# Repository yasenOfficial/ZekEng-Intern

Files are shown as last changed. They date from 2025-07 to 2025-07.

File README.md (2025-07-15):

# Цел на стажа:

Да се направи симулация на вече направена платка за контролиране на вентилатор. Платката гори често и има нужда от оптимизация. Дадени са файлове за Reverse-engineering в `/Files for Reverse Engenieering`

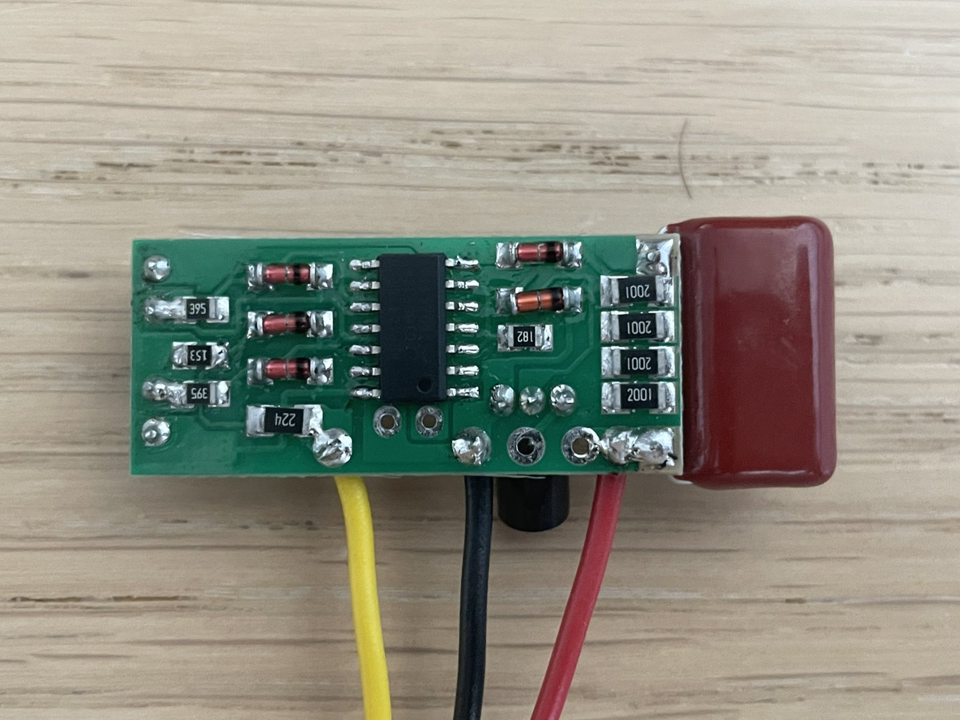
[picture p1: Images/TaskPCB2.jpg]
TaskPCB2

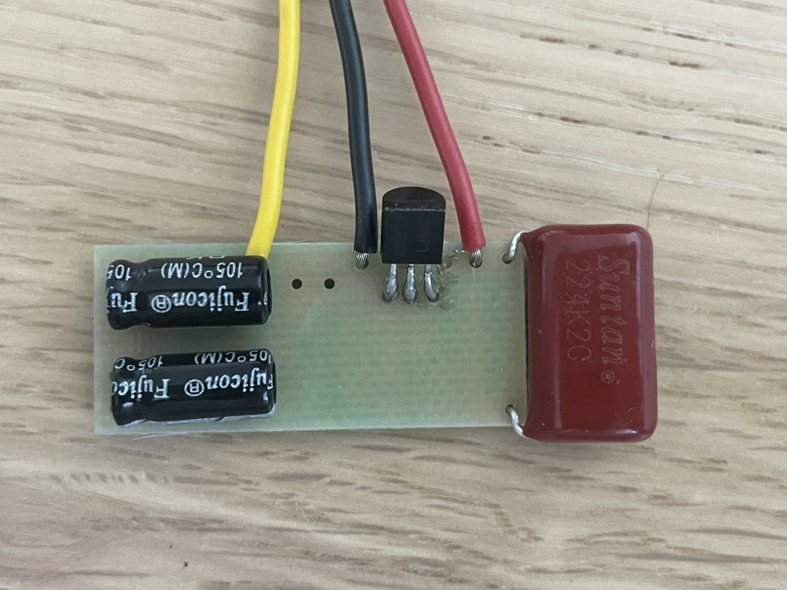
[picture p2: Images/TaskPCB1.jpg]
TaskPCB1


# Ден 1 - 01.07.2025

Запознанство с екипа

Разучаване LTSpice от огромния Роман (Следване на Tutorial-a)

Тutorial-a.......
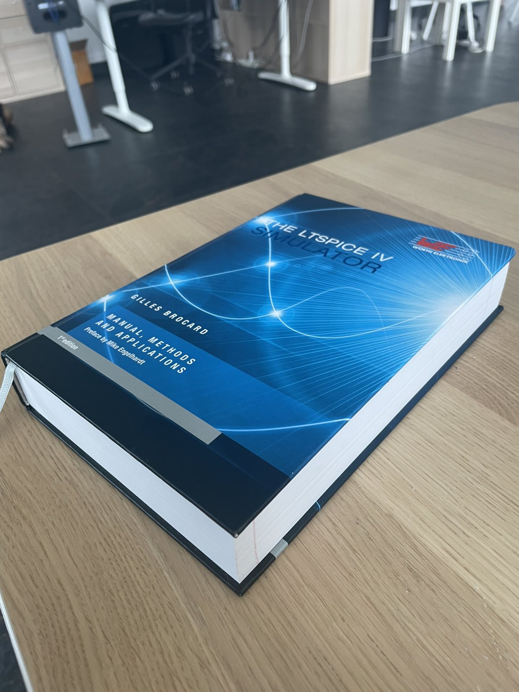
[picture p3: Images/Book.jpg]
Tutorial Book


Работна директория: `LTSpice Files/TutorialRoman.asc`

Покрито в Tutorial-a:
- Поставяне на компоненти
- Свързване
- Поставяне на стойности на компонентите
- Директиви
- Анализ на сигнали

Описание на директивите

## Честотен анализ (.ac)

Изпраща много бавен и много бърз синус (от 1 kHz до 10 MHz) през схемата и измерва колко усилва тя и с колко закъснява сигналът.

`.ac dec 50 1k 10Meg`

dec 50 – логаритмична скала с 50 точки за всяка декада. Т.е. първо разглеждаме честоти от 1 kHz до 10 kHz (1–10 kHz), после от 10 kHz до 100 kHz, после от 100 kHz до 1 MHz и т.н.

1k – начална честота 1 kHz

10Meg – крайна честота 10 MHz

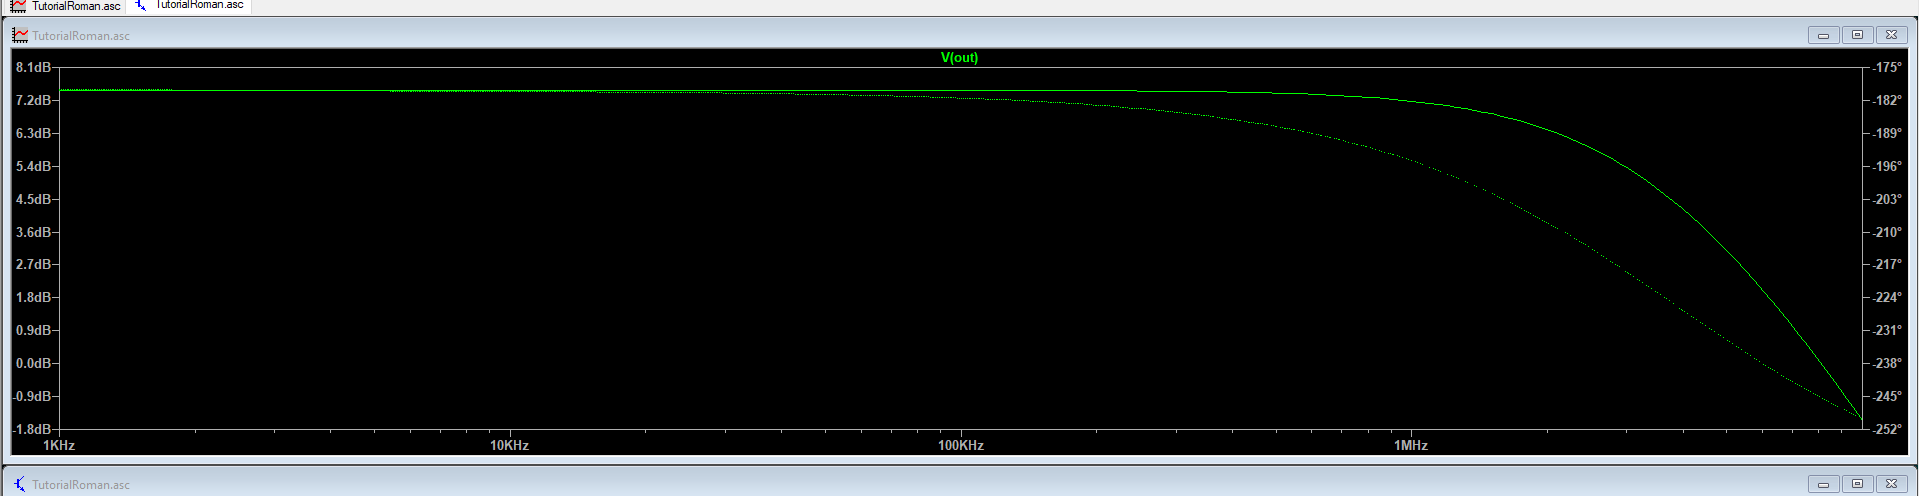
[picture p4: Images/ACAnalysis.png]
ACanalysis


## Транзиентен анализ (.tran)

Проследява как се променят напреженията и токовете във времето (от 0 до 300 µs), записвайки данни след първите 100 µs.

`.tran 0 300u 100u 0.01u`

0 – автоматичен интервал за записване на резултатите

300u – крайно време на симулация 300 µs

100u – начало на записването от 100 µs

0.01u – максимална стъпка 0.01 µs

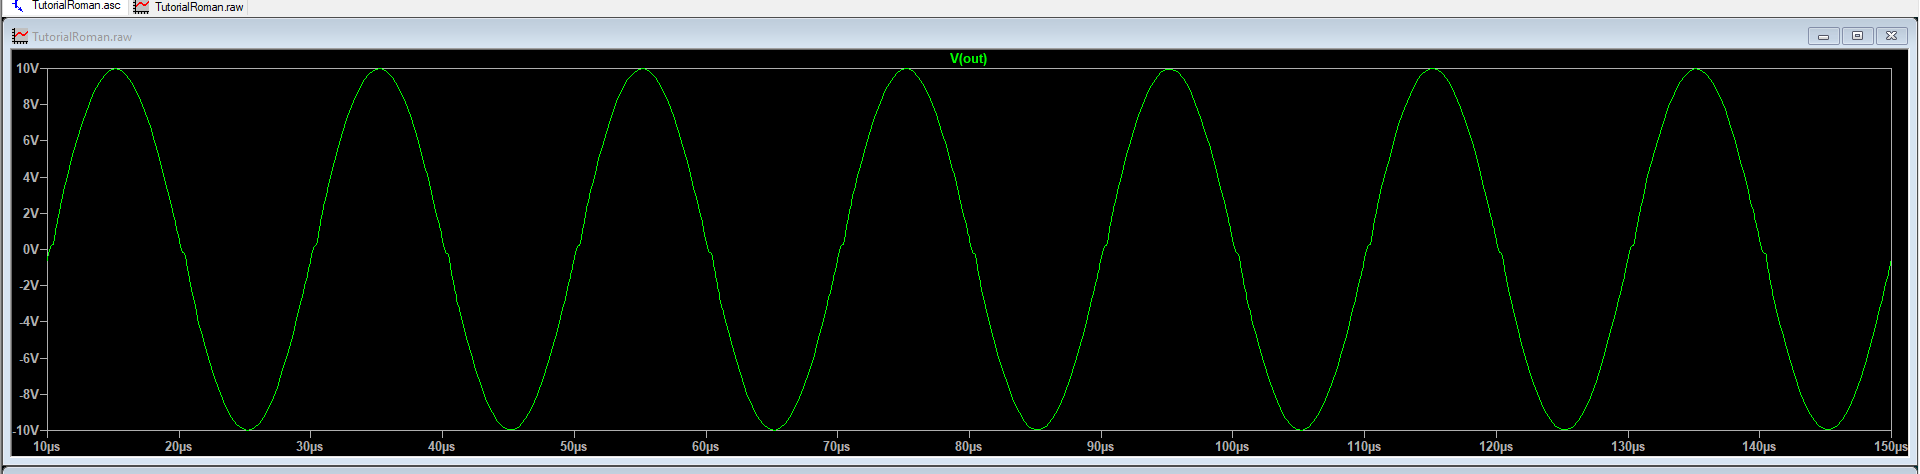
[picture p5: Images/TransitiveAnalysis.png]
TransitiveAnalysis


## Фурие-анализ (.four)

- Взима резултата от временния анализ и го разгражда на отделни синусови вълни (хармоници), за да видим колко „чист“ е сигналът на 500 kHz.

`.four 500k 10V(out)`

500k – основна честота 500 kHz за хармоничен анализ

10V(out) – (10 V при основния хармоник на изхода)

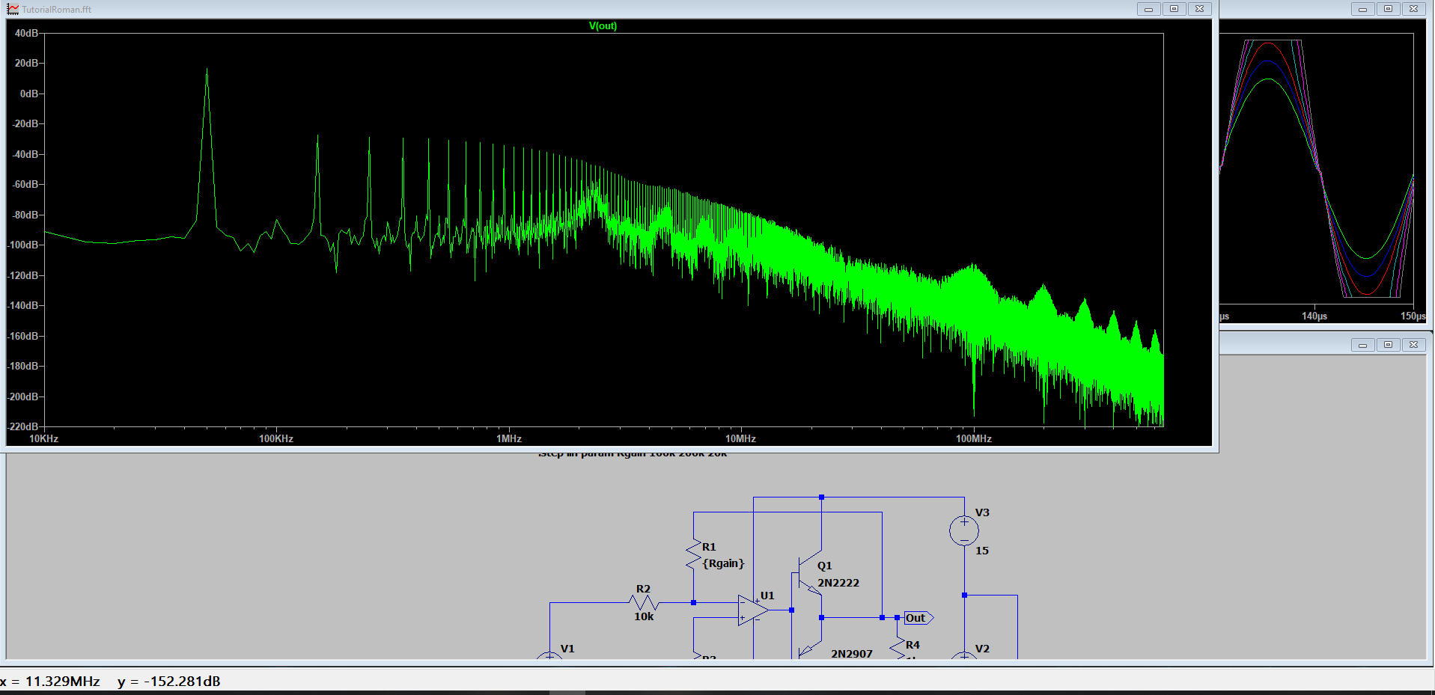
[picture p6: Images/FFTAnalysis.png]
FFTAnalysis


## Параметрично стъпково преминаване (.step)

-  Променя автоматично стойността на резистор Rgain (100 kΩ, 120 kΩ, 140 kΩ… до 200 kΩ) и за всяка стойност пуска пак AC, транзиентен и Фурие-анализите.

`.step lin param Rgain 100k 200k 20k`

Променя стойността на параметъра Rgain от 100 kΩ до 200 kΩ на стъпки по 20 kΩ

За всяка стойност се повтарят горните анализи

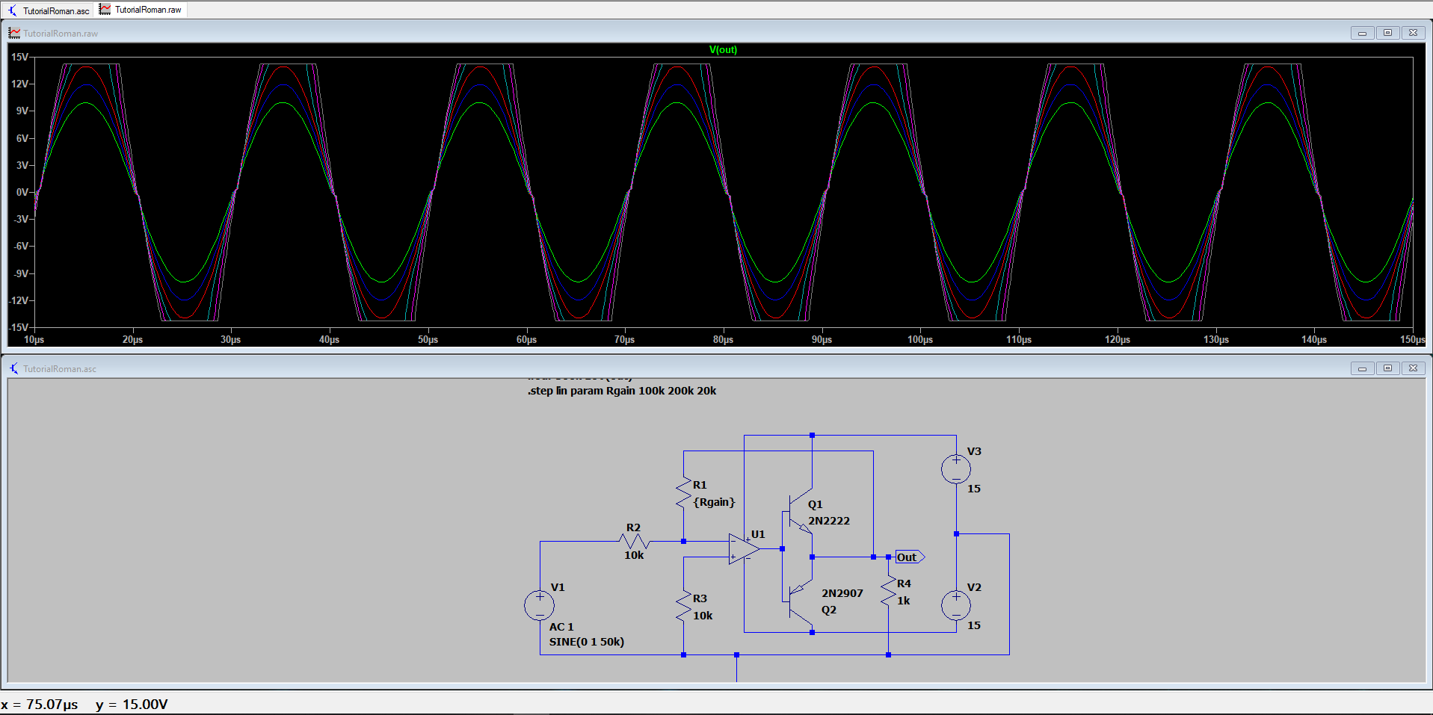
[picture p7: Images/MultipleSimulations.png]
Multiple Simulations


## Идентифициране на дефект

След стартиране на транзиентен анализ в определен момент изходният сигнал се отклонява от очакваната синусоида:

Наблюдение на графиката: Обръща се внимание къде сигналът изкривява или има рязка промяна на наклона.

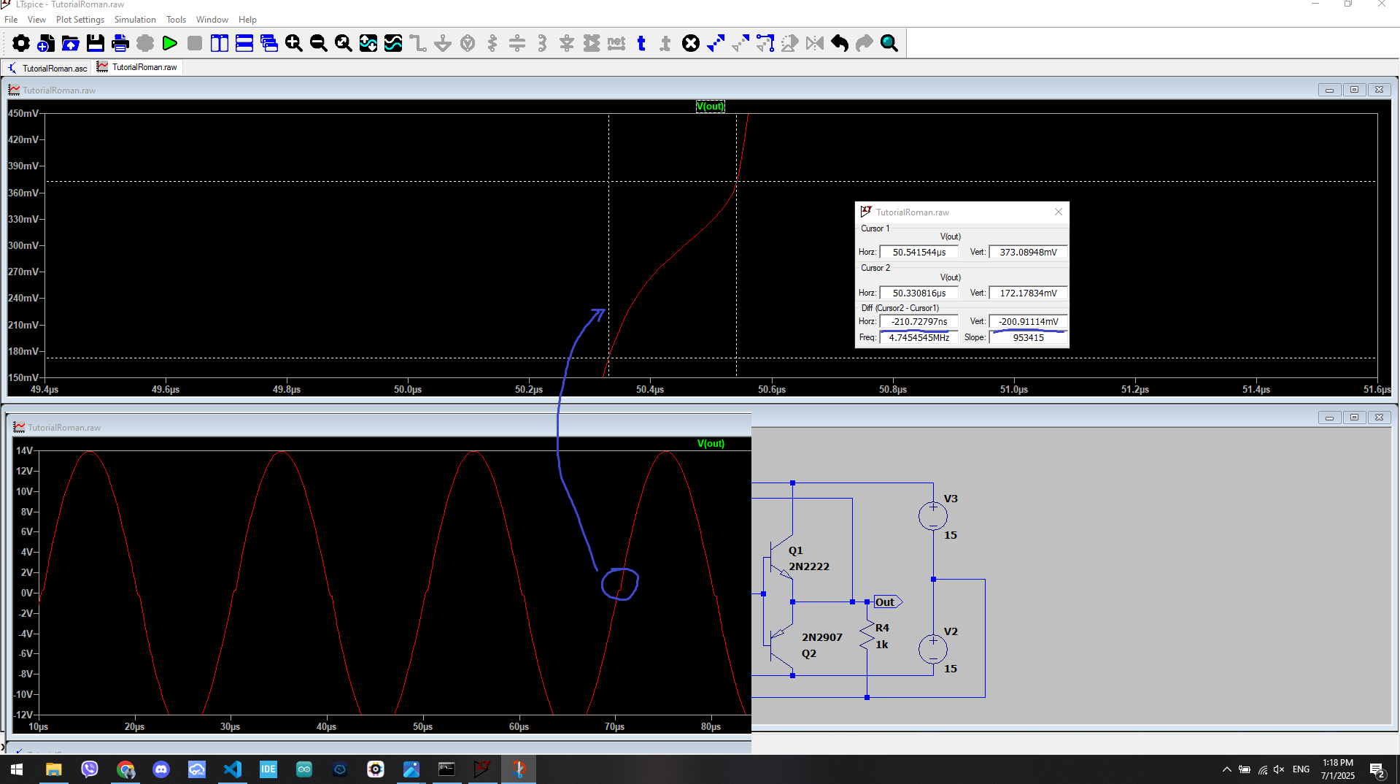
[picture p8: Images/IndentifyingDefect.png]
IndentifyingDefect


Измерване с курсори: Поставят се два курсора преди и в началото на аномалията, за да се изчисли промяната във времето и напрежението.

На операционния усилвател му отнема измеримо време за да покрие съществуващия пад на напреженеие между сумирания VBE на 2та транзистора Q1, Q2

Извод: 3тия сигнал (от 6-те) е минималния приемлив (R1 = 140k) с амплитуда 14V

# Ден 2 - 02.07.2025

## Импортиране на CD4000 серията в LTSpice

`Ventilator\lib\sym\*` `Ventilator\lib\sub\CD4000.lib` 

https://www.amarketplaceofideas.com/adding-series-4000-cmos-library-to-ltspice.htm

## Тестове на NAND 4093B gate

`Ventilator\NAND Tests.asc`

Проведох прост дали NAND gate-a от библиотеката работи със синусоида с амплитуда 12 V

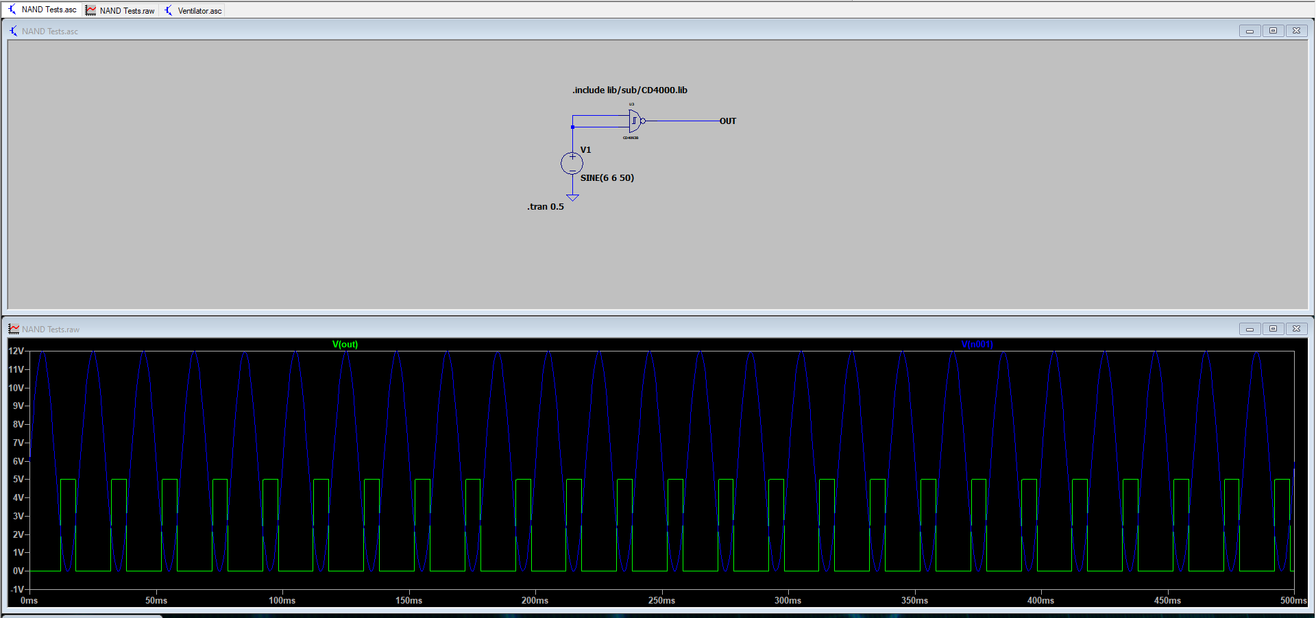
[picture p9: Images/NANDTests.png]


## Тестове и разбиране как работи SW gate-a в LTSpice

Следвах Tutorial-a на Analog Devices:

`Ventilator\SW.asc`

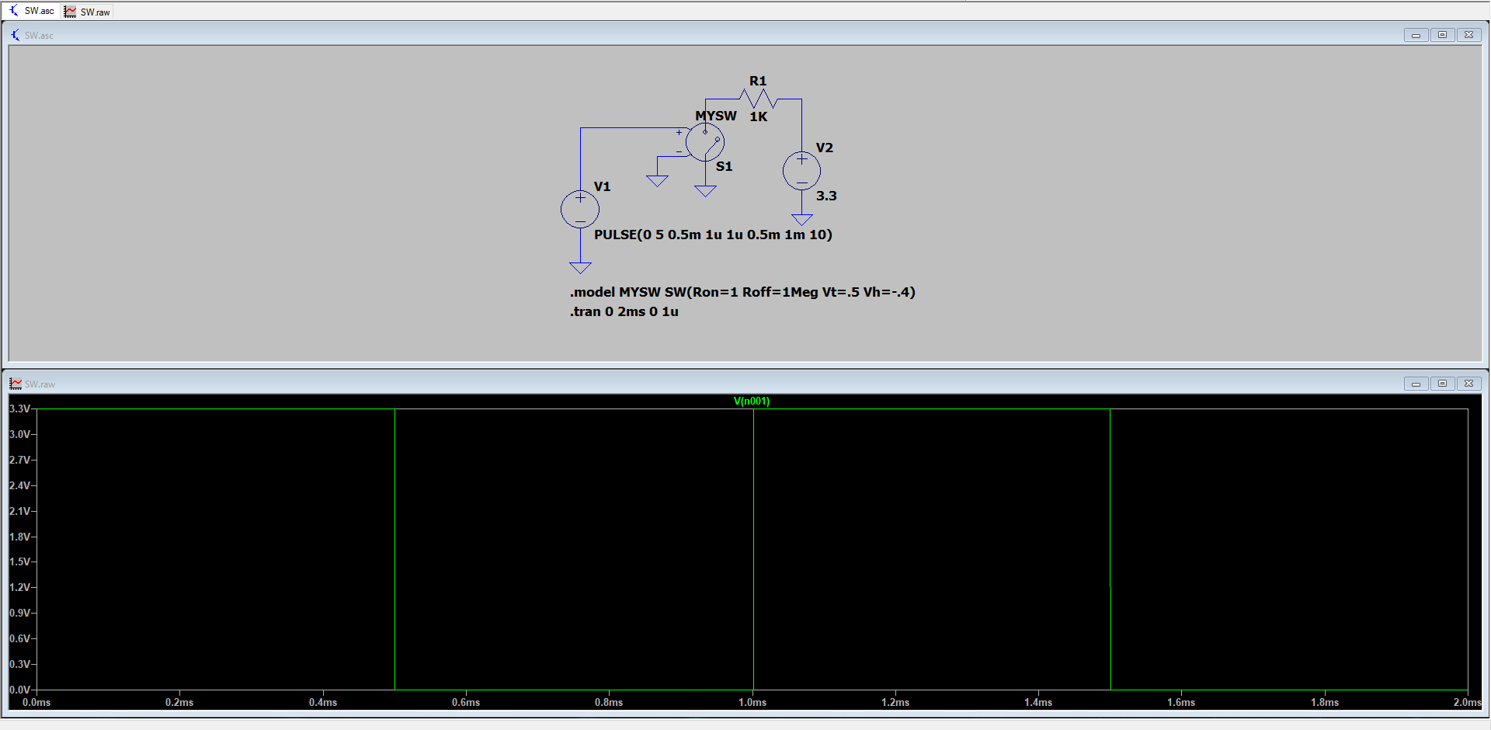
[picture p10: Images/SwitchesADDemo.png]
Switches Demo Implementation


И после направих подобна моя имплементация с резисотри вместо импулсен генератор:

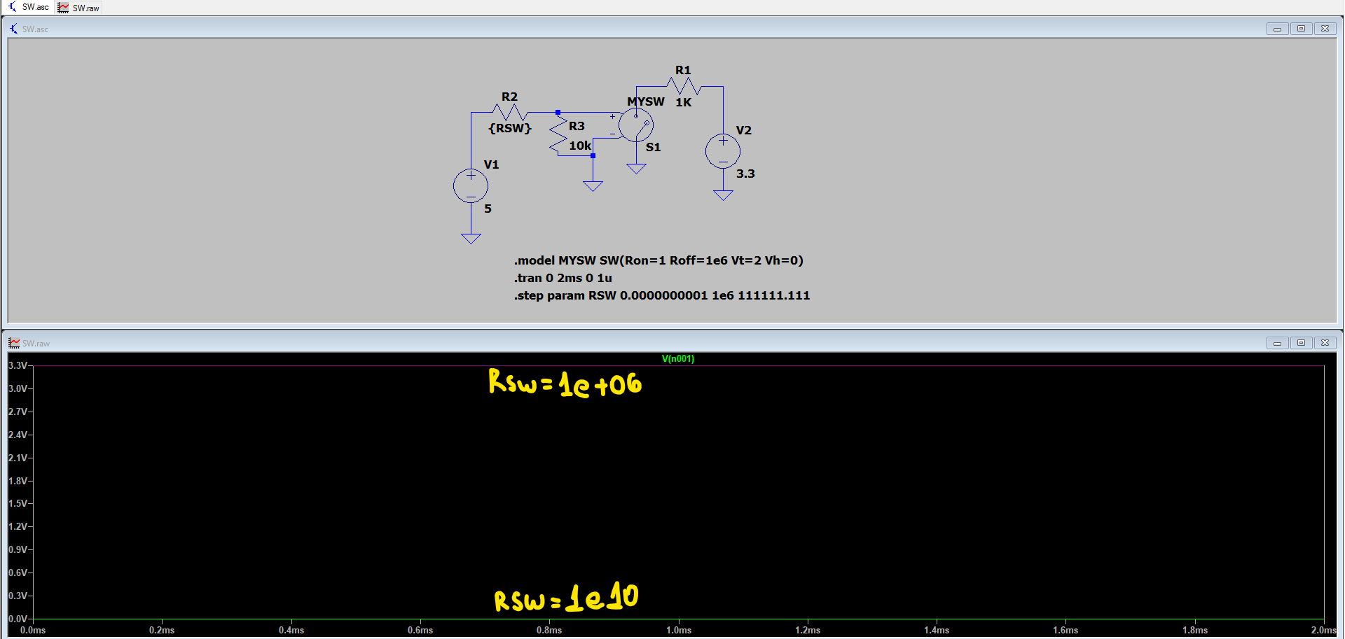
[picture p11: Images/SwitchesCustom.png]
Switches Custom Implementation


## Импортирах и библиотектата с симистора (MAC97A8), който е сложен на платката

`Ventilator\lib\sub\thyristr.lib` 

https://github.com/HMGrunthos/InrushTimer/blob/master/thyristr.lib

## Teстване на захранването на схемата:

`Ventilator\PMU.asc`

Захранвaнето се стабилизира за около 160ms докато стигне 11.3V. После лека полека се покачва до 11.6 в рамките на до 2 секунди

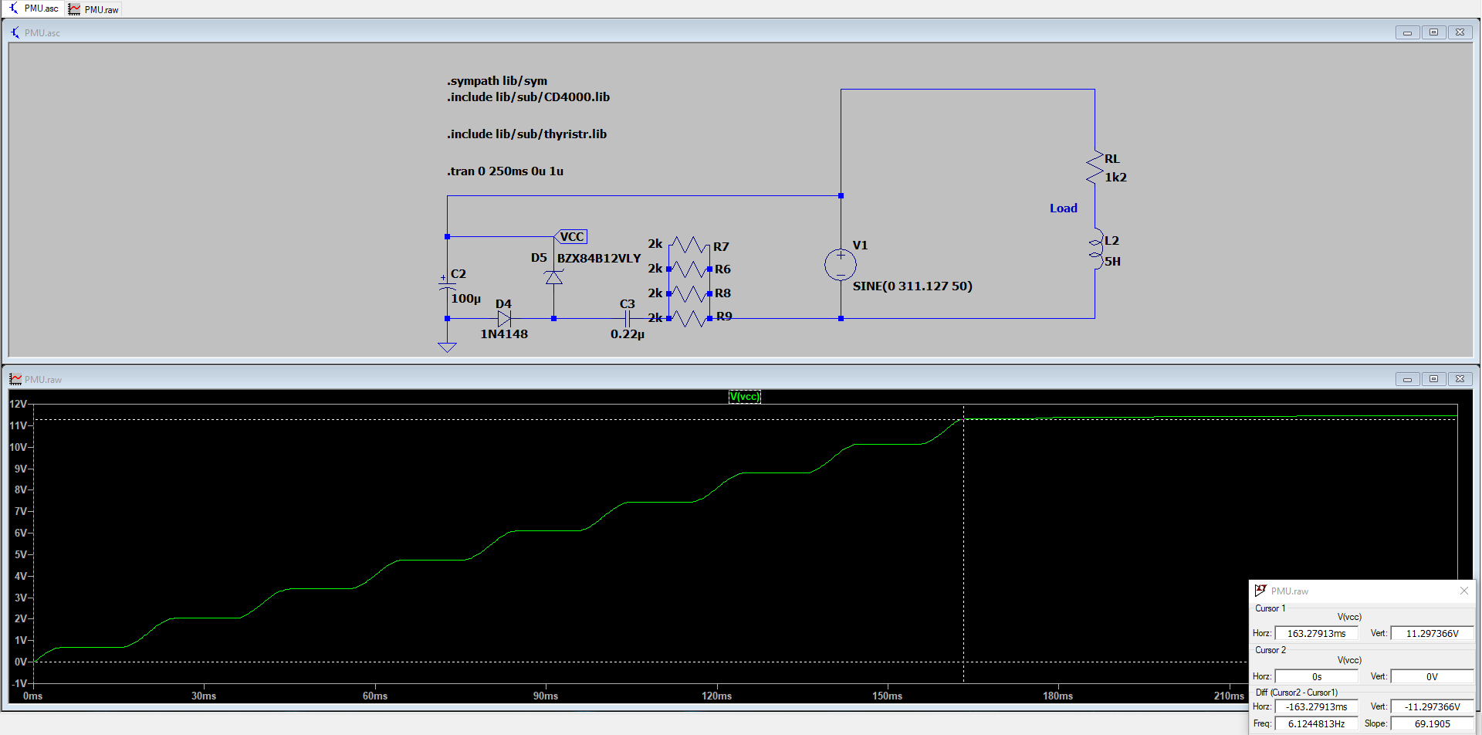
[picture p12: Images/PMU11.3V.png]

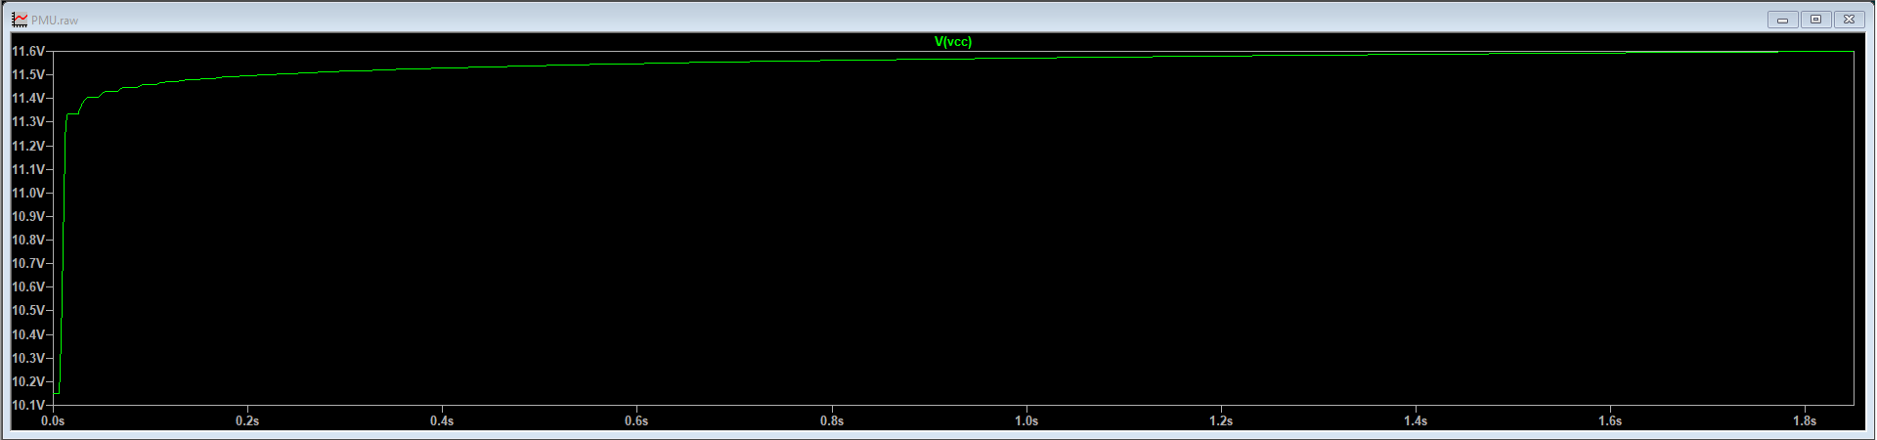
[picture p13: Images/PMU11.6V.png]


Параметри на проблемния кондензатор:

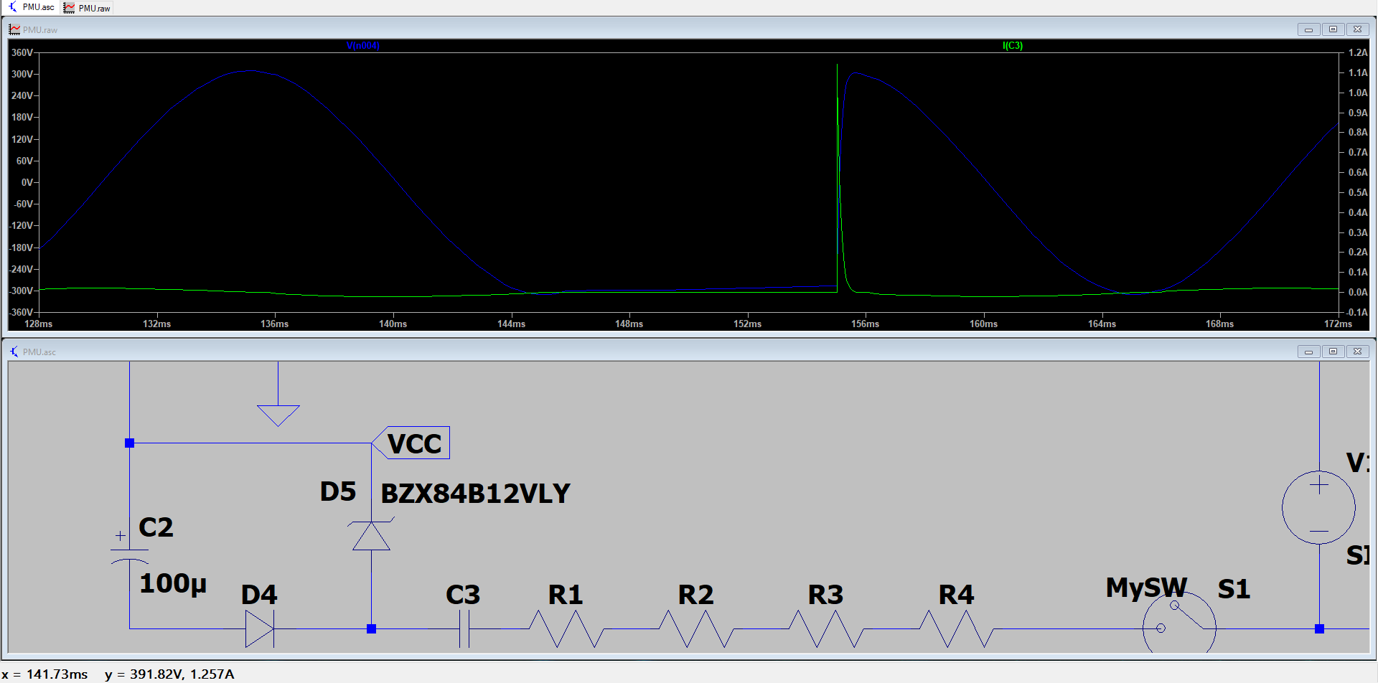
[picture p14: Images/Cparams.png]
C params


Pulse current: Rated for 2 A rms at 1 kHz → Доста повече от 1.2 A
https://www.mouser.bg/ProductDetail/WIMA/FKP1R022205H00KYSD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

Параметри на проблемните резистори:

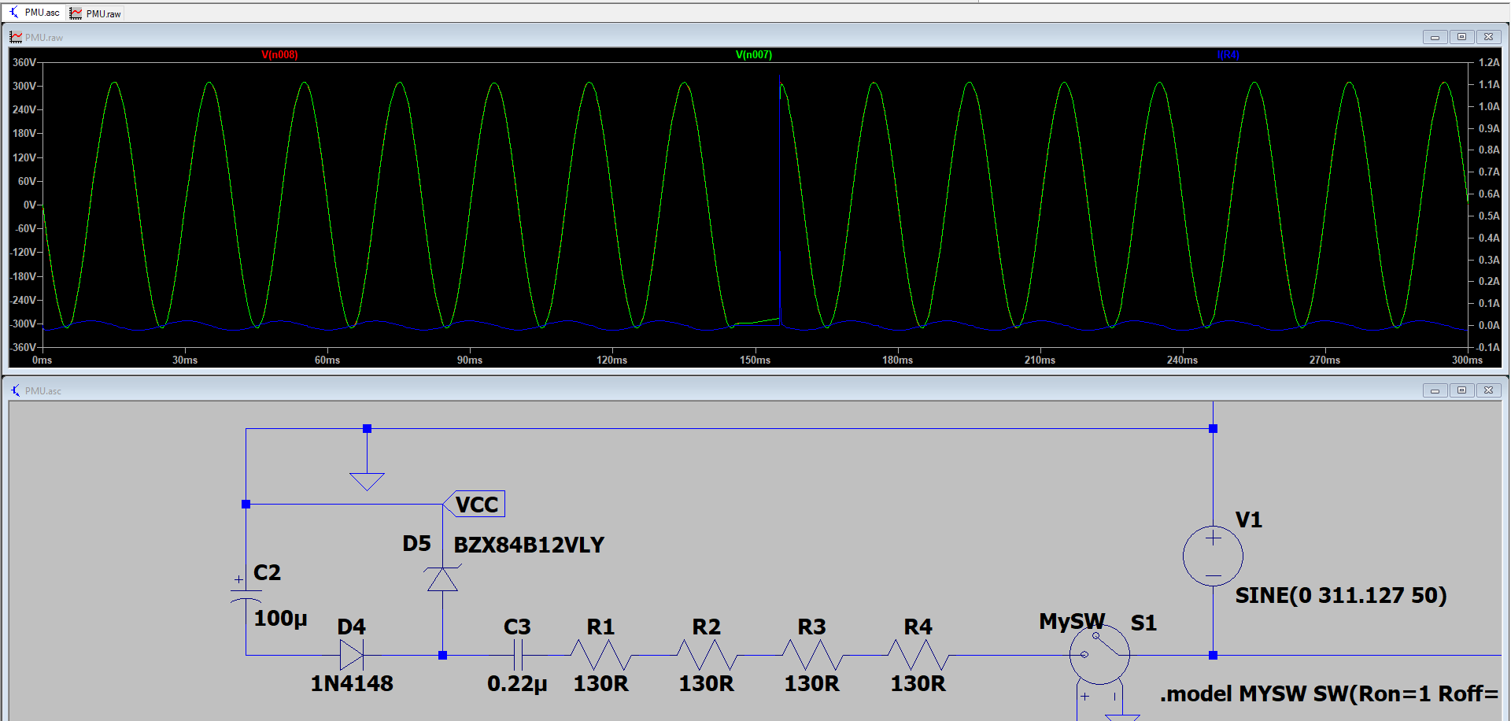
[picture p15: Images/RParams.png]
R params


https://www.mouser.bg/ProductDetail/ROHM-Semiconductor/ESR18EZPJ131?qs=493kPxzlxfJ2i%2Fymb6BOsw%3D%3D

# Ден 3 - 03.07.2025

Започната е работа по схемата:

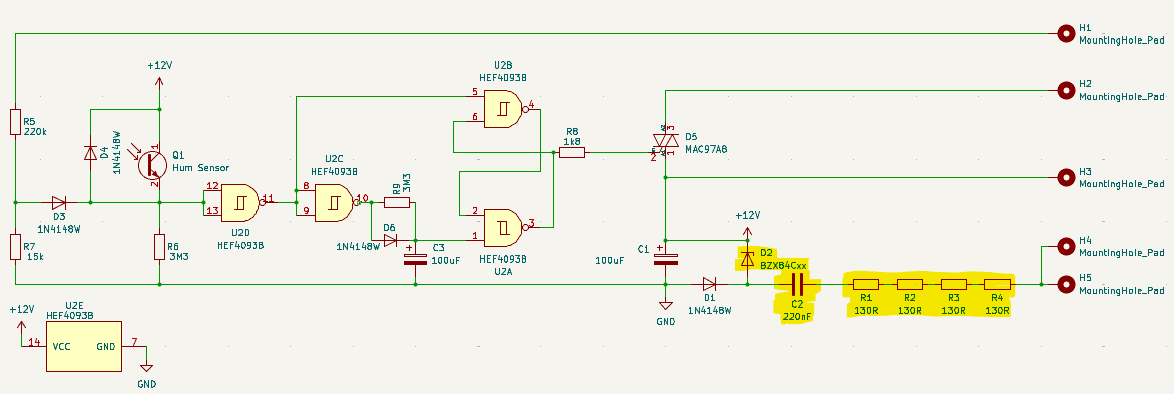
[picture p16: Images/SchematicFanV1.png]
SchematicFanV1


- сменен е 220nF-овия кондензатор, избрания от вчера (02.07.2025 се оказва голям за платка (трябва да се събера в 14.5mm x 32.5mm))

https://www.mouser.bg/ProductDetail/WIMA/MKP4J022203C00KI00?qs=sJjjjplDs9tWJMp1Tfr4Pw%3D%3D

- сменена е топологията на резисторите (вече са последователни, а не паралелни)
- избран е нов ценеров диод, тъй като стария е неизвестен

Започната е работа по платката:

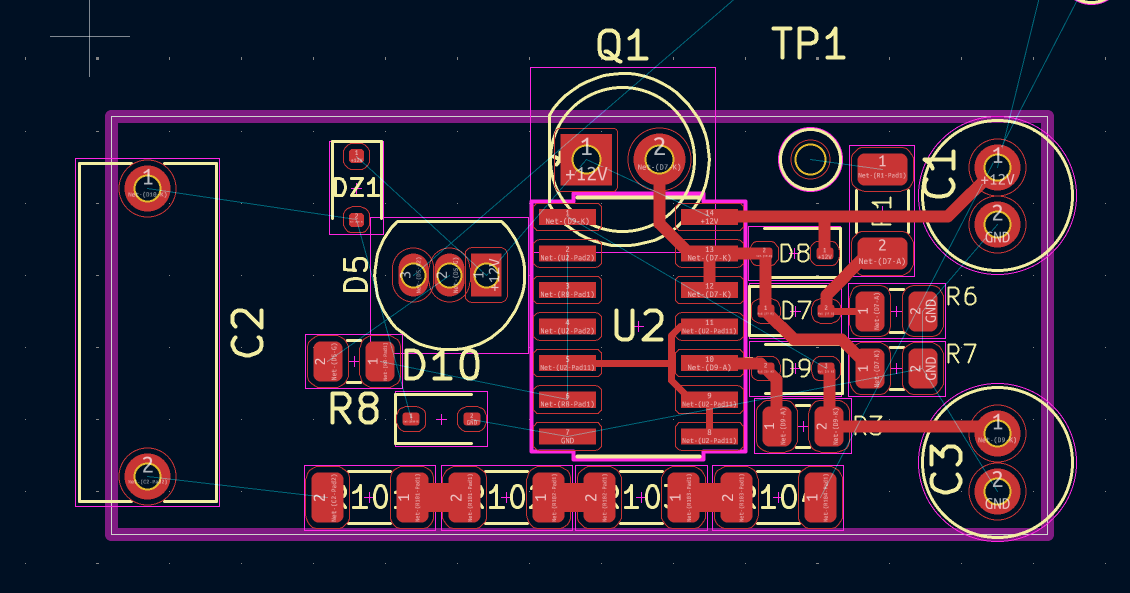
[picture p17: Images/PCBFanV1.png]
PCBFanV1


Начерах Custom TP, Diameter 2.0mm, drill 1.0mm, Pad само на свързана страна
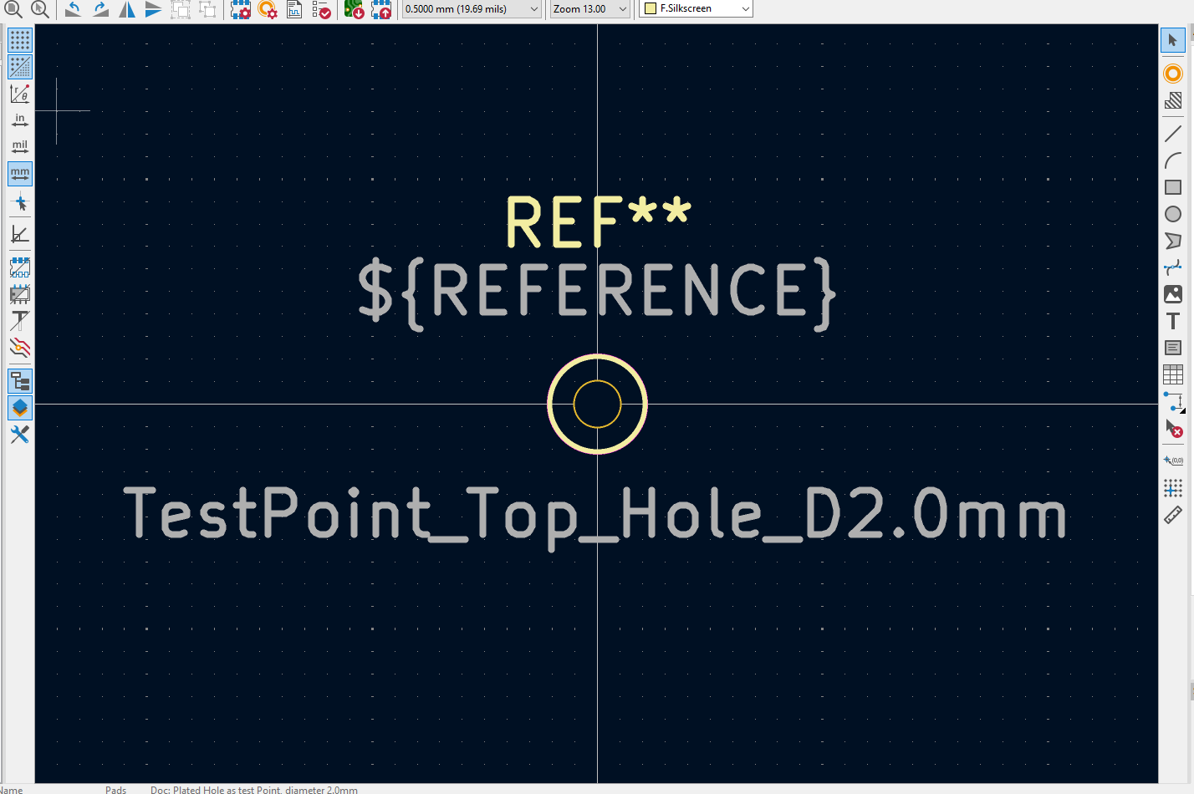
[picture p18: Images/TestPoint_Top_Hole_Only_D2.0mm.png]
TestPoint_Top_Hole_Only_D2.0mm


Платката и схемата за предадени за обратна връзка на екипа от ЗекЕнг, със сигурност трябва да се добави медна зона за земя (GND) и да се оправи place-ment-a на резисторите R21, R22, R23, R24
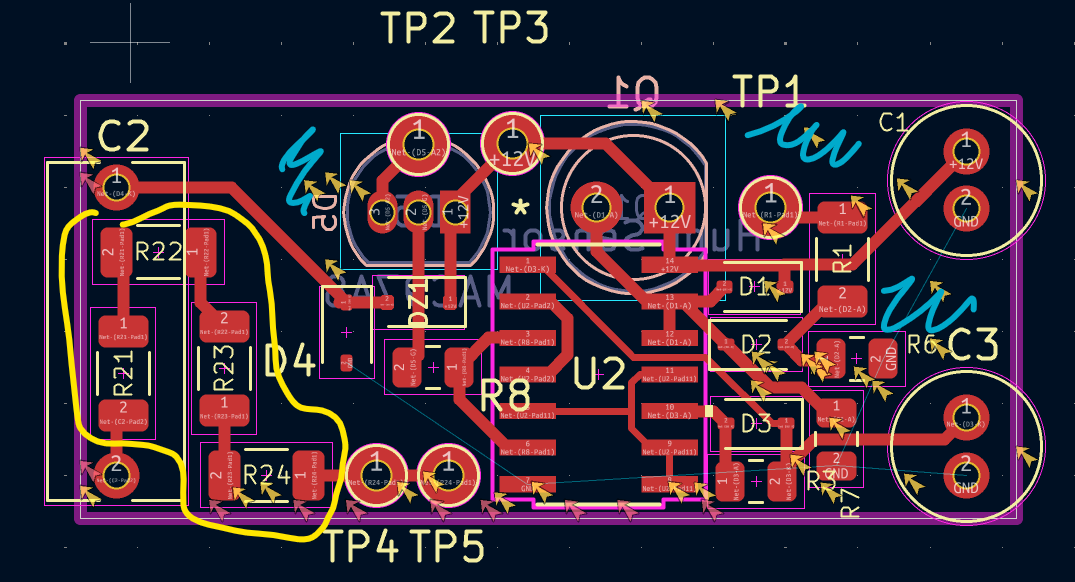
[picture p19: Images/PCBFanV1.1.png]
PCBFanV1.1


(Това е много бърза версия на платката)

Oбратна връзка:

- Да се начертае как ще легнат кондензаторите 2x (100uF)
- Да се сложат кондензаторите от другата страна 2x (100uF)
- Да се оправи символа и footprint-a на Hum Sensor-a, за да изглежда по-добре
- Да се оправят R21, R22, R23, R24 (Да се внимава с напрежението там)
- Да се направи TP с 1.8mm Diam. x 1.1 Drill
- Да проверя pinout-a на симистора
- Засега да изчакам с медните зони (може и просто да свържа земята на ръка)
- Очаквам Feedback за избрания кондензатор и ценер

# Ден 4 - 04.07.2025

~~ - Да се начертае как ще легнат кондензаторите 2x (100uF) ~~
~~ - Да се сложат кондензаторите от другата страна 2x (100uF) ~~
~~ - Да се оправи символа и footprint-a на Hum Sensor-a, за да изглежда по-добре ~~
~~ - Да се оправят R21, R22, R23, R24 (Да се внимава с напрежението там) ~~
~~ - Да се направи TP с 1.8mm Diam. x 1.1 Drill ~~
- Да проверя pinout-a на симистора 

- Кондензатора имаше грешка бях избрал 0.022uf (22nf) вместо 0.22uf (220nf)
- Ценера е добре

Платката е приключена, предавам за проверка и обратна връзка:

- начертан е нов footprint за 220nf-вия кондензатор, за да може да support-ва няколко различни корпуса. (3D модела е също съответно променен)
- начертан е нов footprint за 100uf-вите кондензатори, за да се види как ще изглеждат реално като са легнали. (3D модела е също съответно променен)

- компонентите са пренаредени, за да може падовете за връзка с вентилатора да не са под 100uf-вите кондензатори
- сменен е модела на 220nf-вия кондензатор (да не е 22nf) - https://www.mouser.bg/ProductDetail/WIMA/MKP4J032204J00KSSD?qs=sJjjjplDs9tNFMTkeYgn1g%3D%3D

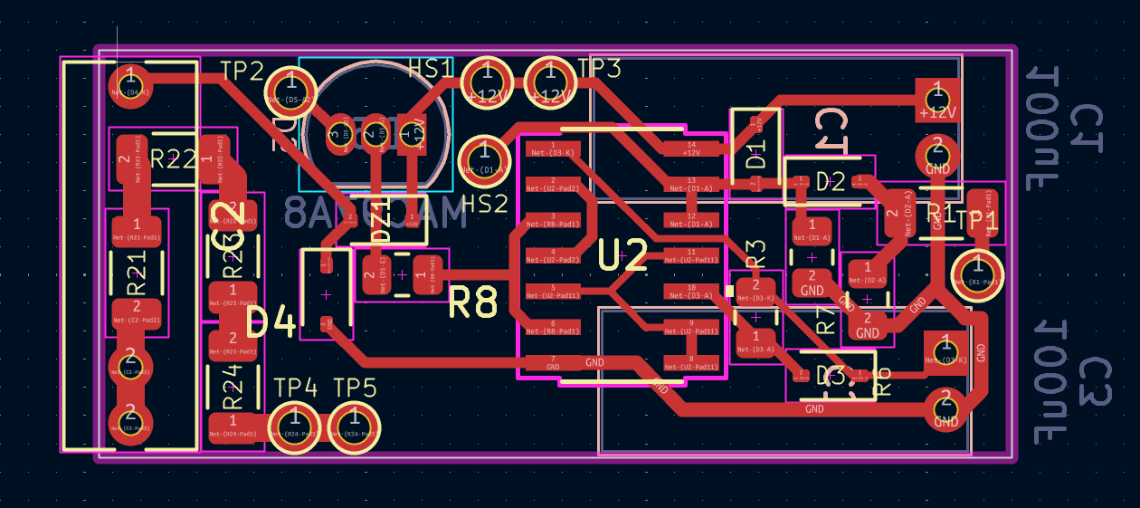
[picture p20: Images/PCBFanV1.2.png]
PCBFanV1.2

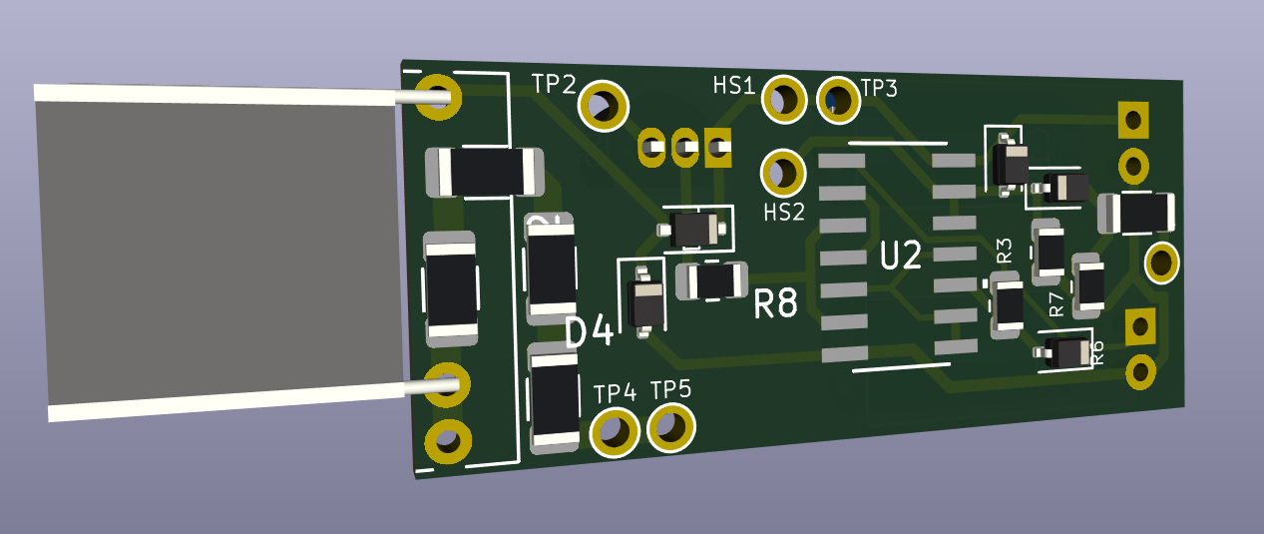
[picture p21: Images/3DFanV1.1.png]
3DFanV1.1

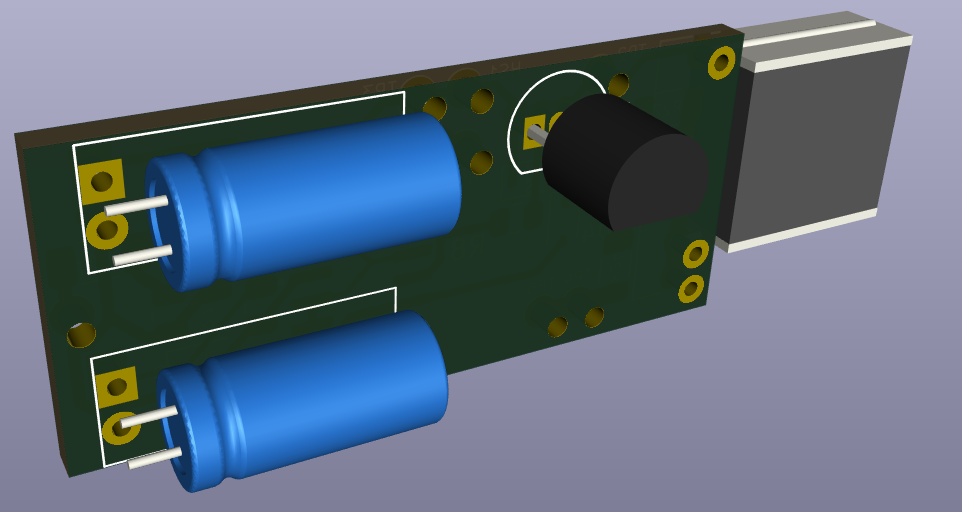
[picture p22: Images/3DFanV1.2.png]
3DFanV1.2


# Ден 5 - 07.07.2025

Проверих pinout-а на симистора. Оказа се грешен. поправих го.
Експортирах файлове за fabrication - `Gerbers.zip`
Платката беше пусната за производство в hardtech.

Също така оформих Bill of Materials, за да се поръчат компоненти. Пуснат е на екипа от ЗекЕнг.

Изчислих цената на платка при прозизводство на 25 платки (сегашния прототип) и при 1000 платки (масово производство).

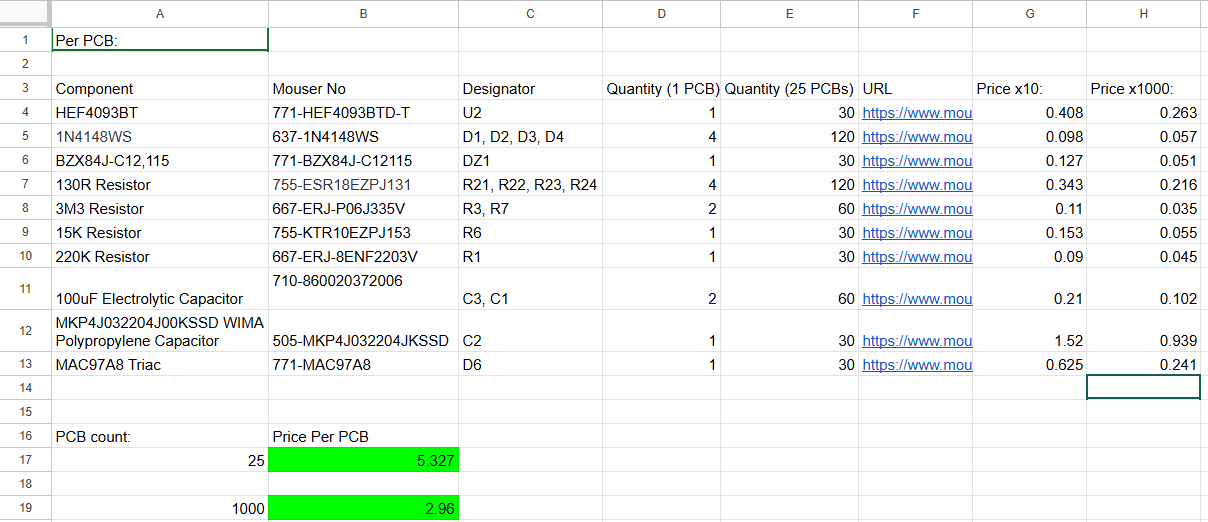
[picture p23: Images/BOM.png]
BOM


Нужно е подобрение на сегашния сензор за влага. Той работи на принципна на мерене са съпротивление.
В момента е покрит с латекс. Латекса се мие и не издържа на влага. Наложи се да направя research и според мен материала, с който трябва да се покрие сензора е полимид, защото е хидрофилен материал.
Интересното е че flex-PCBs се правят от полимид, но тогава сензора би станал много скъп.

# Ден 6 - 08.07.2025

Още research за материала за сензора:

`HumSensorResearch/Polyaniline_based_impedance_humidity_sen.pdf`

PANI ^, материала е скъп и прави твърде голямо съпротивление, но иначе изглежда като нелошо решение.

https://www.conservationlabinternational.com/product-page/polyvinylalcohol-pva

Другия вариант е този тип алкохол.

Оказва се, че платката би била най-издръжлива ако е направена от карбон

Сензора трябва да е от е със номинално съпротивление 1.8Mohm и при 100% влажност трябва да падне на 1Mohm (Измервания от сегашния сензор)

Докато чакаме платките да се произведат имам задачата да подкарам този dev board и да направя audio reverb effect.

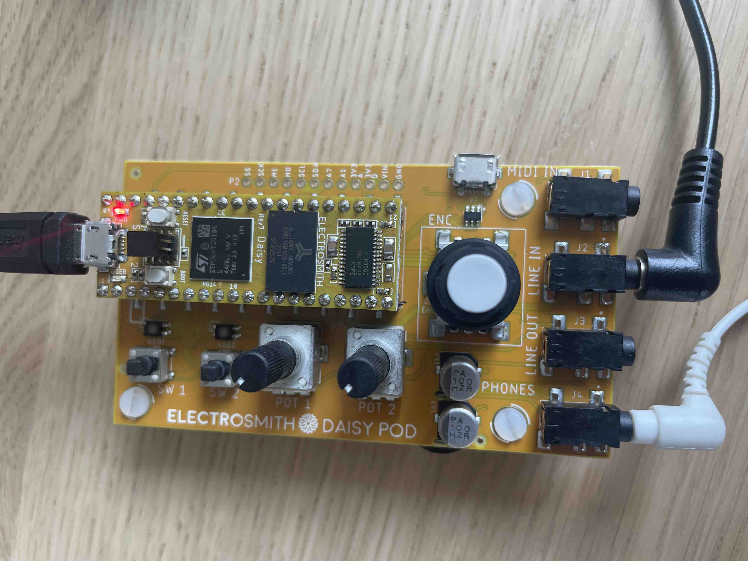
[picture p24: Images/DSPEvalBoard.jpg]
DSPEvalBoard


Следвам setup guide-a:

https://daisy.audio/tutorials/cpp-dev-env/#4a-flashing-daisy-via-usb

Blink:

https://github.com/user-attachments/assets/fd17b43d-5868-410e-99cb-3dca0cbfa887

# Ден 7 - 09.07.2025

Продължение с DSP-то:

Написах output на прост сигнал с Reverb - `DaisyExamples/pod/Reverb`

https://github.com/user-attachments/assets/809b711f-6c32-4bfa-b9f2-1e61ffa9d363

Написах Passthrough (Минава сигнал от компютъра без processing през платката и го изкарва на слушалките) - `DaisyExamples/pod/Passthrough`

https://github.com/user-attachments/assets/3d5a9c95-f11f-47a7-a7cd-25c1624e9f36

Написах Passthrough Reverb (Минава сигнал от компютъра с reverb през платката и го изкарва на слушалките) - `DaisyExamples/pod/PassthroughReverb`

https://github.com/user-attachments/assets/ea0f91bf-7a43-4274-871f-e3ecebe81c51

Започвам research-a по конволуции. Това видео доста помогна: https://www.youtube.com/watch?v=KuXjwB4LzSA

Каква е целта?

Трябва да се вземе .wav от интеренет на Impulse Response и да се симулира чрез DSP-то същата конфигурация на входния сигнал.

В `DaisyExamples\pod\Convolution\mono files` има качен `tunnel_entrance_f_1way_mono.wav` - това е Impulse Response-a

Run-ваме тази команда:

```sox tunnel_entrance_f_1way_mono.wav -r 48000 -b 24 -c 1  tunnel_entrance_48k.wav  gain -n -3  rate -v```

- Прави output sample-rate-а на 48 000 Hz - (native rate-a на Daisy платката).
- Пикова амплитуда –3 dBFS
- Resample-ва с най-high-quality filter-a на SOX

и получавам `out48.wav`

Ще използвам този файл за конволуция на входа.

----------------

Странен проблем. При няколко serial print-a замръзва и принтира само първия. Сигурно трябва да се изчака или да се flush-не buffer-a.
```
hw.PrintLine("A");
hw.PrintLine("B");
hw.PrintLine("C");
hw.PrintLine("D");
hw.PrintLine("E");
```

fix:
```hw.DelayMs(1);```

Не мога да mount-на SD картата като хората - не мога да достъпя IR/out48.wav да го прочета

```
DIR     dir;
        FILINFO fno;
        if(f_opendir(&dir, "/IR") == FR_OK)
        {
            while(f_readdir(&dir, &fno) == FR_OK && fno.fname[0])
            {
                hw.PrintLine("File: %s", fno.fname);
            }
            f_closedir(&dir);
        }
        else
        {
            hw.PrintLine("Failed to open /IR");
        }
```

Намирам `File: out48.wav` като list-на Dirs, но не мога да го прочета като хората.

----------------

Изникна по-спешна задача - наложи се да се разглобя друг вентилатор и да видя какъв е сензора вътре, за да се използва същия в моята платка, вместо да търсим адекватен хидрофилен материал за покритие.

![HR202](https://github.com/yasenOfficial/ZekEng-Intern/blob/main/Images/HR202.jpg)

Това е сваления сензор ^

Проблема с хидрофилния материал е, че никъде не е записано съпротивлението спрямо площта на покритие при дадена дебелина на нанасяне.

Затова сменихме концепцията и поръчахме този сензор.

https://lcsc.com/search?q=HR202&s_z=n_HR202

# Ден 8 - 10.07.2025

Наложи се да имплементирам собствена flush функция за буфера за принтиране и да прекомпилирам libDaisy съответно.

```logger.h

    static void Flush();
```

```logger.cpp

template <LoggerDestination dest>
void Logger<dest>::Flush()
{
    if(tx_ptr_ > 0)
    {
        TransmitBuf(); // will send and clear the buffer
    }
    // Ensure buffer is cleared, even if transmission failed.
    tx_ptr_ = 0;
}
```

Вече имам нормални принтове:

```
f_open succeeded!
First 16 bytes, read 0 bytes:
```

Но не чете байтове от файла ми. Тествах `pod\WavPlayer\WavPlayer.cpp` и работеше. Ще се опитам да репликирам подобно в моя код.

Написах `TestWav.cpp`, там работи не мога да разбера защо нe работи в `Covnolution.cpp`

# Ден 8 - 11.07.2025

ПРОЧЕТОХ .wav файл-а `f_read == FR_OK`!

```
---- Reopened serial port COM4 ----
Found: 'System Volume Information'
---
Found: 'KriskoTest.wav'
---
Found: 'out48.wav'
---
Found: 'test.txt'
---
Impulse Response file size: 480080
WOHOOO!
```

Стойностите от Hex Viewer-a съответстват на изпринтените:

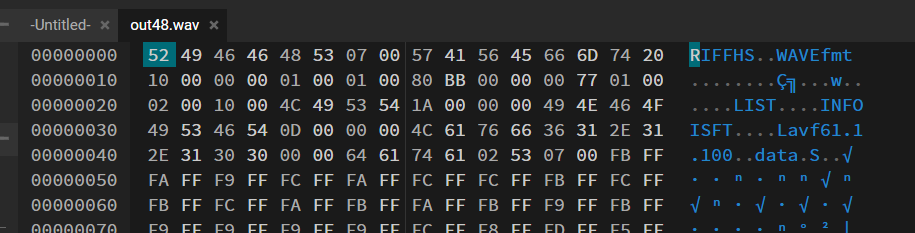
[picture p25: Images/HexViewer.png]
HEXViewer


```
Impulse Response file size: 480080
f_read == FR_OK
Byte[00]: 0x52 (82)
Byte[01]: 0x49 (73)
Byte[02]: 0x46 (70)
Byte[03]: 0x46 (70)
Byte[04]: 0x48 (72)
Byte[05]: 0x53 (83)
Byte[06]: 0x07 (7)
Byte[07]: 0x00 (0)
Byte[08]: 0x57 (87)
Byte[09]: 0x41 (65)
Byte[10]: 0x56 (86)
Byte[11]: 0x45 (69)
Byte[12]: 0x66 (102)
Byte[13]: 0x6D (109)
Byte[14]: 0x74 (116)
Byte[15]: 0x20 (32)
Byte[16]: 0x10 (16)
Byte[17]: 0x00 (0)
Byte[18]: 0x00 (0)
Byte[19]: 0x00 (0)
Byte[20]: 0x01 (1)
Byte[21]: 0x00 (0)
Byte[22]: 0x01 (1)
Byte[23]: 0x00 (0)
Byte[24]: 0x80 (-128)
Byte[25]: 0xBB (-69)
Byte[26]: 0x00 (0)
Byte[27]: 0x00 (0)
Byte[28]: 0x00 (0)
Byte[29]: 0x77 (119)
Byte[30]: 0x01 (1)
Byte[31]: 0x00 (0)

```

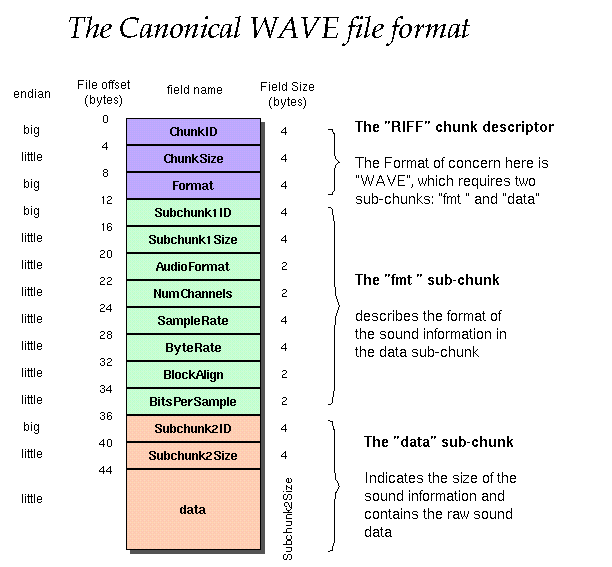
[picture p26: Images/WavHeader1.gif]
WavHeader

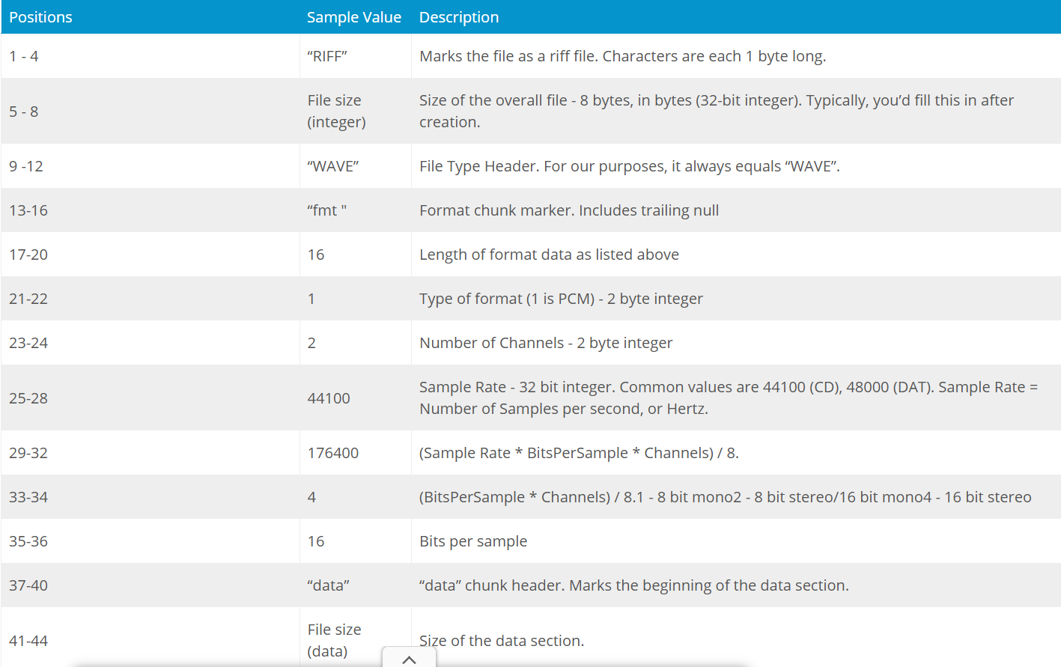
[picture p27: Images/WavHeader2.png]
WavHeader


Интересното е че `data` не винаги седи на 37-40 byte. 
Output: `data_id: 'LIST' (expected: 'data')`

WAV файловете са базирани на RIFF формат, който може да съдържа множество фрагменти.

Минимумът е:

Header `RIFF`

chunk `fmt` (информация за формата)

chunk `data` (аудио данни)

Но: Много инструменти добавят допълнителни фрагменти като `LIST` (метаданни), `bext` (разширение за излъчване) и др.

Трябва да се добави функция за динамично намиране на data-та

`Parse_Header`
Разглежда header-a, търсейки chunks `fmt` и `data` навсякъде в първите N байта.
Връща true при валиден WAV header (RIFF/WAVE, и двата chunka са намерени).

Вече получаваме адекватна информация от header-a:
```
Impulse Response file size: 480080
RIFF: RIFF
File size: 480072
WAVE: WAVE
fmt : fmt 
Audio Format: 1
Channels: 1
Sample Rate: 48000
Byte Rate: 96000
Block Align: 2
Bits Per Sample: 16
data: data
Data Size: 480002
Data Offset: 78
``` 

Следващата стъпка е да се пренашише същия файл и да се сравни с Audacity с оригиналния - `bool WavFile::WriteAsNewFile(const char* filename, const uint8_t* originalFileBuffer) const`

За момента записвам header-a като хората, но не мога да копирам data-та.

# Ден 9 - 13.07.2025 (Помолих да взема DSP-то за вкъщи, за да работя Неделя, зашото понеделник имам ангажимент с родителите ми)

Реших да изчистя main функцията, като направя друга, която отваря файла и го чете.
Интересното е, че функция освен main не може да инициализира локална променлива от тип FIL. 
След много дебъг се оказа, че FIL променливите трябва да са глобални.

Вече имам фунцкия, която копира от един файл в друг, като ръчно чета header-a и самите данни и ги пиша на ръка, за да верифицирам, че данните, които чета са легитимни.

Опит да направя да конволюция.

# Ден 10 - 15.07.2025

Платките и компонентите пристигнаха днес.

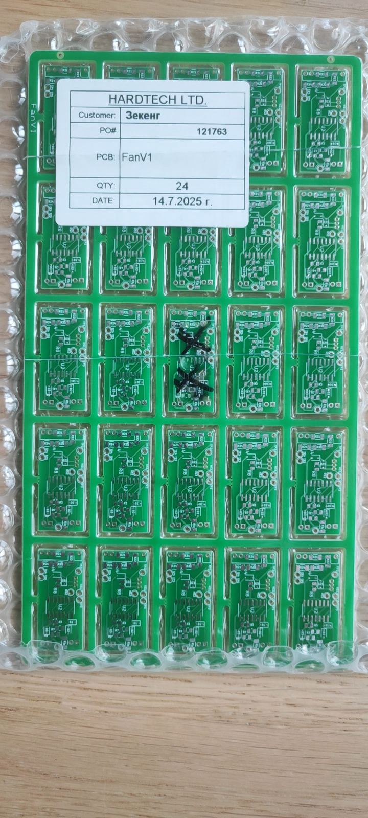
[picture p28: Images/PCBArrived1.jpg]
PCBArrived1

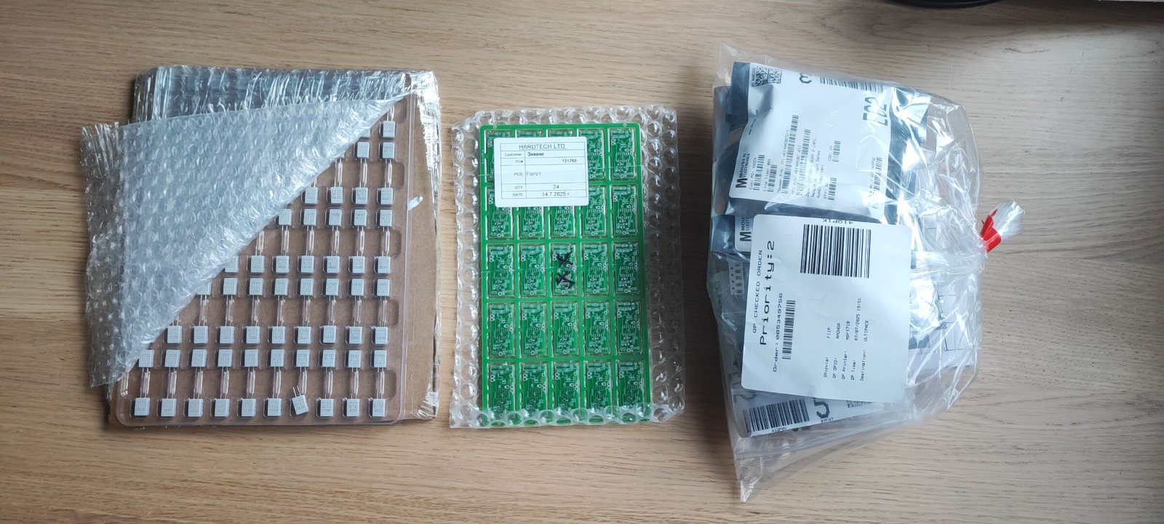
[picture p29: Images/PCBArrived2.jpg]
PCBArrived2


Съответно успях да запоя 3 бройки точно преди оценяването днес.

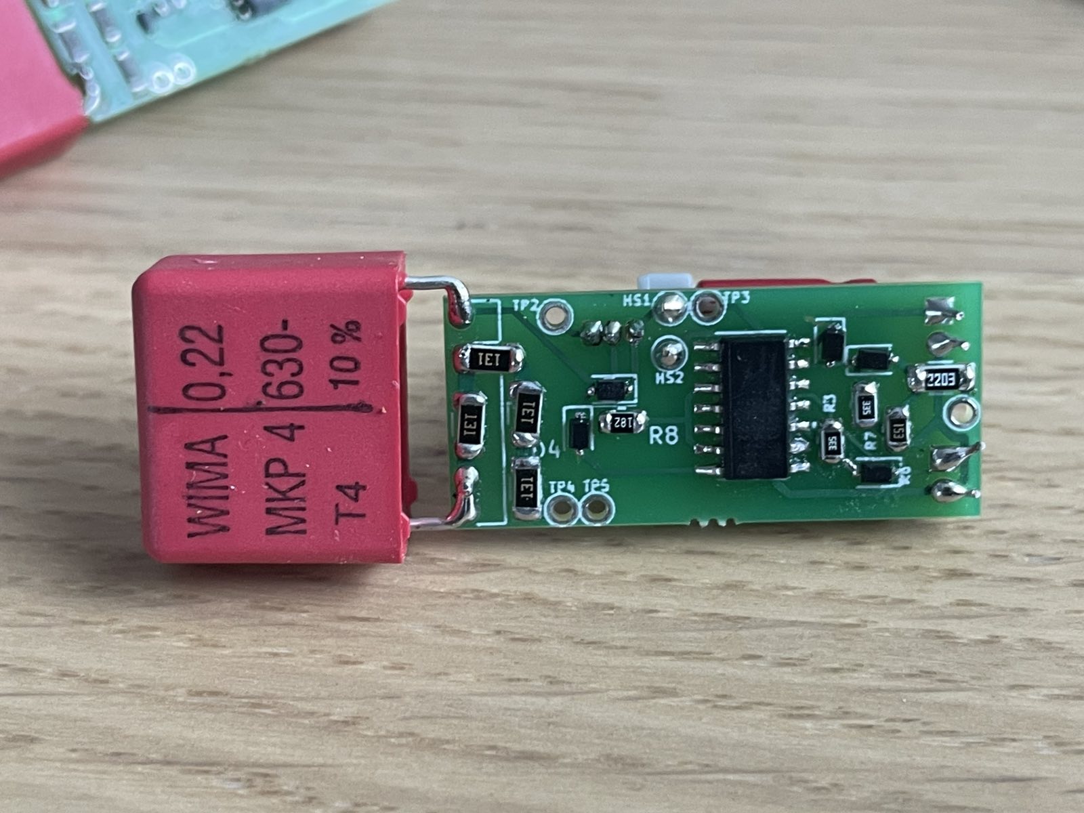
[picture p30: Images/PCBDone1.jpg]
PCBDone1

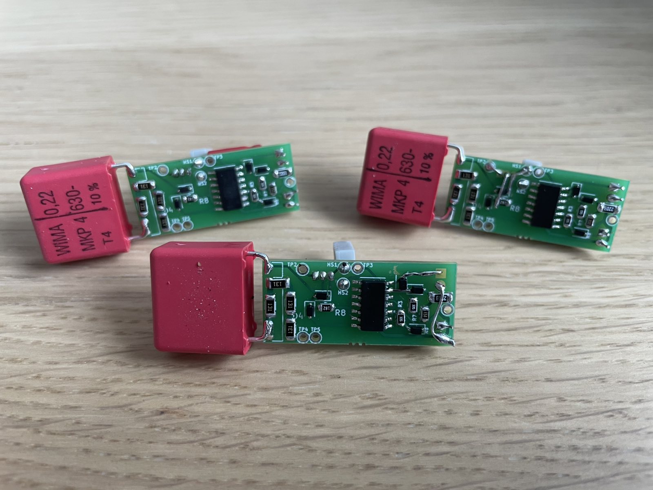
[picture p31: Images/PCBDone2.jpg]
PCBDone2


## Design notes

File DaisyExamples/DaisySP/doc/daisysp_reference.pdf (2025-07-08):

## DaisySP

Generated by Doxygen 1.9.1

i

1 Main Page | 1
2 Todo List | 3
3 Class Index | 5
4 File Index | 9
5 Class Documentation | 11

Generated by Doxygen

ii

iii

iv

v

vi

vii

viii

ix

x

xi

xii

xiii

xiv

xv

xvi

5.72.2.2 Process() | 158
5.72.2.3 SetAmp() | 158
5.73 daisysp::ZOscillator Class Reference | 159
5.73.1 Detailed Description | 159
5.73.2 Member Function Documentation | 159
5.73.2.1 Init() | 159
5.73.2.2 Process() | 160
5.73.2.3 SetFormantFreq() | 160
5.73.2.4 SetFreq() | 160
5.73.2.5 SetMode() | 160
5.73.2.6 SetShape() | 161
6 File Documentation | 163
6.1 Source/Drums/analogbassdrum.h File Reference | 163
6.2 Source/Drums/analogsnaredrum.h File Reference | 163
6.3 Source/Drums/hihat.h File Reference | 163
6.4 Source/Drums/synthbassdrum.h File Reference | 164
6.5 Source/Drums/synthsnaredrum.h File Reference | 164
6.6 Source/Effects/chorus.h File Reference | 164
6.7 Source/Effects/flanger.h File Reference | 165
6.8 Source/Effects/overdrive.h File Reference | 165
6.9 Source/Effects/sampleratereducer.h File Reference | 165
6.10 Source/Effects/tremolo.h File Reference | 165
6.11 Source/Filters/allpass.h File Reference | 166
6.12 Source/Noise/clockednoise.h File Reference | 166
6.13 Source/Noise/dust.h File Reference | 166
6.14 Source/Noise/fractal_noise.h File Reference | 166
6.15 Source/Noise/grainlet.h File Reference | 167
6.16 Source/Noise/particle.h File Reference | 167
6.17 Source/PhysicalModeling/drip.h File Reference | 167
6.18 Source/PhysicalModeling/KarplusString.h File Reference | 167
6.19 Source/PhysicalModeling/modalvoice.h File Reference | 168
6.20 Source/PhysicalModeling/resonator.h File Reference | 168
6.21 Source/PhysicalModeling/stringvoice.h File Reference | 168
6.22 Source/Synthesis/formantosc.h File Reference | 169
6.23 Source/Synthesis/harmonic_osc.h File Reference | 169
6.24 Source/Synthesis/oscillatorbank.h File Reference | 169
6.25 Source/Synthesis/variablesawosc.h File Reference | 169
6.26 Source/Synthesis/variableshapeosc.h File Reference | 170
6.27 Source/Synthesis/vosim.h File Reference | 170
6.28 Source/Synthesis/zoscillator.h File Reference | 170
6.29 Source/Utility/smooth_random.h File Reference | 170

xvii

Index | 171

# Chapter 1

# Main Page

## DaisySP A Powerful, Open Source DSP Library in C++

Applications • Features • Examples (https://github.com/electro-smith/DaisyExamples) • Getting Started • Community • Contributing
- License

### 1.0.1 Applications

- Embedded hardware using the Daisy Audio Platform (https://www.electro-smith.com/daisy)
- Audio plug-ins (VST, AU, JUCE) (https://github.com/electro-smith/Daisy-Juce-Example)
- Mobile apps (iOS, Android)
- VCV Rack (https://vcvrack.com/) modules

### 1.0.2 Features

- Synthesis Methods: (https://github.com/electro-smith/DaisySP/tree/master/Source/Synthesis) Subtractive, Physical Modeling, FM
- Filters: (https://github.com/electro-smith/DaisySP/tree/master/Source/Filters) Biquad, State-Variable, Modal, Comb
- Effects Processors: (https://github.com/electro-smith/DaisySP/tree/master/Source/Effects) Reverb, Delay, Decimate, Compressor
- Utilities: (https://github.com/electro-smith/DaisySP/tree/master/Source/Utility) Math Functions, Signal Conditioning, Aleatoric Generators

### 2 Main Page

### 1.0.3 Code Example

### 1.0.4 Getting Started

- Get the source: git clone https://github.com/electro-smith/DaisySP
- Navigate to the DaisySP repo: cd DaisySP
- Build the library: make
- Make some noise with the example programs! (https://github.com/electro-smith/DaisyExamples)

### 1.0.5 Community

Connect with other users and developers:

- Join the Daisy Forum (https://forum.electro-smith.com/)
- Chat on the Daisy Slack Workspace (https://join.slack.com/t/es-daisy/shared_invite/zt-f9cfm1g4-DgdCok1h1Rj4fpX90~IOww)

### 1.0.6 Contributing

Here are some ways that you can get involved:

- Proof read the documentation (https://electro-smith.github.io/DaisySP/index.html) and suggest improvements
- Test existing functionality and make issues (https://github.com/electro-smith/DaisySP/issues)
- Make new DSP modules. See issues labeled "feature"
- Port existing DSP modules from other open source projects (MIT). See issues labeled "port"
- Fix problems with existing modules. See issues labeled "bug" and/or "polish"

Before working on code, please check out our Contribution Guidelines (https://github.com/electro-smith/DaisyWiki/wiki/6.-Contribution-Guidelines) and Style Guide. (https://github.com/electro-smith/DaisySP/blob/master/doc/style_guide.pdf)

### 1.0.7 License

DaisySP uses the MIT license.

It can be used in both closed source and commercial projects, and does not provide a warranty of any kind.

For the full license, read the LICENSE (https://github.com/electro-smith/DaisySP/blob/master/LICENSE) file in the root directory.

# Chapter 2

# Todo List

Class daisysp::AdEnv
- Add Cycling
- Implement Curve (its only linear for now).
- Maybe make this an ADsr_ that has AD/AR/Asr_ modes.

Class daisysp::Compressor
Add soft/hard knee settings

Class daisysp::NlFilt
make this work on a single sample instead of just on blocks at a time.

Class daisysp::Phasor
Selecting which channels should be initialized/included in the sequence conversion.

Setup a similar start function for an external mux, but that seems outside the scope of this file.

Class daisysp::PitchShifter
- move hash_xs32 and myrand to dsp.h and give appropriate names

### 4 Todo List

# Chapter 3

# Class Index

## 3.1 Class List

Here are the classes, structs, unions and interfaces with brief descriptions:

daisysp::AdEnv | | 11
daisysp::Adsr | | 13
daisysp::Allpass | | 16
daisysp::AnalogBassDrum
808 bass drum model, revisited | | | 17
daisysp::AnalogSnareDrum
808 snare drum model, revisited | | 21
daisysp::ATone | | | 25
daisysp::Autowah | | 27
daisysp::Balance | | 29
daisysp::Biquad | | 30
daisysp::Bitcrush | | 33
daisysp::BlOsc | | | 34
daisysp::Chorus
Chorus Effect | 37
daisysp::ChorusEngine
Single Chorus engine. Used in Chorus | | 42
daisysp::ClockedNoise | | 44
daisysp::Comb | | | 46
daisysp::Compressor | | 47
daisysp::CrossFade | | 53
daisysp::DcBlock | | 55
daisysp::Decimator | | 56
daisysp::DelayLine< T, max_size > | | 58
daisysp::Drip | | | 59
daisysp::Dust
Dust Module | | | 61
daisysp::Flanger
Flanging Audio Effect | | 62
daisysp::Fm2 | | 64
daisysp::Fold | | 66
daisysp::FormantOscillator
Formant Oscillator Module | 67
daisysp::FractalRandomGenerator< T, order >
Fractal Noise, stacks octaves of a noise source | | | 69

### 6 Class Index

daisysp::GrainletOscillator
Granular Oscillator Module | 71
daisysp::HarmonicOscillator< num_harmonics >
Harmonic Oscillator Module based on Chebyshev polynomials | 73
daisysp::HiHat< MetallicNoiseSource, VCA, resonance >
808 HH, with a few extra parameters to push things to the CY territory | | 76
daisysp::Jitter | | 80
daisysp::Limiter | | 81
daisysp::Line | | 82
daisysp::LinearVCA
Linear type VCA | | | 84
daisysp::Maytrig | | 84
daisysp::Metro | | | 86
daisysp::ModalVoice
Simple modal synthesis voice with a mallet exciter: click -> LPF -> resonator | | 87
daisysp::Mode | | | 91
daisysp::MoogLadder | | 92
daisysp::NlFilt | | 94
daisysp::Oscillator | | | 96
daisysp::OscillatorBank
Oscillator Bank module | 99
daisysp::Overdrive
Distortion / Overdrive Module | 101
daisysp::Particle
Random impulse train processed by a resonant filter | 102
daisysp::Phasor | 106
daisysp::PitchShifter | 108
daisysp::Pluck | 109
daisysp::PolyPluck< num_voices > | 112
daisysp::Port | 113
daisysp::Resonator
Resonant Body Simulation | 115
daisysp::ResonatorSvf< batch_size >
SVF for use in the Resonator Class
118
daisysp::ReverbSc | 119
daisysp::ReverbScDl | 121
daisysp::RingModNoise
Ring mod style metallic noise generator | 123
daisysp::SampleHold | 123
daisysp::SampleRateReducer
Sample rate reducer | 124
daisysp::SmoothRandomGenerator
Smooth random generator for internal modulation.
126
daisysp::SquareNoise
808 style "metallic noise" with 6 square oscillators | 127
daisysp::String
Comb filter / KS string | 128
daisysp::StringVoice
Extended Karplus-Strong, with all the niceties from Rings | 130
daisysp::Svf | 134
daisysp::SwingVCA
Swing type VCA | 137
daisysp::SyntheticBassDrum
Naive bass drum model (modulated oscillator with FM + envelope) | 137
daisysp::SyntheticBassDrumAttackNoise
Attack Noise generator for SyntheticBassDrum | 142

3.1 Class List | 7

daisysp::SyntheticBassDrumClick
Click noise for SyntheticBassDrum | 143
daisysp::SyntheticSnareDrum
Naive snare drum model (two modulated oscillators + filtered noise) | 144
daisysp::Tone | 148
daisysp::Tremolo
Tremolo effect | 149
daisysp::VariableSawOscillator
Variable Saw Oscillator | 151
daisysp::VariableShapeOscillator
Variable Waveshape Oscillator | 153
daisysp::VosimOscillator
Vosim Oscillator Module
155
daisysp::WhiteNoise | 158
daisysp::ZOscillator
ZOscillator Module
159

### 8 Class Index

# Chapter 4

# File Index

## 4.1 File List

Here is a list of all documented files with brief descriptions:

Source/daisysp.h | | | ??
Source/Control/adenv.h | | | ??
Source/Control/adsr.h | | | ??
Source/Control/line.h | | ??
Source/Control/phasor.h | | ??
Source/Drums/analogbassdrum.h | | 163
Source/Drums/analogsnaredrum.h | 163
Source/Drums/hihat.h | 163
Source/Drums/synthbassdrum.h | 164
Source/Drums/synthsnaredrum.h | 164
Source/Dynamics/balance.h | | ??
Source/Dynamics/compressor.h | | ??
Source/Dynamics/crossfade.h | | ??
Source/Dynamics/limiter.h | | ??
Source/Effects/autowah.h | | ??
Source/Effects/bitcrush.h | | | ??
Source/Effects/chorus.h | | 164
Source/Effects/decimator.h | | | ??
Source/Effects/flanger.h | | 165
Source/Effects/fold.h | | ??
Source/Effects/overdrive.h | | 165
Source/Effects/pitchshifter.h | | ??
Source/Effects/reverbsc.h | | ??
Source/Effects/sampleratereducer.h | 165
Source/Effects/tremolo.h | 165
Source/Filters/allpass.h | 166
Source/Filters/atone.h | | ??
Source/Filters/biquad.h | | | ??
Source/Filters/comb.h | | ??
Source/Filters/mode.h | | ??
Source/Filters/moogladder.h | | ??
Source/Filters/nlfilt.h | | ??
Source/Filters/svf.h | | ??
Source/Filters/tone.h | | ??
Source/Noise/clockednoise.h | 166

### 10 File Index

Source/Noise/dust.h | 166
Source/Noise/fractal_noise.h | 166
Source/Noise/grainlet.h | 167
Source/Noise/particle.h | 167
Source/Noise/whitenoise.h | | | ??
Source/PhysicalModeling/drip.h | | 167
Source/PhysicalModeling/KarplusString.h | 167
Source/PhysicalModeling/modalvoice.h | | 168
Source/PhysicalModeling/pluck.h | | | ??
Source/PhysicalModeling/PolyPluck.h | | ??
Source/PhysicalModeling/resonator.h | | 168
Source/PhysicalModeling/stringvoice.h | 168
Source/Synthesis/blosc.h | | | ??
Source/Synthesis/fm2.h | | | ??
Source/Synthesis/formantosc.h | 169
Source/Synthesis/harmonic_osc.h | 169
Source/Synthesis/oscillator.h | ??
Source/Synthesis/oscillatorbank.h | 169
Source/Synthesis/variablesawosc.h | | 169
Source/Synthesis/variableshapeosc.h | | 170
Source/Synthesis/vosim.h | | 170
Source/Synthesis/zoscillator.h | | 170
Source/Utility/dcblock.h | | | ??
Source/Utility/delayline.h | | ??
Source/Utility/dsp.h | | ??
Source/Utility/jitter.h | | ??
Source/Utility/maytrig.h | | | ??
Source/Utility/metro.h | | | ??
Source/Utility/port.h | | | ??
Source/Utility/samplehold.h | | ??
Source/Utility/smooth_random.h | 170

# Chapter 5

# Class Documentation

## 5.1 daisysp::AdEnv Class Reference

#include <adenv.h>

Public Member Functions

- void Init (float sample_rate)
- float Process ()
- void Trigger ()
- void SetTime (uint8_t seg, float time)
- void SetCurve (float scalar)
- void SetMin (float min)
- void SetMax (float max)
- float GetValue () const
- uint8_t GetCurrentSegment ()
- bool IsRunning () const

### 5.1.1 Detailed Description

Trigger-able envelope with adjustable min/max, and independent per-segment time control.

Author

shensley

Todo • Add Cycling

- Implement Curve (its only linear for now).
- Maybe make this an ADsr_ that has AD/AR/Asr_ modes.

### 5.1.2 Member Function Documentation

### 12 Class Documentation

### 5.1.2.1 GetCurrentSegment()

uint8_t daisysp::AdEnv::GetCurrentSegment ( ) [inline]

Returns the segment of the envelope that the phase is currently located in.

### 5.1.2.2 GetValue()

float daisysp::AdEnv::GetValue ( ) const [inline]

Returns the current output value without processing the next sample

### 5.1.2.3 Init()

void AdEnv::Init (

float sample_rate )

Initializes the ad envelope.

Defaults:

- current segment = idle
- curve = linear
- phase = 0
- min = 0
- max = 1

Parameters

sample_rate sample rate of the audio engine being run

### 5.1.2.4 IsRunning()

bool daisysp::AdEnv::IsRunning ( ) const [inline]

Returns true if the envelope is currently in any stage apart from idle.

### 5.1.2.5 Process()

float AdEnv::Process ( )

Processes the current sample of the envelope. This should be called once per sample period.

Returns

the current envelope value.

5.2 daisysp::Adsr Class Reference | 13

### 5.1.2.6 SetCurve()

void daisysp::AdEnv::SetCurve (

float scalar ) [inline]

Sets the amount of curve applied. A positve value will create a log curve. Input range: -100 to 100. (or more)

### 5.1.2.7 SetMax()

void daisysp::AdEnv::SetMax (

float max ) [inline]

Sets the maximum value of the envelope output. Input range: -FLTmax_, to FLTmax_

### 5.1.2.8 SetMin()

void daisysp::AdEnv::SetMin (

float min ) [inline]

Sets the minimum value of the envelope output. Input range: -FLTmax_, to FLTmax_

### 5.1.2.9 SetTime()

void daisysp::AdEnv::SetTime (

uint8_t seg,

float time ) [inline]

Sets the length of time (in seconds) for a specific segment.

### 5.1.2.10 Trigger()

void daisysp::AdEnv::Trigger ( ) [inline]

Starts or retriggers the envelope.

The documentation for this class was generated from the following files:

- Source/Control/adenv.h
- Source/Control/adenv.cpp

## 5.2 daisysp::Adsr Class Reference

#include <adsr.h>

### 14 Class Documentation

Public Member Functions

- void Init (float sample_rate)
- float Process (bool gate)
- void SetTime (int seg, float time)
- void SetSustainLevel (float sus_level)
- uint8_t GetCurrentSegment ()
- bool IsRunning () const

### 5.2.1 Detailed Description

adsr envelope module

Original author(s) : Paul Batchelor

Ported from Soundpipe by Ben Sergentanis, May 2020

### 5.2.2 Member Function Documentation

### 5.2.2.1 GetCurrentSegment()

uint8_t daisysp::Adsr::GetCurrentSegment ( ) [inline]

get the current envelope segment

Returns

the segment of the envelope that the phase is currently located in.

### 5.2.2.2 Init()

void Adsr::Init (

float sample_rate )

Initializes the Adsr module.

Parameters

sample_rate - The sample rate of the audio engine being run.

5.2 daisysp::Adsr Class Reference | 15

### 5.2.2.3 IsRunning()

bool daisysp::Adsr::IsRunning ( ) const [inline]

Tells whether envelope is active

Returns

true if the envelope is currently in any stage apart from idle.

### 5.2.2.4 Process()

float Adsr::Process (

bool gate )

Processes one sample through the filter and returns one sample.

Parameters

gate - trigger the envelope, hold it to sustain

### 5.2.2.5 SetSustainLevel()

void daisysp::Adsr::SetSustainLevel (

float sus_level ) [inline]

Sustain level

Parameters

sus_level - sets sustain level

### 5.2.2.6 SetTime()

void daisysp::Adsr::SetTime (

int seg,

float time ) [inline]

Sets time Set time per segment in seconds

The documentation for this class was generated from the following files:

- Source/Control/adsr.h
- Source/Control/adsr.cpp

### 16 Class Documentation

## 5.3 daisysp::Allpass Class Reference

#include <allpass.h>

Public Member Functions

- void Init (float sample_rate, float ∗buff, size_t size)
- float Process (float in)
- void SetFreq (float looptime)
- void SetRevTime (float revtime)

### 5.3.1 Detailed Description

Allpass filter module
Passes all frequencies at their original levels, with a phase shift. Ported from soundpipe by Ben Sergentanis, May 2020

Author

Barry Vercoe, John ffitch

Date

1991

### 5.3.2 Member Function Documentation

### 5.3.2.1 Init()

void Allpass::Init (

float sample_rate,

float ∗ buff,

size_t size )

Initializes the allpass module.
\param sample_rate The sample rate of the audio engine being run.

Parameters

buff | Buffer for allpass to use.
size | Size of buff.

5.4 daisysp::AnalogBassDrum Class Reference | 17

### 5.3.2.2 Process()

float Allpass::Process (

float in )

Parameters

in Input sample.

Returns

Next floating point sample.

### 5.3.2.3 SetFreq()

void Allpass::SetFreq (

float looptime )

Sets the filter frequency (Implemented by delay time).

Parameters

looptime Filter looptime in seconds.

### 5.3.2.4 SetRevTime()

void daisysp::Allpass::SetRevTime (

float revtime ) [inline]

Parameters

revtime Reverb time in seconds.

The documentation for this class was generated from the following files:

- Source/Filters/allpass.h
- Source/Filters/allpass.cpp

## 5.4 daisysp::AnalogBassDrum Class Reference

808 bass drum model, revisited.

#include <analogbassdrum.h>

### 18 Class Documentation

Public Member Functions

- void Init (float sample_rate)
- float Process (bool trigger=false)
- void Trig ()
- void SetSustain (bool sustain)
- void SetAccent (float accent)
- void SetFreq (float f0)
- void SetTone (float tone)
- void SetDecay (float decay)
- void SetAttackFmAmount (float attack_fm_amount)
- void SetSelfFmAmount (float self_fm_amount)

### 5.4.1 Detailed Description

808 bass drum model, revisited.

Author

Ben Sergentanis

Date

Jan 2021 Ported from pichenettes/eurorack/plaits/dsp/drums/analog_bass_drum.h to an independent module.
Original code written by Emilie Gillet in 2016.

### 5.4.2 Member Function Documentation

### 5.4.2.1 Init()

void AnalogBassDrum::Init (

float sample_rate )

Initialize the module

Parameters

sample_rate Audio engine sample rate

### 5.4.2.2 Process()

float AnalogBassDrum::Process (

bool trigger = false )

5.4 daisysp::AnalogBassDrum Class Reference | 19

Get the next sample.

Parameters

trigger True strikes the drum. Defaults to false.

### 5.4.2.3 SetAccent()

void AnalogBassDrum::SetAccent (

float accent )

Set a small accent.

Parameters

accent Works 0-1

### 5.4.2.4 SetAttackFmAmount()

void AnalogBassDrum::SetAttackFmAmount (

float attack_fm_amount )

Set the amount of fm attack. Works together with self fm.

Parameters

attack_fm_amount Works best 0-1.

### 5.4.2.5 SetDecay()

void AnalogBassDrum::SetDecay (

float decay )

Set the decay length of the drum.

Parameters

decay Works best 0-1.

### 20 Class Documentation

### 5.4.2.6 SetFreq()

void AnalogBassDrum::SetFreq (

float f0 )

Set the drum's root frequency

Parameters

f0 Frequency in Hz

### 5.4.2.7 SetSelfFmAmount()

void AnalogBassDrum::SetSelfFmAmount (

float self_fm_amount )

Set the amount of self fm. Also affects fm attack, and volume decay.

Parameters

self_fm_amount Works best 0-1.

### 5.4.2.8 SetSustain()

void AnalogBassDrum::SetSustain (

bool sustain )

Set the bassdrum to play infinitely

Parameters

sustain True = infinite length

### 5.4.2.9 SetTone()

void AnalogBassDrum::SetTone (

float tone )

Set the amount of click.

5.5 daisysp::AnalogSnareDrum Class Reference | 21

Parameters

tone Works 0-1.

### 5.4.2.10 Trig()

void AnalogBassDrum::Trig ( )

Strikes the drum.

The documentation for this class was generated from the following files:

- Source/Drums/analogbassdrum.h
- Source/Drums/analogbassdrum.cpp

## 5.5 daisysp::AnalogSnareDrum Class Reference

808 snare drum model, revisited.

#include <analogsnaredrum.h>

Public Member Functions

- void Init (float sample_rate)
- float Process (bool trigger=false)
- void Trig ()
- void SetSustain (bool sustain)
- void SetAccent (float accent)
- void SetFreq (float f0)
- void SetTone (float tone)
- void SetDecay (float decay)
- void SetSnappy (float snappy)

Static Public Attributes

- static const int kNumModes = 5

### 5.5.1 Detailed Description

808 snare drum model, revisited.

Author

Ben Sergentanis

Date

Jan 2021 Ported from pichenettes/eurorack/plaits/dsp/drums/analog_snare_drum.h to an independent module.
Original code written by Emilie Gillet in 2016.

### 22 Class Documentation

### 5.5.2 Member Function Documentation

### 5.5.2.1 Init()

void AnalogSnareDrum::Init (

float sample_rate )

Init the module

Parameters

sample_rate Audio engine sample rate

### 5.5.2.2 Process()

float AnalogSnareDrum::Process (

bool trigger = false )

Get the next sample

Parameters

trigger Hit the drum with true. Defaults to false.

### 5.5.2.3 SetAccent()

void AnalogSnareDrum::SetAccent (

float accent )

Set how much accent to use

Parameters

accent Works 0-1.

### 5.5.2.4 SetDecay()

void AnalogSnareDrum::SetDecay (

float decay )

5.5 daisysp::AnalogSnareDrum Class Reference | 23

Set the length of the drum decay

### 24 Class Documentation

Parameters

decay Works with positive numbers

### 5.5.2.5 SetFreq()

void AnalogSnareDrum::SetFreq (

float f0 )

Set the drum's root frequency

Parameters

f0 Freq in Hz

### 5.5.2.6 SetSnappy()

void AnalogSnareDrum::SetSnappy (

float snappy )

Sets the mix between snare and drum.

Parameters

snappy 1 = just snare. 0 = just drum.

### 5.5.2.7 SetSustain()

void AnalogSnareDrum::SetSustain (

bool sustain )

Init the module

Parameters

sample_rate Audio engine sample rate

5.6 daisysp::ATone Class Reference | 25

### 5.5.2.8 SetTone()

void AnalogSnareDrum::SetTone (

float tone )

Set the brightness of the drum tone.

Parameters

tone Works 0-1. 1 = bright, 0 = dark.

### 5.5.2.9 Trig()

void AnalogSnareDrum::Trig ( )

Trigger the drum

The documentation for this class was generated from the following files:

- Source/Drums/analogsnaredrum.h
- Source/Drums/analogsnaredrum.cpp

## 5.6 daisysp::ATone Class Reference

#include <atone.h>

Public Member Functions

- void Init (float sample_rate)
- float Process (float &in)
- void SetFreq (float &freq)
- float GetFreq ()

### 5.6.1 Detailed Description

A first-order recursive high-pass filter with variable frequency response. Original Author(s): Barry Vercoe, John FFitch, Gabriel Maldonado

Year: 1991

Original Location: Csound – OOps/ugens5.c

Ported from soundpipe by Ben Sergentanis, May 2020

### 26 Class Documentation

### 5.6.2 Member Function Documentation

### 5.6.2.1 GetFreq()

float daisysp::ATone::GetFreq ( ) [inline]

get current frequency

Returns

the current value for the cutoff frequency or half-way point of the filter.

### 5.6.2.2 Init()

void ATone::Init (

float sample_rate )

Initializes the ATone module.

Parameters

sample_rate - The sample rate of the audio engine being run.

### 5.6.2.3 Process()

float ATone::Process (

float & in )

Processes one sample through the filter and returns one sample.

Parameters

in - input signal

### 5.6.2.4 SetFreq()

void daisysp::ATone::SetFreq (

float & freq ) [inline]

Sets the cutoff frequency or half-way point of the filter.

5.7 daisysp::Autowah Class Reference | 27

Parameters

freq - frequency value in Hz. Range: Any positive value.

The documentation for this class was generated from the following files:

- Source/Filters/atone.h
- Source/Filters/atone.cpp

## 5.7 daisysp::Autowah Class Reference

#include <autowah.h>

Public Member Functions

- void Init (float sample_rate)
- float Process (float in)
- void SetWah (float wah)
- void SetDryWet (float drywet)
- void SetLevel (float level)

### 5.7.1 Detailed Description

Autowah module

Original author(s) :

Ported from soundpipe by Ben Sergentanis, May 2020

### 5.7.2 Member Function Documentation

### 5.7.2.1 Init()

void Autowah::Init (

float sample_rate )

Initializes the Autowah module.

Parameters

sample_rate - The sample rate of the audio engine being run.

### 28 Class Documentation

### 5.7.2.2 Process()

float Autowah::Process (

float in )

Initializes the Autowah module.

Parameters

in - input signal to be wah'd

### 5.7.2.3 SetDryWet()

void daisysp::Autowah::SetDryWet (

float drywet ) [inline]

sets mix amount

Parameters

drywet : set effect dry/wet

### 5.7.2.4 SetLevel()

void daisysp::Autowah::SetLevel (

float level ) [inline]

sets wah level

Parameters

level : set wah level

### 5.7.2.5 SetWah()

void daisysp::Autowah::SetWah (

float wah ) [inline]

sets wah

5.8 daisysp::Balance Class Reference | 29

Parameters

wah : set wah amount

The documentation for this class was generated from the following files:

- Source/Effects/autowah.h
- Source/Effects/autowah.cpp

## 5.8 daisysp::Balance Class Reference

#include <balance.h>

Public Member Functions

- void Init (float sample_rate)
- float Process (float sig, float comp)
- void SetCutoff (float cutoff)

### 5.8.1 Detailed Description

Balances two sound sources. Sig is boosted to the level of comp.

Original author(s) : Barry Vercoe, john ffitch, Gabriel Maldonado

Year: 1991

Ported from soundpipe by Ben Sergentanis, May 2020

### 5.8.2 Member Function Documentation

### 5.8.2.1 Init()

void Balance::Init (

float sample_rate )

Initializes the balance module.

Parameters

sample_rate - The sample rate of the audio engine being run.

### 30 Class Documentation

### 5.8.2.2 Process()

float Balance::Process (

float sig,

float comp )

adjust sig level to level of comp

### 5.8.2.3 SetCutoff()

void daisysp::Balance::SetCutoff (

float cutoff ) [inline]

adjusts the rate at which level compensation happens

Parameters

cutoff : Sets half power point of special internal cutoff filter.

defaults to 10

The documentation for this class was generated from the following files:

- Source/Dynamics/balance.h
- Source/Dynamics/balance.cpp

## 5.9 daisysp::Biquad Class Reference

#include <biquad.h>

Public Member Functions

- void Init (float sample_rate)
- float Process (float in)
- void SetRes (float res)
- void SetCutoff (float cutoff)

### 5.9.1 Detailed Description

Two pole recursive filter

Original author(s) : Hans Mikelson

Year: 1998

Ported from soundpipe by Ben Sergentanis, May 2020

5.9 daisysp::Biquad Class Reference | 31

### 5.9.2 Member Function Documentation

### 5.9.2.1 Init()

void Biquad::Init (

float sample_rate )

Initializes the biquad module.

Parameters

sample_rate - The sample rate of the audio engine being run.

### 5.9.2.2 Process()

float Biquad::Process (

float in )

Filters the input signal

Returns

filtered output

### 5.9.2.3 SetCutoff()

void daisysp::Biquad::SetCutoff (

float cutoff ) [inline]

Sets filter cutoff in Hz

Parameters

cutoff : Set filter cutoff.

### 5.9.2.4 SetRes()

void daisysp::Biquad::SetRes (

float res ) [inline]

### 32 Class Documentation

Sets resonance amount

5.10 daisysp::Bitcrush Class Reference | 33

Parameters

res : Set filter resonance.

The documentation for this class was generated from the following files:

- Source/Filters/biquad.h
- Source/Filters/biquad.cpp

## 5.10 daisysp::Bitcrush Class Reference

#include <bitcrush.h>

Public Member Functions

- void Init (float sample_rate)
- float Process (float in)
- void SetBitDepth (int bitdepth)
- void SetCrushRate (float crushrate)

### 5.10.1 Detailed Description

bitcrush module

Original author(s) : Paul Batchelor,

Ported from soundpipe by Ben Sergentanis, May 2020

### 5.10.2 Member Function Documentation

### 5.10.2.1 Init()

void Bitcrush::Init (

float sample_rate )

Initializes the bitcrush module.

Parameters

sample_rate - The sample rate of the audio engine being run.

### 34 Class Documentation

### 5.10.2.2 Process()

float Bitcrush::Process (

float in )

bit crushes and downsamples the input

### 5.10.2.3 SetBitDepth()

void daisysp::Bitcrush::SetBitDepth (

int bitdepth ) [inline]

adjusts bitdepth

Parameters

bitdepth : Sets bit depth.

### 5.10.2.4 SetCrushRate()

void daisysp::Bitcrush::SetCrushRate (

float crushrate ) [inline]

adjusts the downsampling frequency

Parameters

crushrate : Sets rate to downsample to.

The documentation for this class was generated from the following files:

- Source/Effects/bitcrush.h
- Source/Effects/bitcrush.cpp

## 5.11 daisysp::BlOsc Class Reference

#include <blosc.h>

Public Types

- enum Waveforms { WAVE_TRIANGLE , WAVE_SAW , WAVE_SQUARE , WAVE_OFF }

5.11 daisysp::BlOsc Class Reference | 35

Public Member Functions

- void Init (float sample_rate)
- float Process ()
- void SetFreq (float freq)
- void SetAmp (float amp)
- void SetPw (float pw)
- void SetWaveform (uint8_t waveform)
- void Reset ()

### 5.11.1 Detailed Description

Band Limited Oscillator

Based on bltriangle, blsaw, blsquare from soundpipe

Original Author(s): Paul Batchelor, saw2 Faust by Julius Smith

Ported by Ben Sergentanis, May 2020

### 5.11.2 Member Enumeration Documentation

### 5.11.2.1 Waveforms

enum daisysp::BlOsc::Waveforms

Bl Waveforms

### 5.11.3 Member Function Documentation

### 5.11.3.1 Init()

void BlOsc::Init (

float sample_rate )

-Initialize oscillator. -Defaults to: 440Hz, .5 amplitude, .5 pw, Triangle.

### 5.11.3.2 Process()

float BlOsc::Process ( )

- Get next floating point oscillator sample.

### 36 Class Documentation

### 5.11.3.3 Reset()

void BlOsc::Reset ( )

- reset the phase of the oscillator.

### 5.11.3.4 SetAmp()

void daisysp::BlOsc::SetAmp (

float amp ) [inline]

- Float amp: Set oscillator amplitude, 0 to 1.

### 5.11.3.5 SetFreq()

void daisysp::BlOsc::SetFreq (

float freq ) [inline]

- Float freq: Set oscillator frequency in Hz.

### 5.11.3.6 SetPw()

void daisysp::BlOsc::SetPw (

float pw ) [inline]

- Float pw: Set square osc pulsewidth, 0 to 1. (no thru 0 at the moment)

### 5.11.3.7 SetWaveform()

void daisysp::BlOsc::SetWaveform (

uint8_t waveform ) [inline]

- uint8_t waveform: select between waveforms from enum above.
- i.e. SetWaveform(BL_WAVEFORM_SAW); to set waveform to saw

The documentation for this class was generated from the following files:

- Source/Synthesis/blosc.h
- Source/Synthesis/blosc.cpp

5.12 daisysp::Chorus Class Reference | 37

## 5.12 daisysp::Chorus Class Reference

Chorus Effect.

#include <chorus.h>

Public Member Functions

- void Init (float sample_rate)
- float Process (float in)
- float GetLeft ()
- float GetRight ()
- void SetPan (float panl, float panr)
- void SetPan (float pan)
- void SetLfoDepth (float depthl, float depthr)
- void SetLfoDepth (float depth)
- void SetLfoFreq (float freql, float freqr)
- void SetLfoFreq (float freq)
- void SetDelay (float delayl, float delayr)
- void SetDelay (float delay)
- void SetDelayMs (float msl, float msr)
- void SetDelayMs (float ms)
- void SetFeedback (float feedbackl, float feedbackr)
- void SetFeedback (float feedback)

### 5.12.1 Detailed Description

Chorus Effect.

Author

Ben Sergentanis

Date

Jan 2021 Based on https://www.izotope.com/en/learn/understanding-chorus-flangers-and-phasers-in-audio-production.←-html (https://www.izotope.com/en/learn/understanding-chorus-flangers-and-phasers-in-audio-production.html)
and | https://www.researchgate.net/publication/236629475_Implementing_←-
Professional_Audio_Effects_with_DSPs (https://www.researchgate.net/publication/236629475_Implementing_Professional_Audio_Effects_with_DSPs)

### 5.12.2 Member Function Documentation

### 5.12.2.1 GetLeft()

float Chorus::GetLeft ( )

Get the left channel's last sample

### 38 Class Documentation

### 5.12.2.2 GetRight()

float Chorus::GetRight ( )

Get the right channel's last sample

### 5.12.2.3 Init()

void Chorus::Init (

float sample_rate )

Initialize the module

Parameters

sample_rate Audio engine sample rate

### 5.12.2.4 Process()

float Chorus::Process (

float in )

Get the net floating point sample. Defaults to left channel.

Parameters

in Sample to process

### 5.12.2.5 SetDelay() [1/2]

void Chorus::SetDelay (

float delay )

Set both channel delay amounts.

Parameters

delay Both channel delay amount. Works 0-1.

### 5.12.2.6 SetDelay() [2/2]

void Chorus::SetDelay (

5.12 daisysp::Chorus Class Reference | 39

float delayl,

float delayr )

Set both channel delay amounts individually.

Parameters

delayl | Left channel delay amount. Works 0-1.
delayr | Right channel delay amount.

### 5.12.2.7 SetDelayMs() [1/2]

void Chorus::SetDelayMs (

float ms )

Set both channel delay in ms.

Parameters

ms Both channel delay amounts in ms.

### 5.12.2.8 SetDelayMs() [2/2]

void Chorus::SetDelayMs (

float msl,

float msr )

Set both channel delay individually.

Parameters

msl | Left channel delay in ms.
msr | Right channel delay in ms.

### 5.12.2.9 SetFeedback() [1/2]

void Chorus::SetFeedback (

float feedback )

Set both channels feedback.

### 40 Class Documentation

Parameters

feedback Both channel feedback. Works 0-1.

### 5.12.2.10 SetFeedback() [2/2]

void Chorus::SetFeedback (

float feedbackl,

float feedbackr )

Set both channels feedback individually.

Parameters

feedbackl | Left channel feedback. Works 0-1.
feedbackr | Right channel feedback.

### 5.12.2.11 SetLfoDepth() [1/2]

void Chorus::SetLfoDepth (

float depth )

Set both lfo depths.

Parameters

depth Both channels lfo depth. Works 0-1.

### 5.12.2.12 SetLfoDepth() [2/2]

void Chorus::SetLfoDepth (

float depthl,

float depthr )

Set both lfo depths individually.

Parameters

depthl | Left channel lfo depth. Works 0-1.
depthr | Right channel lfo depth.

5.12 daisysp::Chorus Class Reference | 41

### 5.12.2.13 SetLfoFreq() [1/2]

void Chorus::SetLfoFreq (

float freq )

Set both lfo frequencies.

Parameters

depth Both channel lfo freqs in Hz.

### 5.12.2.14 SetLfoFreq() [2/2]

void Chorus::SetLfoFreq (

float freql,

float freqr )

Set both lfo frequencies individually.

Parameters

depthl | Left channel lfo freq in Hz.
depthr | Right channel lfo freq in Hz.

### 5.12.2.15 SetPan() [1/2]

void Chorus::SetPan (

float pan )

Pan both channels.

Parameters

pan Where to pan both channels to. 0 is left, 1 is right.

### 5.12.2.16 SetPan() [2/2]

void Chorus::SetPan (

float panl,

float panr )

### 42 Class Documentation

Pan both channels individually.

Parameters

panl | Pan the left channel. 0 is left, 1 is right.
panr | Pan the right channel.

The documentation for this class was generated from the following files:

- Source/Effects/chorus.h
- Source/Effects/chorus.cpp

## 5.13 daisysp::ChorusEngine Class Reference

Single Chorus engine. Used in Chorus.

#include <chorus.h>

Public Member Functions

- void Init (float sample_rate)
- float Process (float in)
- void SetLfoDepth (float depth)
- void SetLfoFreq (float freq)
- void SetDelay (float delay)
- void SetDelayMs (float ms)
- void SetFeedback (float feedback)

### 5.13.1 Detailed Description

Single Chorus engine. Used in Chorus.

Author

Ben Sergentanis

### 5.13.2 Member Function Documentation

### 5.13.2.1 Init()

void ChorusEngine::Init (

float sample_rate )

Initialize the module

5.13 daisysp::ChorusEngine Class Reference | 43

Parameters

sample_rate Audio engine sample rate.

### 5.13.2.2 Process()

float ChorusEngine::Process (

float in )

Get the next sample

Parameters

in Sample to process

### 5.13.2.3 SetDelay()

void ChorusEngine::SetDelay (

float delay )

Set the internal delay rate.

Parameters

delay Tuned for 0-1. Maps to .1 to 50 ms.

### 5.13.2.4 SetDelayMs()

void ChorusEngine::SetDelayMs (

float ms )

Set the delay time in ms.

Parameters

ms Delay time in ms.

### 44 Class Documentation

### 5.13.2.5 SetFeedback()

void ChorusEngine::SetFeedback (

float feedback )

Set the feedback amount.

Parameters

feedback Amount from 0-1.

### 5.13.2.6 SetLfoDepth()

void ChorusEngine::SetLfoDepth (

float depth )

How much to modulate the delay by.

Parameters

depth Works 0-1.

### 5.13.2.7 SetLfoFreq()

void ChorusEngine::SetLfoFreq (

float freq )

Set lfo frequency.

Parameters

freq Frequency in Hz

The documentation for this class was generated from the following files:

- Source/Effects/chorus.h
- Source/Effects/chorus.cpp

## 5.14 daisysp::ClockedNoise Class Reference

#include <clockednoise.h>

5.14 daisysp::ClockedNoise Class Reference | 45

Public Member Functions

- void Init (float sample_rate)
- float Process ()
- void SetFreq (float freq)
- void Sync ()

### 5.14.1 Detailed Description

@brief Clocked Noise Module

Author

Ported by Ben Sergentanis

Date

Jan 2021 Noise processed by a sample and hold running at a target frequency.

Ported from pichenettes/eurorack/plaits/dsp/noise/clocked_noise.h
to an independent module.
Original code written by Emilie Gillet in 2016.

### 5.14.2 Member Function Documentation

### 5.14.2.1 Init()

void ClockedNoise::Init (

float sample_rate )

Initialize module

Parameters

sample_rate Audio engine sample rate

### 5.14.2.2 Process()

float ClockedNoise::Process ( )

Get the next floating point sample

### 46 Class Documentation

### 5.14.2.3 SetFreq()

void ClockedNoise::SetFreq (

float freq )

Set the frequency at which the next sample is generated.

Parameters

freq Frequency in Hz

### 5.14.2.4 Sync()

void ClockedNoise::Sync ( )

Calling this forces another random float to be generated

The documentation for this class was generated from the following files:

- Source/Noise/clockednoise.h
- Source/Noise/clockednoise.cpp

## 5.15 daisysp::Comb Class Reference

#include <comb.h>

Public Member Functions

- void Init (float sample_rate, float ∗buff, size_t size)
- float Process (float in)
- void SetPeriod (float looptime)
- void SetFreq (float freq)
- void SetRevTime (float revtime)

### 5.15.1 Detailed Description

Comb filter module

Original author(s) :

Ported from soundpipe by Ben Sergentanis, May 2020

### 5.15.2 Member Function Documentation

### 5.15.2.1 Init()

void Comb::Init (

float sample_rate,

float ∗ buff,

size_t size )

Initializes the Comb module.

5.16 daisysp::Compressor Class Reference | 47

Parameters

sample_rate | - The sample rate of the audio engine being run.
buff | - input buffer, kept in either main() or global space
size | - size of buff

### 5.15.2.2 Process()

float Comb::Process (

float in )

processes the comb filter

### 5.15.2.3 SetFreq()

void daisysp::Comb::SetFreq (

float freq ) [inline]

Sets the frequency of the comb filter in Hz

### 5.15.2.4 SetPeriod()

void Comb::SetPeriod (

float looptime )

Sets the period of the comb filter in seconds

### 5.15.2.5 SetRevTime()

void daisysp::Comb::SetRevTime (

float revtime ) [inline]

Sets the decay time of the comb filter

The documentation for this class was generated from the following files:

- Source/Filters/comb.h
- Source/Filters/comb.cpp

## 5.16 daisysp::Compressor Class Reference

#include <compressor.h>

### 48 Class Documentation

Public Member Functions

- void Init (float sample_rate)
- float Process (float in)
- float Process (float in, float key)
- float Apply (float in)
- void ProcessBlock (float ∗in, float ∗out, size_t size)
- void ProcessBlock (float ∗in, float ∗out, float ∗key, size_t size)
- void ProcessBlock (float ∗∗in, float ∗∗out, float ∗key, size_t channels, size_t size)
- float GetRatio ()
- void SetRatio (float ratio)
- float GetThreshold ()
- void SetThreshold (float threshold)
- float GetAttack ()
- void SetAttack (float attack)
- float GetRelease ()
- void SetRelease (float release)
- float GetMakeup ()
- void SetMakeup (float gain)
- void AutoMakeup (bool enable)
- float GetGain ()

### 5.16.1 Detailed Description

dynamics compressor

influenced by compressor in soundpipe (from faust).

Modifications made to do:

- Less calculations during each process loop (coefficients recalculated on parameter change).
- C++-ified
- added sidechain support
- pulled gain apart for monitoring and multichannel support
- improved readability
- improved makeup-gain calculations
- changing controls now costs a lot less
- a lot less expensive

by: shensley, improved upon by AvAars

Todo Add soft/hard knee settings

### 5.16.2 Member Function Documentation

### 5.16.2.1 Apply()

float daisysp::Compressor::Apply (

float in ) [inline]

Apply compression to the audio signal, based on the previously calculated gain

5.16 daisysp::Compressor Class Reference | 49

Parameters

in audio input signal

### 5.16.2.2 AutoMakeup()

void daisysp::Compressor::AutoMakeup (

bool enable ) [inline]

Enables or disables the automatic makeup gain. Disabling sets the makeup gain to 0.0

Parameters

enable true to enable, false to disable

### 5.16.2.3 GetAttack()

float daisysp::Compressor::GetAttack ( ) [inline]

Gets the envelope time for onset of compression

### 5.16.2.4 GetGain()

float daisysp::Compressor::GetGain ( ) [inline]

Gets the gain reduction in dB

### 5.16.2.5 GetMakeup()

float daisysp::Compressor::GetMakeup ( ) [inline]

Gets the additional gain to make up for the compression

### 5.16.2.6 GetRatio()

float daisysp::Compressor::GetRatio ( ) [inline]

Gets the amount of gain reduction

### 50 Class Documentation

### 5.16.2.7 GetRelease()

float daisysp::Compressor::GetRelease ( ) [inline]

Gets the envelope time for release of compression

### 5.16.2.8 GetThreshold()

float daisysp::Compressor::GetThreshold ( ) [inline]

Gets the threshold in dB

### 5.16.2.9 Init()

void Compressor::Init (

float sample_rate )

Initializes compressor

Parameters

sample_rate rate at which samples will be produced by the audio engine.

### 5.16.2.10 Process() [1/2]

float Compressor::Process (

float in )

Compress the audio input signal, saves the calculated gain

Parameters

in audio input signal

### 5.16.2.11 Process() [2/2]

float daisysp::Compressor::Process (

float in,

float key ) [inline]

Compresses the audio input signal, keyed by a secondary input.

5.16 daisysp::Compressor Class Reference | 51

Parameters

in | audio input signal (to be compressed)
key | audio input that will be used to side-chain the compressor

### 5.16.2.12 ProcessBlock() [1/3]

void Compressor::ProcessBlock (

float ∗∗ in,

float ∗∗ out,

float ∗ key,

size_t channels,

size_t size )

Compresses a block of multiple channels of audio, keyed by a secondary input

Parameters

in | audio input signals (to be compressed)
out | audio output signals
key | audio input that will be used to side-chain the compressor
channels | the number of audio channels
size | the size of the block

### 5.16.2.13 ProcessBlock() [2/3]

void Compressor::ProcessBlock (

float ∗ in,

float ∗ out,

float ∗ key,

size_t size )

Compresses a block of audio, keyed by a secondary input

Parameters

in | audio input signal (to be compressed)
out | audio output signal
key | audio input that will be used to side-chain the compressor
size | the size of the block

### 52 Class Documentation

### 5.16.2.14 ProcessBlock() [3/3]

void daisysp::Compressor::ProcessBlock (

float ∗ in,

float ∗ out,

size_t size ) [inline]

Compresses a block of audio

Parameters

in | audio input signal
out | audio output signal
size | the size of the block

### 5.16.2.15 SetAttack()

void daisysp::Compressor::SetAttack (

float attack ) [inline]

Sets the envelope time for onset of compression for signals above the threshold.

Parameters

attack Expects 0.001 -> 10

### 5.16.2.16 SetMakeup()

void daisysp::Compressor::SetMakeup (

float gain ) [inline]

Manually sets the additional gain to make up for the compression

Parameters

gain Expects 0.0 -> 80

### 5.16.2.17 SetRatio()

void daisysp::Compressor::SetRatio (

float ratio ) [inline]

Sets the amount of gain reduction applied to compressed signals

5.17 daisysp::CrossFade Class Reference | 53

Parameters

ratio Expects 1.0 -> 40. (untested with values < 1.0)

### 5.16.2.18 SetRelease()

void daisysp::Compressor::SetRelease (

float release ) [inline]

Sets the envelope time for release of compression as input signal falls below threshold.

Parameters

release Expects 0.001 -> 10

### 5.16.2.19 SetThreshold()

void daisysp::Compressor::SetThreshold (

float threshold ) [inline]

Sets the threshold in dB at which compression will be applied

Parameters

threshold Expects 0.0 -> -80.

The documentation for this class was generated from the following files:

- Source/Dynamics/compressor.h
- Source/Dynamics/compressor.cpp

## 5.17 daisysp::CrossFade Class Reference

#include <crossfade.h>

Public Member Functions

- void Init (int curve)
- void Init ()
- float Process (float &in1, float &in2)
- void SetPos (float pos)
- void SetCurve (uint8_t curve)
- float GetPos (float pos)
- uint8_t GetCurve (uint8_t curve)

### 54 Class Documentation

### 5.17.1 Detailed Description

Performs a CrossFade between two signals

Original author: Paul Batchelor

Ported from Soundpipe by Andrew Ikenberry

added curve option for constant power, etc.

### 5.17.2 Member Function Documentation

### 5.17.2.1 GetCurve()

uint8_t daisysp::CrossFade::GetCurve (

uint8_t curve ) [inline]

Returns current curve

### 5.17.2.2 GetPos()

float daisysp::CrossFade::GetPos (

float pos ) [inline]

Returns current position

### 5.17.2.3 Init() [1/2]

void daisysp::CrossFade::Init ( ) [inline]

Initialize with default linear curve

### 5.17.2.4 Init() [2/2]

void daisysp::CrossFade::Init (

int curve ) [inline]

Initializes CrossFade module Defaults

- current position = .5
- curve = linear

5.18 daisysp::DcBlock Class Reference | 55

### 5.17.2.5 Process()

float CrossFade::Process (

float & in1,

float & in2 )

processes CrossFade and returns single sample

### 5.17.2.6 SetCurve()

void daisysp::CrossFade::SetCurve (

uint8_t curve ) [inline]

Sets current curve applied to CrossFade Expected input: See Curve Options

### 5.17.2.7 SetPos()

void daisysp::CrossFade::SetPos (

float pos ) [inline]

Sets position of CrossFade between two input signals Input range: 0 to 1

The documentation for this class was generated from the following files:

- Source/Dynamics/crossfade.h
- Source/Dynamics/crossfade.cpp

## 5.18 daisysp::DcBlock Class Reference

#include <dcblock.h>

Public Member Functions

- void Init (float sample_rate)
- float Process (float in)

### 5.18.1 Detailed Description

Removes DC component of a signal

### 5.18.2 Member Function Documentation

### 56 Class Documentation

### 5.18.2.1 Init()

void DcBlock::Init (

float sample_rate )

Initializes DcBlock module

### 5.18.2.2 Process()

float DcBlock::Process (

float in )

performs DcBlock Process

The documentation for this class was generated from the following files:

- Source/Utility/dcblock.h
- Source/Utility/dcblock.cpp

## 5.19 daisysp::Decimator Class Reference

#include <decimator.h>

Public Member Functions

- void Init ()
- float Process (float input)
- void SetDownsampleFactor (float downsample_factor)
- void SetBitcrushFactor (float bitcrush_factor)
- void SetBitsToCrush (const uint8_t &bits)
- float GetDownsampleFactor ()
- float GetBitcrushFactor ()

### 5.19.1 Detailed Description

Performs downsampling and bitcrush effects

### 5.19.2 Member Function Documentation

### 5.19.2.1 GetBitcrushFactor()

float daisysp::Decimator::GetBitcrushFactor ( ) [inline]

Returns current setting of bitcrush

5.19 daisysp::Decimator Class Reference | 57

### 5.19.2.2 GetDownsampleFactor()

float daisysp::Decimator::GetDownsampleFactor ( ) [inline]

Returns current setting of downsample

### 5.19.2.3 Init()

void Decimator::Init ( )

Initializes downsample module

### 5.19.2.4 Process()

float Decimator::Process (

float input )

Applies downsample and bitcrush effects to input signal.

Returns

one sample. This should be called once per sample period.

### 5.19.2.5 SetBitcrushFactor()

void daisysp::Decimator::SetBitcrushFactor (

float bitcrush_factor ) [inline]

Sets amount of bitcrushing Input range:

### 5.19.2.6 SetBitsToCrush()

void daisysp::Decimator::SetBitsToCrush (

const uint8_t & bits ) [inline]

Sets the exact number of bits to crush 0-16 bits

### 5.19.2.7 SetDownsampleFactor()

void daisysp::Decimator::SetDownsampleFactor (

float downsample_factor ) [inline]

Sets amount of downsample Input range:

The documentation for this class was generated from the following files:

- Source/Effects/decimator.h
- Source/Effects/decimator.cpp
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

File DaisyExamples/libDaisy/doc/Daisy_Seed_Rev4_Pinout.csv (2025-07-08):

 | SCH name | Pin name | ADC | Arduino D# | Arduino A# | I2C | UART | SPI
1 | USB_HS_ID | PB12 | x | D0 |  |  | UART5_RX | SPI2_NSS/I2S2_WS | TIM1_BKIN |  |  | DFSDM1_DATIN1 | USART3_CK | FDCAN2_RX | OTG_HS_ULPI_D5 | ETH_MII_TXD0/ETH_RMII_TXD0 | OTG_HS_ID | TIM1_BKIN_COMP12 |  | EVENTOUT
2 | SDMMC1_D3 | PC11 | x | D1 |  |  | USART3_RX/UART4_RX | SPI3_MISO/ I2S3_SDI | HRTIM_FLT2 | DFSDM1_DATIN5 |  |  |  | QUADSPI_BK2_NCS | SDMMC1_D3 | DCMI_D4 | EVENTOUT
3 | SDMMC1_D2 | PC10 | x | D2 |  |  | USART3_TX/UART4_TX | SPI3_SCK/I2S3_CK | HRTIM_EEV1 | DFSDM1_CKIN5 |  |  |  | QUADSPI_BK1_IO1 | SDMMC1_D2 | DCMI_D8 | LCD_R2 | EVENTOUT
4 | SDMMC1_D1 | PC9 | x | D3 |  | I2C3_SDA |  |  | MCO2 | TIM3_CH4 | TIM8_CH4 |  | I2S_CKIN | UART5_CTS | QUADSPI_BK1_IO0 | LCD_G3 | SWPMI_SUSPEND | SDMMC1_D1 | DCMI_D3 | LCD_B2 | EVENTOUT
5 | SDMMC1_D0 | PC8 | x | D4 |  |  |  |  | TRACED1 | HRTIM_CHB1 | TIM3_CH3 | TIM8_CH3 | USART6_CK | UART5_RTS/UART5_DE | FMC_NE2/FMC_NCE | SWPMI_RX | SDMMC1_D0 | DCMI_D2 | EVENTOUT
6 | SDMMC1_CMD | PD2 | x | D5 |  |  | UART5_RX |  | TRACED2 | TIM3_ETR |  | SDMMC1_CMD | DCMI_D11 | EVENTOUT
7 | SDMMC1_CK | PC12 | x | D6 |  |  | UART5_TX | SPI3_MOSI/I2S3_SDO | TRACED3 | HRTIM_EEV2 |  |  |  | SDMMC1_CK | DCMI_D9 | EVENTOUT
8 | SPI1_NSS | PG10 | x | D7 |  |  |  | SPI1_NSS/I2S1_WS | HRTIM_FLT5 |  | LCD_G3 |  | FMC_NE3 | DCMI_D2 | LCD_B2 | EVENTOUT
9 | SPI1_SCK | PG11 | x | D8 |  |  |  | SPI1_SCK/I2S1_CK | LPTIM1_IN2 | HRTIM_EEV4 |  | SPDIFRX1_IN1 | SDMMC2_D2 | ETH_MII_TX_EN/ETH_RMII_TX_ EN | DCMI_D3 | LCD_B3 | EVENTOUT
10 | SPI1_MISO | PB4 | x | D9 |  |  | UART7_TX | SPI1_MISO/I2S1_SDI/SPI3_MISO/I2S3_SDI/SPI2_NSS/I2S2_WS/SPI6_MISO | NJTRST | TIM16_BKIN | TIM3_CH1 | HRTIM_EEV6 |  |  |  |  | SDMMC2_D3 |  | EVENTOUT
11 | SPI1_MOSI | PB5 | x | D10 |  |  | UART5_RX | SPI1_MOSI/I2S1_SDO/SPI3_MOSI/I2S3_SDO/SPI6_MOSI | TIM17_BKIN | TIM3_CH2 | HRTIM_EEV7 |  |  |  |  |  | FDCAN2_RX | OTG_HS_ULPI_D7 | ETH_PPS_OUT | FMC_SDCKE1 | DCMI_D10 |  | EVENTOUT
12 | I2C1_SCL | PB8 | x | D11 |  | I2C1_SCL/I2C4_SCL | UART4_RX |  | TIM16_CH1 | TIM4_CH3 | DFSDM1_CKIN7 |  |  | SDMMC1_CKIN |  | FDCAN1_RX | SDMMC2_D4 | ETH_MII_TXD3 | SDMMC1_D4 | DCMI_D6 | LCD_B6 | EVENTOUT
13 | I2C1_SDA | PB9 | x | D12 |  | I2C1_SDA/I2C4_SDA | UART4_TX | SPI2_NSS/I2S2_WS | TIM17_CH1 | TIM4_CH4 | DFSDM1_DATIN7 |  |  |  | SDMMC1_CDIR |  | FDCAN1_TX | SDMMC2_D5 |  | SDMMC1_D5 | DCMI_D7 | LCD_B7 | EVENTOUT
14 | USART1_TX | PB6 | x | D13 |  | I2C1_SCL/I2C4_SCL | USART1_TX/LPUART1_TX/UART5_TX |  | TIM16_CH1N | TIM4_CH1 | HRTIM_EEV8 |  | CEC |  |  |  | FDCAN2_TX | QUADSPI_BK1_NCS | DFSDM1_DATIN5 | FMC_SDNE1 | DCMI_D5 |  | EVENTOUT
15 | USART1_RX | PB7 | x | D14 |  | I2C1_SDA/I2C4_SDA | USART1_RX/LPUART1_RX |  | TIM17_CH1N | TIM4_CH2 | HRTIM_EEV9 |  |  |  |  | FDCAN2_TXFD_MODE | DFSDM1_CKIN5 | FMC_NL | DCMI_VSYNC | EVENTOUT
16 | AUDIO IN L | x | x | NC |  |  |  |  | x
17 | AUDIO INR | x | x | NC |  |  |  |  | x
18 | AUDIO OUT L | x | x | NC |  |  |  |  | x
19 | AUDIO OUT R | x | x | NC |  |  |  |  | x
20 | AGND | x | x | NC
21 | 3v3A | x | x | NC |  |  |  |  | x
22 | ADC_INP10 | PC0 | ADC12_INP10 | D15 | A0 |  |  |  | DFSDM1_CKIN0 | DFSDM1_DATIN4 |  | OTG_HS_ULPI_STP | FMC_SDNWE | LCD_R5 | EVENTOUT
23 | ADC_INP15 | PA3 | ADC12_INP15 | D16 | A1 |  | USART2_RX |  | TIM2_CH4 | TIM5_CH4 | LPTIM5_OUT | TIM15_CH2 |  | LCD_B2 | OTG_HS_ULPI_D0 | ETH_MII_COL | LCD_B5 | EVENTOUT
24 | ADC_INP5 | PB1 | ADC12_INP5 | D17 | A2 |  |  |  | TIM1_CH3N | TIM3_CH4 | TIM8_CH3N | DFSDM1_DATIN1 | LCD_R6 | OTG_HS_ULPI_D2 | ETH_MII_RXD3 | LCD_G0 | EVENTOUT
25 | ADC_INP7 | PA7 | ADC12_INP7 | D18 | A3 |  |  | SPI1_MOSI/I2S1_SDO/SPI6_MOSI | TIM1_CH1N | TIM3_CH2 | TIM8_CH1N |  |  | TIM14_CH1 | ETH_MII_RX_DV/ETH_RMII_CRS _DV | FMC_SDNWE | EVENTOUT
26 | ADC_INP3 | PA6 | ADC12_INP3 | D19 | A4 |  |  | SPI1_MISO/I2S1_SDI/SPI6_MISO | TIM1_BKIN | TIM3_CH1 | TIM8_BKIN |  |  | TIM13_CH1 | TIM8_BKIN_COMP12 | MDIOS_MDC | TIM1_BKIN_COMP12 | DCMI_PIXCLK | LCD_G2 | EVENTOUT
27 | ADC_INP11 | PC1 | ADC123_INP11 | D20 | A5 |  |  | SPI2_MOSI/I2S2_SDO | TRACED0 | SAI1_D1 | DFSDM1_DATIN0 | DFSDM1_CKIN4 |  | SAI1_SD_A | SAI4_SD_A | SDMMC2_CK | SAI4_D1 | ETH_MDC | MDIOS_MDC | EVENTOUT
28 | ADC1_INP4 | PC4 | ADC12_INP4 | D21 | A6 |  |  |  | DFSDM1_CKIN2 | I2S1_MCK | SPDIFRX1_IN3 | ETH_MII_RXD0/ETH_RMII_RXD0 | FMC_SDNE0 | EVENTOUT
29 | DAC1_OUT2 | PA5 | ADC12_INP19 | D22 | A7 |  |  | SPI1_SCK/I2S1_CK/SPI6_SCK | D2PWREN | TIM2_CH1/TIM2_ETR | TIM8_CH1N |  |  | OTG_HS_ULPI_CK | LCD_R4 | EVENTOUT
30 | DAC1_OUT1 | PA4 | ADC12_INP18 | D23 | A8 |  |  | SPI1_NSS/I2S1_WS/SPI3_NSS/I2S3_WS/SPI6_NSS | D1PWREN | TIM5_ETR |  |  | USART2_CK |  | OTG_HS_SOF | DCMI_HSYNC | LCD_VSYNC | EVENTOUT
31 | SAI2_MCLK_B | PA1 | ADC1_INP17 | D24 | A9 |  | UART4_RX |  | TIM2_CH2 | TIM5_CH2 | LPTIM3_OUT | TIM15_CH1N | USART2_RTS/USART2_DE |  | QUADSPI_BK1_IO3 |  | ETH_MII_RX_CLK/ETH_RMII_RE F_CLK | LCD_R2 | EVENTOUT
32 | SAI2_SD_B | PA0 | ADC1_INP16 | D25 | A10 |  | UART4_TX |  | TIM2_CH1/TIM2_ETR | TIM5_CH1 | TIM8_ETR | TIM15_BKIN | USART2_CTS/USART2_NSS |  | SDMMC2_CMD |  | ETH_MII_CRS | EVENTOUT
33 | SAI2_SD_A | PD11 | x | D26 |  |  |  |  | LPTIM2_IN2 |  | USART3_CTS/USART3_NSS | QUADSPI_BK1_IO0 |  | FMC_A16 | EVENTOUT
34 | SAI2_FS_B | PG9 | x | D27 |  |  | USART6_RX | SPI1_MISO/I2S1_SDI |  |  | SPDIFRX1_IN4 | QUADSPI_BK2_IO2 |  | FMC_NE2/FMC_NCE | DCMI_VSYNC | EVENTOUT
35 | SAI2_SCK_B | PA2 | ADC12_INP14 | D28 | A11 |  | USART2_TX |  | TIM2_CH3 | TIM5_CH3 | LPTIM4_OUT | TIM15_CH1 |  |  | ETH_MDIO | MDIOS_MDIO | LCD_R1 | EVENTOUT
36 | USB_HS_D_- | PB14 | x | D29 |  |  | USART1_TX | SPI2_MISO/I2S2_SDI | TIM1_CH2N | TIM12_CH1 | TIM8_CH2N |  |  | DFSDM1_DATIN2 | USART3_RTS/USART3_DE | UART4_RTS/UART4_DE | SDMMC2_D0 | OTG_HS_DM | EVENTOUT
37 | USB_HS_D_+ | PB15 | x | D30 |  |  | USART1_RX | SPI2_MOSI/I2S2_SDO | RTC_REFIN | TIM1_CH3N | TIM12_CH2 | TIM8_CH3N |  |  | DFSDM1_CKIN2 | UART4_CTS | SDMMC2_D1 | OTG_HS_DP | EVENTOUT
38 | 3v3D | x | x |  |  |  |  |  | x
39 | VIN | x | x |  |  |  |  |  | x
40 | GND | x | x |  |  |  |  |  | x
INTERNAL
MEM1 | QSPI | QSPI FLASH 8MB
MEM2 | SDRAM | SDRAM 64MB
 | USB FS D+ | USB FS
 | USB FS D- | USB FS
 |  |  |  |  |  |  |  |  |  |  |  |  |  | LPUART1_TX
internal SAI | I2C2 |  |  |  |  |  |  |  |  |  |  |  |  | LPUART1_RX
 | SAI1_MCLK_A | PE2 |  |  |  |  |  |  |  |  |  |  |  | UART4_RX
 | SAI1_SD_B | PE3 |  |  |  |  |  |  |  |  |  |  |  | UART4_TX
 | SAI1_FS_A | PE4 |  |  |  |  |  |  |  |  |  |  |  | UART5_RX
 | SAI1_SCK_A | PE5 |  |  |  |  |  |  |  |  |  |  |  | UART5_TX
 | SAI1_SD_A | PE6 |  |  |  |  |  |  |  |  |  |  |  | UART7_RX
 |  |  |  |  |  |  |  |  |  |  |  |  |  | UART7_TX
 |  |  |  |  |  |  |  |  |  |  |  |  |  | USART1_RX
On Board User LED | PC7 |  |  | D31 |  |  |  |  |  |  |  |  |  | USART1_TX
On Board Test Point | PG14 |  |  |  |  |  |  |  |  |  |  |  |  | USART2_RX
 |  |  |  |  |  |  |  |  |  |  |  |  |  | USART2_TX
BOOT | PG3 |  |  |  |  |  |  |  |  |  |  |  |  | USART3_RX
QSPI GPIO |  |  |  |  |  |  |  |  |  |  |  |  |  | USART3_TX
IO0 | PF8 |  |  |  |  |  |  |  |  |  |  |  |  | USART6_RX
IO1 | PF9
IO2 | PF7
IO3 | PF6
CLK | PF10
NCS | PG6

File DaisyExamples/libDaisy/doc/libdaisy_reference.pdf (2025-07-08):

## libDaisy

Generated by Doxygen 1.9.1

i

1 Main Page | 1
1.0.1 Features | | 1
1.0.2 Code Example | | 1
1.0.3 Getting Started | | 2
1.0.4 Project Overview | | 2
1.0.4.1 daisy.h | | 2
1.0.4.2 daisy_seed.h | | 2
1.0.4.3 daisy_platform.h | | 3
1.0.5 Contributing | | 3
1.0.6 Support | | 3
1.0.7 License | | 3
2 Module Index | 5
2.1 Modules | | 5
3 Namespace Index | 7
3.1 Namespace List | | 7
4 Class Index | 9
4.1 Class List | | 9
5 File Index | 13
5.1 File List | | 13
6 Module Documentation | 15
6.1 LIBDAISY | | 15
6.1.1 Detailed Description | | 15
6.2 HUMAN_INTERFACE | | 15
6.2.1 Detailed Description | | 16
6.3 AUDIO | | 16
6.4 CONTROLS | | 16
6.4.1 Detailed Description | | 16
6.5 FEEDBACK | | 17
6.5.1 Detailed Description | | 17
6.6 EXTERNAL | | 17
6.6.1 Detailed Description | | 18
6.6.2 Macro Definition Documentation | | 18
6.6.2.1 FLT_FMT | | 18
6.6.2.2 FLT_FMT3 | | 19
6.6.2.3 FLT_VAR | | 19
6.6.2.4 FLT_VAR3 | | 19
6.6.2.5 LOGGER_BUFFER | | 19
6.6.2.6 LOGGER_NEWLINE | | 19
6.6.2.7 PPCAT | | 19

Generated by Doxygen

ii

6.6.2.8 PPCAT_NX | | 20
6.6.2.9 STRINGIZE | | 20
6.6.2.10 STRINGIZE_NX | | 20
6.6.3 Enumeration Type Documentation | | 20
6.6.3.1 LoggerConsts | | 20
6.6.3.2 MidiMessageType | | 20
6.6.4 Function Documentation | | 21
6.6.4.1 AppendNewLine() | | 21
6.6.4.2 Logger() | | 21
6.6.4.3 NewLineSeqLength() | | 21
6.6.4.4 Print() | | 21
6.6.4.5 PrintLine() | | 22
6.6.4.6 PrintLineV() | | 22
6.6.4.7 PrintV() | | 22
6.6.4.8 StartLog() | | 22
6.6.4.9 TransmitBuf() | | 22
6.6.4.10 TransmitSync() | | 23
6.6.5 Variable Documentation | | 23
6.6.5.1 impl_ | | 23
6.6.5.2 pc_sync_ | | 23
6.6.5.3 tx_buff_ | | 23
6.6.5.4 tx_ptr_ | | 23
6.7 PERIPHERAL | | 24
6.7.1 Detailed Description | | 24
6.8 SERIAL | | 24
6.8.1 Detailed Description | | 25
6.8.2 Enumeration Type Documentation | | 25
6.8.2.1 dsy_qspi_device | | 25
6.8.2.2 dsy_qspi_mode | | 25
6.8.2.3 dsy_qspi_pin | | 25
6.8.2.4 SpiPeriph | | 26
6.8.2.5 SpiPin | | 26
6.8.3 Function Documentation | | 26
6.8.3.1 dsy_qspi_deinit() | | 27
6.8.3.2 dsy_qspi_erase() | | 27
6.8.3.3 dsy_qspi_erasesector() | | 27
6.8.3.4 dsy_qspi_init() | | 28
6.8.3.5 dsy_qspi_write() | | 28
6.8.3.6 dsy_qspi_writepage() | | 28
6.9 ANALOG_DIGITAL_CONVERSION | | 29
6.9.1 Detailed Description | | 29
6.10 OTHER | | 29

iii

6.10.1 Detailed Description | | 30
6.10.2 Enumeration Type Documentation | | 30
6.10.2.1 dsy_gpio_mode | | 30
6.10.2.2 dsy_gpio_pull | | 30
6.10.2.3 SdmmcBitWidth | | 30
6.10.2.4 SdmmcMode | | 31
6.10.2.5 SdmmcSpeed | | 31
6.10.3 Function Documentation | | 31
6.10.3.1 dsy_gpio_deinit() | | 31
6.10.3.2 dsy_gpio_init() | | 32
6.10.3.3 dsy_gpio_read() | | 32
6.10.3.4 dsy_gpio_toggle() | | 32
6.10.3.5 dsy_gpio_write() | | 33
6.11 SYSTEM | | 33
6.11.1 Detailed Description | | 33
6.11.2 Function Documentation | | 33
6.11.2.1 dsy_dma_clear_cache_for_buffer() | | 34
6.11.2.2 dsy_dma_init() | | 34
6.11.2.3 dsy_dma_invalidate_cache_for_buffer() | | 34
6.12 DEVICE | | 34
6.12.1 Detailed Description | | 35
6.13 SHIFTREGISTER | | 35
6.13.1 Detailed Description | | 35
6.14 FLASH | | 36
6.14.1 Detailed Description | | 39
6.14.2 Macro Definition Documentation | | 39
6.14.2.1 BLOCK_ERASE_32K_CMD [1/2] | | 39
6.14.2.2 BLOCK_ERASE_32K_CMD [2/2] | | 39
6.14.2.3 BLOCK_ERASE_CMD [1/2] | | 39
6.14.2.4 BLOCK_ERASE_CMD [2/2] | | 40
6.14.2.5 CHIP_ERASE_CMD [1/2] | | 40
6.14.2.6 CHIP_ERASE_CMD [2/2] | | 40
6.14.2.7 CLEAR_EXT_READ_PARAM_CMD | | 40
6.14.2.8 DUAL_INOUT_FAST_READ_CMD [1/2] | | | 40
6.14.2.9 DUAL_INOUT_FAST_READ_CMD [2/2] | | | 40
6.14.2.10 DUAL_INOUT_FAST_READ_DTR_CMD [1/2] | | 40
6.14.2.11 DUAL_INOUT_FAST_READ_DTR_CMD [2/2] | | 41
6.14.2.12 DUAL_OUT_FAST_READ_CMD [1/2] | | 41
6.14.2.13 DUAL_OUT_FAST_READ_CMD [2/2] | | 41
6.14.2.14 ENTER_DEEP_POWER_DOWN [1/2] | | 41
6.14.2.15 ENTER_DEEP_POWER_DOWN [2/2] | | 41
6.14.2.16 ENTER_QUAD_CMD [1/2] | | 41

iv

6.14.2.17 ENTER_QUAD_CMD [2/2] | | 41
6.14.2.18 EXIT_DEEP_POWER_DOWN [1/2] | | 41
6.14.2.19 EXIT_DEEP_POWER_DOWN [2/2] | | 42
6.14.2.20 EXIT_QUAD_CMD [1/2] | | 42
6.14.2.21 EXIT_QUAD_CMD [2/2] | | 42
6.14.2.22 EXT_CHIP_ERASE_CMD [1/2] | | | 42
6.14.2.23 EXT_CHIP_ERASE_CMD [2/2] | | | 42
6.14.2.24 EXT_PROG_ERASE_RESUME_CMD [1/2] | | 42
6.14.2.25 EXT_PROG_ERASE_RESUME_CMD [2/2] | | 42
6.14.2.26 EXT_PROG_ERASE_SUSPEND_CMD [1/2] | | 42
6.14.2.27 EXT_PROG_ERASE_SUSPEND_CMD [2/2] | | 43
6.14.2.28 EXT_QUAD_IN_FAST_PROG_CMD | | 43
6.14.2.29 EXT_QUAD_IN_PAGE_PROG_CMD [1/2] | | 43
6.14.2.30 EXT_QUAD_IN_PAGE_PROG_CMD [2/2] | | 43
6.14.2.31 EXT_WRITE_READ_PARAM_REG_CMD | | 43
6.14.2.32 FAST_READ_CMD [1/2] | | 43
6.14.2.33 FAST_READ_CMD [2/2] | | 43
6.14.2.34 FAST_READ_DTR_CMD [1/2] | | 43
6.14.2.35 FAST_READ_DTR_CMD [2/2] | | 44
6.14.2.36 INFO_ROW_ERASE_CMD [1/2] | | 44
6.14.2.37 INFO_ROW_ERASE_CMD [2/2] | | 44
6.14.2.38 INFO_ROW_PROGRAM_CMD [1/2] | | 44
6.14.2.39 INFO_ROW_PROGRAM_CMD [2/2] | | 44
6.14.2.40 INFO_ROW_READ_CMD [1/2] | | | 44
6.14.2.41 INFO_ROW_READ_CMD [2/2] | | | 44
6.14.2.42 IS25LP064A_EAR_HIGHEST_SE | | 44
6.14.2.43 IS25LP064A_EAR_LOWEST_SEG | | 45
6.14.2.44 IS25LP064A_EAR_SECOND_SEG | | 45
6.14.2.45 IS25LP064A_EAR_THIRD_SEG | | 45
6.14.2.46 IS25LP064A_EVCR_DTRP | | 45
6.14.2.47 IS25LP064A_EVCR_DUAL | | 45
6.14.2.48 IS25LP064A_EVCR_ODS | | 45
6.14.2.49 IS25LP064A_EVCR_QUAD | | 45
6.14.2.50 IS25LP064A_EVCR_RH | | 45
6.14.2.51 IS25LP064A_FSR_ERERR | | 46
6.14.2.52 IS25LP064A_FSR_ERSUS | | 46
6.14.2.53 IS25LP064A_FSR_NBADDR | | 46
6.14.2.54 IS25LP064A_FSR_PGERR | | 46
6.14.2.55 IS25LP064A_FSR_PGSUS | | 46
6.14.2.56 IS25LP064A_FSR_PRERR | | 46
6.14.2.57 IS25LP064A_FSR_READY | | 46
6.14.2.58 IS25LP064A_NVCR_DTRP | | 46

v

6.14.2.59 IS25LP064A_NVCR_DUAL | | 47
6.14.2.60 IS25LP064A_NVCR_NB_DUMMY | | 47
6.14.2.61 IS25LP064A_NVCR_NBADDR | | 47
6.14.2.62 IS25LP064A_NVCR_ODS | | 47
6.14.2.63 IS25LP064A_NVCR_QUAB | | 47
6.14.2.64 IS25LP064A_NVCR_RH | | 47
6.14.2.65 IS25LP064A_NVCR_SEGMENT | | 47
6.14.2.66 IS25LP064A_NVCR_XIP | | 47
6.14.2.67 IS25LP064A_SR_QE | | 48
6.14.2.68 IS25LP064A_SR_SRWREN | | 48
6.14.2.69 IS25LP064A_SR_WIP | | 48
6.14.2.70 IS25LP064A_SR_WREN | | 48
6.14.2.71 IS25LP064A_VCR_NB_DUMMY | | 48
6.14.2.72 IS25LP064A_VCR_WRAP | | 48
6.14.2.73 IS25LP064A_VCR_XIP | | 48
6.14.2.74 IS25LP080D_EAR_HIGHEST_SE | | 49
6.14.2.75 IS25LP080D_EAR_LOWEST_SEG | | 49
6.14.2.76 IS25LP080D_EAR_SECOND_SEG | | 49
6.14.2.77 IS25LP080D_EAR_THIRD_SEG | | 49
6.14.2.78 IS25LP080D_EVCR_DTRP | | 49
6.14.2.79 IS25LP080D_EVCR_DUAL | | 49
6.14.2.80 IS25LP080D_EVCR_ODS | | 49
6.14.2.81 IS25LP080D_EVCR_QUAD | | 49
6.14.2.82 IS25LP080D_EVCR_RH | | 50
6.14.2.83 IS25LP080D_FSR_ERERR | | 50
6.14.2.84 IS25LP080D_FSR_ERSUS | | 50
6.14.2.85 IS25LP080D_FSR_NBADDR | | 50
6.14.2.86 IS25LP080D_FSR_PGERR | | 50
6.14.2.87 IS25LP080D_FSR_PGSUS | | 50
6.14.2.88 IS25LP080D_FSR_PRERR | | 50
6.14.2.89 IS25LP080D_FSR_READY | | 50
6.14.2.90 IS25LP080D_NVCR_DTRP | | 51
6.14.2.91 IS25LP080D_NVCR_DUAL | | 51
6.14.2.92 IS25LP080D_NVCR_NB_DUMMY | | 51
6.14.2.93 IS25LP080D_NVCR_NBADDR | | 51
6.14.2.94 IS25LP080D_NVCR_ODS | | 51
6.14.2.95 IS25LP080D_NVCR_QUAB | | 51
6.14.2.96 IS25LP080D_NVCR_RH | | 51
6.14.2.97 IS25LP080D_NVCR_SEGMENT | | 51
6.14.2.98 IS25LP080D_NVCR_XIP | | 52
6.14.2.99 IS25LP080D_SR_QE | | 52
6.14.2.100 IS25LP080D_SR_SRWREN | | 52

vi

6.14.2.101 IS25LP080D_SR_WIP | | 52
6.14.2.102 IS25LP080D_SR_WREN | | 52
6.14.2.103 IS25LP080D_VCR_NB_DUMMY | | 52
6.14.2.104 IS25LP080D_VCR_WRAP | | 52
6.14.2.105 IS25LP080D_VCR_XIP | | 53
6.14.2.106 MULTIPLE_IO_READ_ID_CMD [1/2] | | 53
6.14.2.107 MULTIPLE_IO_READ_ID_CMD [2/2] | | 53
6.14.2.108 NO_OP [1/2] | | | 53
6.14.2.109 NO_OP [2/2] | | | 53
6.14.2.110 PAGE_PROG_CMD [1/3] | | 53
6.14.2.111 PAGE_PROG_CMD [2/3] | | 53
6.14.2.112 PAGE_PROG_CMD [3/3] | | 54
6.14.2.113 PROG_ERASE_RESUME_CMD [1/2] | | 54
6.14.2.114 PROG_ERASE_RESUME_CMD [2/2] | | 54
6.14.2.115 PROG_ERASE_SUSPEND_CMD [1/2] | | | 54
6.14.2.116 PROG_ERASE_SUSPEND_CMD [2/2] | | | 54
6.14.2.117 QUAD_IN_FAST_PROG_CMD | | 54
6.14.2.118 QUAD_IN_PAGE_PROG_CMD [1/2] | | 54
6.14.2.119 QUAD_IN_PAGE_PROG_CMD [2/2] | | 55
6.14.2.120 QUAD_INOUT_FAST_READ_CMD [1/2] | | 55
6.14.2.121 QUAD_INOUT_FAST_READ_CMD [2/2] | | 55
6.14.2.122 QUAD_INOUT_FAST_READ_DTR_CMD [1/2] | | 55
6.14.2.123 QUAD_INOUT_FAST_READ_DTR_CMD [2/2] | | 55
6.14.2.124 QUAD_OUT_FAST_READ_CMD [1/2] | | 55
6.14.2.125 QUAD_OUT_FAST_READ_CMD [2/2] | | 55
6.14.2.126 READ_CMD [1/2] | | 55
6.14.2.127 READ_CMD [2/2] | | 56
6.14.2.128 READ_EXT_READ_PARAM_CMD | | 56
6.14.2.129 READ_FUNCTION_REGISTER [1/2] | | 56
6.14.2.130 READ_FUNCTION_REGISTER [2/2] | | 56
6.14.2.131 READ_ID_CMD [1/2] | | 56
6.14.2.132 READ_ID_CMD [2/2] | | 56
6.14.2.133 READ_ID_CMD2 [1/2] | | | 56
6.14.2.134 READ_ID_CMD2 [2/2] | | | 56
6.14.2.135 READ_MANUFACT_AND_ID [1/2] | | 57
6.14.2.136 READ_MANUFACT_AND_ID [2/2] | | 57
6.14.2.137 READ_READ_PARAM_REG_CMD | | 57
6.14.2.138 READ_SERIAL_FLASH_DISCO_PARAM_CMD [1/2] | | 57
6.14.2.139 READ_SERIAL_FLASH_DISCO_PARAM_CMD [2/2] | | 57
6.14.2.140 READ_STATUS_REG_CMD [1/2] | | | 57
6.14.2.141 READ_STATUS_REG_CMD [2/2] | | | 57
6.14.2.142 READ_UNIQUE_ID [1/2] | | 57

vii

6.14.2.143 READ_UNIQUE_ID [2/2] | | 58
6.14.2.144 RESET_ENABLE_CMD [1/2] | | 58
6.14.2.145 RESET_ENABLE_CMD [2/2] | | 58
6.14.2.146 RESET_MEMORY_CMD [1/2] | | | 58
6.14.2.147 RESET_MEMORY_CMD [2/2] | | | 58
6.14.2.148 SECTOR_ERASE_CMD [1/2] | | 58
6.14.2.149 SECTOR_ERASE_CMD [2/2] | | 58
6.14.2.150 SECTOR_ERASE_QPI_CMD [1/2] | | 58
6.14.2.151 SECTOR_ERASE_QPI_CMD [2/2] | | 59
6.14.2.152 SECTOR_LOCK [1/2] | | 59
6.14.2.153 SECTOR_LOCK [2/2] | | 59
6.14.2.154 SECTOR_UNLOCK [1/2] | | 59
6.14.2.155 SECTOR_UNLOCK [2/2] | | 59
6.14.2.156 WRITE_DISABLE_CMD [1/2] | | 59
6.14.2.157 WRITE_DISABLE_CMD [2/2] | | 59
6.14.2.158 WRITE_ENABLE_CMD [1/2] | | 59
6.14.2.159 WRITE_ENABLE_CMD [2/2] | | 60
6.14.2.160 WRITE_EXT_NV_READ_PARAM_REG_CMD | | 60
6.14.2.161 WRITE_EXT_READ_PARAM_REG_CMD | | 60
6.14.2.162 WRITE_FUNCTION_REGISTER [1/2] | | 60
6.14.2.163 WRITE_FUNCTION_REGISTER [2/2] | | 60
6.14.2.164 WRITE_NV_READ_PARAM_REG_CMD | | 60
6.14.2.165 WRITE_READ_PARAM_REG_CMD [1/2] | | | 60
6.14.2.166 WRITE_READ_PARAM_REG_CMD [2/2] | | | 60
6.14.2.167 WRITE_STATUS_REG_CMD [1/2] | | 61
6.14.2.168 WRITE_STATUS_REG_CMD [2/2] | | 61
6.15 CODEC | | 61
6.16 LED | | 61
6.17 SDRAM | | 61
6.17.1 Detailed Description | | 62
6.17.2 Macro Definition Documentation | | 62
6.17.2.1 DSY_SDRAM_BSS | | 62
6.17.2.2 DSY_SDRAM_DATA | | 62
6.17.3 Enumeration Type Documentation | | 62
6.17.3.1 anonymous enum | | 62
6.17.3.2 dsy_sdram_pin | | 63
6.17.3.3 dsy_sdram_state | | 63
6.17.4 Function Documentation | | 63
6.17.4.1 dsy_sdram_init() | | 63
6.18 BOARDS | | 63
6.18.1 Detailed Description | | 64
6.19 UTILITY | | 64

viii

6.19.1 Detailed Description | | 66
6.19.2 Macro Definition Documentation | | 66
6.19.2.1 BSP_SD_CardInfo | | 66
6.19.2.2 DMA_BUFFER_MEM_SECTION | | 66
6.19.2.3 DTCM_MEM_SECTION | | 66
6.19.2.4 F2S16_SCALE | | 66
6.19.2.5 F2S24_SCALE | | 66
6.19.2.6 F2S32_SCALE | | 66
6.19.2.7 FBIPMAX | | 67
6.19.2.8 FBIPMIN | | 67
6.19.2.9 MSD_ERROR | | 67
6.19.2.10 MSD_ERROR_SD_NOT_PRESENT | | 67
6.19.2.11 MSD_OK | | 67
6.19.2.12 S162F_SCALE | | 67
6.19.2.13 S242F_SCALE | | 67
6.19.2.14 S24SIGN | | 68
6.19.2.15 S322F_SCALE | | 68
6.19.2.16 SD_DATATIMEOUT | | 68
6.19.2.17 SD_NOT_PRESENT | | 68
6.19.2.18 SD_PRESENT | | 68
6.19.2.19 SD_TRANSFER_BUSY | | 68
6.19.2.20 SD_TRANSFER_OK | | 68
6.19.3 Enumeration Type Documentation | | 68
6.19.3.1 dsy_gpio_port | | 68
6.19.4 Function Documentation | | 69
6.19.4.1 BSP_SD_AbortCallback() | | 69
6.19.4.2 BSP_SD_Erase() | | 69
6.19.4.3 BSP_SD_GetCardInfo() | | 70
6.19.4.4 BSP_SD_GetCardState() | | 70
6.19.4.5 BSP_SD_Init() | | 70
6.19.4.6 BSP_SD_IsDetected() | | 70
6.19.4.7 BSP_SD_ITConfig() | | 71
6.19.4.8 BSP_SD_ReadBlocks() | | 71
6.19.4.9 BSP_SD_ReadBlocks_DMA() | | 71
6.19.4.10 BSP_SD_ReadCpltCallback() | | 72
6.19.4.11 BSP_SD_WriteBlocks() | | 72
6.19.4.12 BSP_SD_WriteBlocks_DMA() | | 72
6.19.4.13 BSP_SD_WriteCpltCallback() | | 73
6.19.4.14 cube() | | 73
6.19.4.15 dsy_get_unique_id() | | 73
6.19.4.16 dsy_hal_map_get_pin() | | 74
6.19.4.17 dsy_hal_map_get_port() | | 74

ix

6.19.4.18 dsy_pin() | | 74
6.19.4.19 dsy_pin_cmp() | | 75
6.19.4.20 f2s16() | | 75
6.19.4.21 f2s24() | | 75
6.19.4.22 f2s32() | | 76
6.19.4.23 s162f() | | 76
6.19.4.24 s242f() | | 76
6.19.4.25 s322f() | | 76
6.19.5 Variable Documentation | | 77
6.19.5.1 Font_11x18 | | 77
6.19.5.2 Font_16x26 | | 77
6.19.5.3 Font_6x8 | | 77
6.19.5.4 Font_7x10 | | 77
6.20 USBD_CDC_IF | | 77
6.20.1 Detailed Description | | 78
6.21 USBD_CDC_IF_Exported_Defines | | 78
6.22 USBD_CDC_IF_Exported_Types | | 78
6.22.1 Detailed Description | | 78
6.22.2 Typedef Documentation | | 78
6.22.2.1 CDC_ReceiveCallback | | 78
6.23 USBD_CDC_IF_Exported_Macros | | 78
6.24 USBD_CDC_IF_Exported_Variables | | 79
6.24.1 Detailed Description | | 79
6.24.2 Variable Documentation | | 79
6.24.2.1 USBD_Interface_fops_FS | | 79
6.24.2.2 USBD_Interface_fops_HS | | 79
6.25 USBD_CDC_IF_Exported_FunctionsPrototype | | 79
6.25.1 Detailed Description | | 79
6.25.2 Function Documentation | | 80
6.25.2.1 CDC_Set_Rx_Callback_FS() | | 80
6.25.2.2 CDC_Set_Rx_Callback_HS() | | 80
6.25.2.3 CDC_Transmit_FS() | | 80
6.25.2.4 CDC_Transmit_HS() | | 80
6.26 USBD_CONF | | 80
6.26.1 Detailed Description | | 81
6.27 USBD_CONF_Exported_Variables | | 81
6.28 USBD_CONF_Exported_Defines | | 81
6.28.1 Detailed Description | | 81
6.28.2 Macro Definition Documentation | | 81
6.28.2.1 DEVICE_FS | | 81
6.28.2.2 DEVICE_HS | | 81
6.28.2.3 USBD_DEBUG_LEVEL | | 82

x

6.28.2.4 USBD_LPM_ENABLED | | 82
6.28.2.5 USBD_MAX_NUM_CONFIGURATION | | 82
6.28.2.6 USBD_MAX_NUM_INTERFACES | | 82
6.28.2.7 USBD_MAX_STR_DESC_SIZ | | 82
6.28.2.8 USBD_SELF_POWERED | | 82
6.28.2.9 USBD_SUPPORT_USER_STRING | | 82
6.29 USBD_CONF_Exported_Macros | | 82
6.29.1 Detailed Description | | 83
6.29.2 Macro Definition Documentation | | 83
6.29.2.1 USBD_DbgLog | | 83
6.29.2.2 USBD_Delay | | 83
6.29.2.3 USBD_ErrLog | | 83
6.29.2.4 USBD_free | | 84
6.29.2.5 USBD_malloc | | 84
6.29.2.6 USBD_memcpy | | 84
6.29.2.7 USBD_memset | | 84
6.29.2.8 USBD_UsrLog | | 84
6.30 USBD_CONF_Exported_Types | | 84
6.31 USBD_CONF_Exported_FunctionsPrototype | | 84
6.32 USBD_DESC | | 85
6.32.1 Detailed Description | | 85
6.33 USBD_DESC_Exported_Constants | | 85
6.33.1 Detailed Description | | 85
6.33.2 Macro Definition Documentation | | 85
6.33.2.1 DEVICE_ID1 | | 86
6.33.2.2 DEVICE_ID2 | | 86
6.33.2.3 DEVICE_ID3 | | 86
6.33.2.4 USB_SIZ_STRING_SERIAL | | 86
6.34 USBD_DESC_Exported_Defines | | 86
6.35 USBD_DESC_Exported_TypesDefinitions | | 86
6.36 USBD_DESC_Exported_Macros | | 86
6.37 USBD_DESC_Exported_Variables | | 87
6.37.1 Detailed Description | | 87
6.37.2 Variable Documentation | | 87
6.37.2.1 FS_Desc | | 87
6.37.2.2 HS_Desc | | 87
6.38 USBD_DESC_Exported_FunctionsPrototype | | 87
6.39 Externals | | 87
6.40 STM32_USB_OTG_DEVICE_LIBRARY | | 87
6.40.1 Detailed Description | | 88
6.41 USBD_OTG_DRIVER | | 88
6.41.1 Detailed Description | | 88

xi

7 Namespace Documentation | 89
7.1 daisy Namespace Reference | | 89
7.1.1 Detailed Description | | 91
7.1.2 Enumeration Type Documentation | | 91
7.1.2.1 LoggerDestination | | 91
7.1.3 Function Documentation | | 91
7.1.3.1 dsy_i2c_global_init() | | 91
8 Class Documentation | 93
8.1 daisy::AdcChannelConfig Struct Reference | | 93
8.1.1 Detailed Description | | 93
8.1.2 Member Enumeration Documentation | | 93
8.1.2.1 MuxPin | | 93
8.1.3 Member Function Documentation | | 94
8.1.3.1 InitMux() | | 94
8.1.3.2 InitSingle() | | 94
8.1.4 Member Data Documentation | | 95
8.1.4.1 mux_channels_ | | 95
8.1.4.2 mux_pin_ | | 95
8.1.4.3 pin_ | | 95
8.2 daisy::AdcHandle Class Reference | | 95
8.2.1 Detailed Description | | 96
8.2.2 Member Enumeration Documentation | | 96
8.2.2.1 OverSampling | | 96
8.2.3 Member Function Documentation | | 96
8.2.3.1 Get() | | 96
8.2.3.2 GetFloat() | | 97
8.2.3.3 GetMux() | | 97
8.2.3.4 GetMuxFloat() | | 97
8.2.3.5 GetMuxPtr() | | 98
8.2.3.6 GetPtr() | | 98
8.2.3.7 Init() | | 99
8.2.3.8 Start() | | 99
8.2.3.9 Stop() | | 99
8.3 daisy::Ak4556 Class Reference | | 99
8.3.1 Member Function Documentation | | 99
8.3.1.1 Init() | 100
8.4 daisy::AnalogControl Class Reference | 100
8.4.1 Detailed Description | 100
8.4.2 Constructor & Destructor Documentation | 101
8.4.2.1 AnalogControl() | 101
8.4.2.2 ∼AnalogControl() | 101

xii

8.4.3 Member Function Documentation | 101
8.4.3.1 GetRawFloat() | 101
8.4.3.2 GetRawValue() | 101
8.4.3.3 Init() | 101
8.4.3.4 InitBipolarCv() | 102
8.4.3.5 Process() | 102
8.4.3.6 SetCoeff() | 102
8.4.3.7 Value() | 102
8.5 daisy::AudioHandle Class Reference | 103
8.5.1 Member Typedef Documentation | 103
8.5.1.1 AudioCallback | 103
8.5.1.2 InterleavingAudioCallback | 103
8.5.2 Member Function Documentation | 104
8.5.2.1 ChangeCallback() [1/2] | 104
8.5.2.2 ChangeCallback() [2/2] | 104
8.5.2.3 GetChannels() | 104
8.5.2.4 GetConfig() | 104
8.5.2.5 GetSampleRate() | 104
8.5.2.6 Init() [1/2] | | 104
8.5.2.7 Init() [2/2] | | 105
8.5.2.8 SetBlockSize() | 105
8.5.2.9 SetPostGain() | 105
8.5.2.10 SetSampleRate() | 105
8.5.2.11 Start() [1/2] | 105
8.5.2.12 Start() [2/2] | 105
8.5.2.13 Stop() | 106
8.6 daisy::Color Class Reference | 106
8.6.1 Detailed Description | 106
8.6.2 Member Enumeration Documentation | 106
8.6.2.1 PresetColor | 106
8.6.3 Member Function Documentation | 107
8.6.3.1 Blue() | 107
8.6.3.2 Green() | 107
8.6.3.3 Init() [1/2] | | 107
8.6.3.4 Init() [2/2] | | 108
8.6.3.5 Red() | 108
8.7 daisy::AudioHandle::Config Struct Reference | 108
8.7.1 Detailed Description | 108
8.8 daisy::DacHandle::Config Struct Reference | 108
8.8.1 Detailed Description | 109
8.8.2 Member Data Documentation | 109
8.8.2.1 target_samplerate | 109

xiii

8.9 daisy::I2CHandle::Config Struct Reference | 109
8.9.1 Detailed Description | 110
8.9.2 Member Enumeration Documentation | 110
8.9.2.1 Peripheral | 110
8.9.2.2 Speed | 110
8.9.3 Member Data Documentation | 110
8.9.3.1 periph | 111
8.9.3.2 | 111
8.9.3.3 scl | 111
8.9.3.4 sda | 111
8.9.3.5 speed | 111
8.10 daisy::SaiHandle::Config Struct Reference | 111
8.10.1 Detailed Description | 112
8.10.2 Member Enumeration Documentation | 112
8.10.2.1 BitDepth | 112
8.10.2.2 Direction | 112
8.10.2.3 Peripheral | 112
8.10.2.4 SampleRate | 113
8.10.2.5 Sync | 113
8.11 daisy::ShiftRegister4021< num_daisychained, num_parallel >::Config Struct Reference | 113
8.11.1 Detailed Description | 113
8.11.2 Member Data Documentation | 113
8.11.2.1 clk | 113
8.11.2.2 data | 114
8.11.2.3 latch | 114
8.12 daisy::System::Config Struct Reference | 114
8.12.1 Detailed Description | 114
8.12.2 Member Enumeration Documentation | 114
8.12.2.1 SysClkFreq | 115
8.12.3 Member Function Documentation | 115
8.12.3.1 Boost() | 115
8.12.3.2 Defaults() | 115
8.13 daisy::TimerHandle::Config Struct Reference | 115
8.13.1 Member Enumeration Documentation | 115
8.13.1.1 CounterDir | 115
8.13.1.2 Peripheral | 115
8.14 daisy::Wm8731::Config Struct Reference | 116
8.14.1 Detailed Description | 116
8.14.2 Member Enumeration Documentation | 116
8.14.2.1 Format | 117
8.14.2.2 WordLength | 117
8.14.3 Member Function Documentation | 117

xiv

8.14.3.1 Defaults() | 117
8.14.4 Member Data Documentation | 117
8.14.4.1 csb_pin_state | 117
8.14.4.2 lr_swap | 117
8.14.4.3 mcu_is_master | 118
8.15 daisy::ControlChangeEvent Struct Reference | 118
8.15.1 Detailed Description | 118
8.15.2 Member Data Documentation | 118
8.15.2.1 channel | 118
8.15.2.2 control_number | 118
8.15.2.3 value | 119
8.16 daisy::DacHandle Class Reference | 119
8.16.1 Detailed Description | 119
8.16.2 Member Typedef Documentation | 120
8.16.2.1 DacCallback | 120
8.16.3 Member Enumeration Documentation | 120
8.16.3.1 BitDepth | 120
8.16.3.2 BufferState | 120
8.16.3.3 Channel | 120
8.16.3.4 Mode | 120
8.16.3.5 Result | 121
8.16.4 Member Function Documentation | 121
8.16.4.1 Init() | 121
8.16.4.2 Start() [1/2] | 121
8.16.4.3 Start() [2/2] | 121
8.16.4.4 Stop() | 121
8.16.4.5 WriteValue() | 122
8.17 daisy::DaisyField Class Reference | 122
8.17.1 Member Enumeration Documentation | 123
8.17.1.1 anonymous enum | 123
8.17.1.2 anonymous enum | 123
8.17.1.3 anonymous enum | 124
8.17.1.4 anonymous enum | 124
8.17.2 Member Function Documentation | 125
8.17.2.1 AudioBlockSize() | 125
8.17.2.2 AudioCallbackRate() | 125
8.17.2.3 AudioSampleRate() | 125
8.17.2.4 ChangeAudioCallback() [1/2] | | 125
8.17.2.5 ChangeAudioCallback() [2/2] | | 126
8.17.2.6 DelayMs() | 126
8.17.2.7 GetCv() | 126
8.17.2.8 GetCvValue() | 127

xv

8.17.2.9 GetKnob() | 127
8.17.2.10 GetKnobValue() | 127
8.17.2.11 GetSwitch() | 127
8.17.2.12 Init() | 128
8.17.2.13 KeyboardFallingEdge() | 128
8.17.2.14 KeyboardRisingEdge() | 128
8.17.2.15 KeyboardState() | 128
8.17.2.16 ProcessAllControls() | 129
8.17.2.17 ProcessAnalogControls() | 129
8.17.2.18 ProcessDigitalControls() | 129
8.17.2.19 SetAudioBlockSize() | 129
8.17.2.20 SetAudioSampleRate() | 129
8.17.2.21 SetCvOut1() | 129
8.17.2.22 SetCvOut2() | 130
8.17.2.23 StartAdc() | 130
8.17.2.24 StartAudio() [1/2] | 130
8.17.2.25 StartAudio() [2/2] | 130
8.17.2.26 StartDac() | 130
8.17.2.27 StopAdc() | 130
8.17.2.28 StopAudio() | 130
8.17.2.29 VegasMode() | 131
8.18 daisy::DaisyPatch Class Reference | 131
8.18.1 Detailed Description | 132
8.18.2 Member Enumeration Documentation | 132
8.18.2.1 Ctrl | 132
8.18.2.2 GateInput | 132
8.18.3 Constructor & Destructor Documentation | 132
8.18.3.1 DaisyPatch() | 133
8.18.3.2 ∼DaisyPatch() | 133
8.18.4 Member Function Documentation | 133
8.18.4.1 AudioBlockSize() | 133
8.18.4.2 AudioCallbackRate() | 133
8.18.4.3 AudioSampleRate() | 133
8.18.4.4 ChangeAudioCallback() | 133
8.18.4.5 DelayMs() | 134
8.18.4.6 DisplayControls() | 134
8.18.4.7 GetKnobValue() | 134
8.18.4.8 Init() | 134
8.18.4.9 ProcessAllControls() | 134
8.18.4.10 ProcessAnalogControls() | 135
8.18.4.11 ProcessDigitalControls() | 135
8.18.4.12 SetAudioBlockSize() | 135

xvi

8.18.4.13 SetAudioSampleRate() | 135
8.18.4.14 StartAdc() | 135
8.18.4.15 StartAudio() | 135
8.18.4.16 StopAdc() | 136
8.18.4.17 StopAudio() | 136
8.18.5 Member Data Documentation | 136
8.18.5.1 controls | 136
8.18.5.2 display | 136
8.18.5.3 encoder | 136
8.18.5.4 gate_input | 136
8.18.5.5 gate_output | 136
8.18.5.6 midi | 137
8.18.5.7 seed | 137
8.19 daisy::DaisyPetal Class Reference | 137
8.19.1 Detailed Description | 138
8.19.2 Member Enumeration Documentation | 138
8.19.2.1 FootswitchLed | 138
8.19.2.2 Knob | 139
8.19.2.3 RingLed | 139
8.19.2.4 Sw | 140
8.19.3 Constructor & Destructor Documentation | 140
8.19.3.1 DaisyPetal() | 140
8.19.3.2 ∼DaisyPetal() | 140
8.19.4 Member Function Documentation | 140
8.19.4.1 AudioBlockSize() | 140
8.19.4.2 AudioCallbackRate() | 141
8.19.4.3 AudioSampleRate() | 141
8.19.4.4 ChangeAudioCallback() [1/2] | | 141
8.19.4.5 ChangeAudioCallback() [2/2] | | 141
8.19.4.6 ClearLeds() | 141
8.19.4.7 DelayMs() | 142
8.19.4.8 GetExpression() | 143
8.19.4.9 GetKnobValue() | 143
8.19.4.10 Init() | 143
8.19.4.11 ProcessAllControls() | 143
8.19.4.12 ProcessAnalogControls() | 143
8.19.4.13 ProcessDigitalControls() | 144
8.19.4.14 SetAudioBlockSize() | 144
8.19.4.15 SetAudioSampleRate() | 144
8.19.4.16 SetFootswitchLed() | 144
8.19.4.17 SetRingLed() | 144
8.19.4.18 StartAdc() | 146

xvii

8.19.4.19 StartAudio() [1/2] | 146
8.19.4.20 StartAudio() [2/2] | 146
8.19.4.21 StopAdc() | 146
8.19.4.22 StopAudio() | 146
8.19.4.23 UpdateLeds() | 146
8.19.5 Member Data Documentation | 147
8.19.5.1 encoder | 147
8.19.5.2 expression | 147
8.19.5.3 footswitch_led | 147
8.19.5.4 knob | 147
8.19.5.5 ring_led | 147
8.19.5.6 seed | 147
8.19.5.7 switches | 147
8.20 daisy::DaisyPod Class Reference | 148
8.20.1 Detailed Description | 149
8.20.2 Member Enumeration Documentation | 149
8.20.2.1 Knob | 149
8.20.2.2 Sw | 149
8.20.3 Member Function Documentation | 149
8.20.3.1 AudioBlockSize() | 150
8.20.3.2 AudioCallbackRate() | 150
8.20.3.3 AudioSampleRate() | 150
8.20.3.4 ChangeAudioCallback() [1/2] | | 150
8.20.3.5 ChangeAudioCallback() [2/2] | | 150
8.20.3.6 ClearLeds() | 150
8.20.3.7 DelayMs() | 151
8.20.3.8 GetKnobValue() | 151
8.20.3.9 Init() | 151
8.20.3.10 ProcessAllControls() | 151
8.20.3.11 ProcessAnalogControls() | 151
8.20.3.12 ProcessDigitalControls() | 151
8.20.3.13 SetAudioBlockSize() | 152
8.20.3.14 SetAudioSampleRate() | 152
8.20.3.15 StartAdc() | 152
8.20.3.16 StartAudio() [1/2] | 152
8.20.3.17 StartAudio() [2/2] | 152
8.20.3.18 StopAdc() | 152
8.20.3.19 StopAudio() | 152
8.20.3.20 UpdateLeds() | 153
8.20.4 Member Data Documentation | 153
8.20.4.1 button1 | 153
8.20.4.2 button2 | 153

xviii

8.20.4.3 buttons | 153
8.20.4.4 encoder | 153
8.20.4.5 knob1 | 153
8.20.4.6 knob2 | 153
8.20.4.7 knobs | 154
8.20.4.8 led1 | 154
8.20.4.9 led2 | 154
8.20.4.10 seed | 154
8.20.5 autotoc_md10 | 154
8.21 daisy::DaisySeed Class Reference | 154
8.21.1 Detailed Description | 155
8.21.2 Member Function Documentation | 155
8.21.2.1 AudioBlockSize() | 156
8.21.2.2 AudioCallbackRate() | 156
8.21.2.3 AudioSampleRate() | 156
8.21.2.4 ChangeAudioCallback() [1/2] | | 156
8.21.2.5 ChangeAudioCallback() [2/2] | | 156
8.21.2.6 Configure() | 156
8.21.2.7 DelayMs() | 156
8.21.2.8 GetPin() | 157
8.21.2.9 Init() | 157
8.21.2.10 Print() | 157
8.21.2.11 PrintLine() | 157
8.21.2.12 SetAudioBlockSize() | 157
8.21.2.13 SetAudioSampleRate() | 158
8.21.2.14 SetLed() | 158
8.21.2.15 SetTestPoint() | 158
8.21.2.16 StartAudio() [1/2] | 158
8.21.2.17 StartAudio() [2/2] | 158
8.21.2.18 StartLog() | 158
8.21.2.19 StopAudio() | 158
8.21.3 Member Data Documentation | 159
8.21.3.1 adc | 159
8.21.3.2 audio_handle | 159
8.21.3.3 qspi_handle | 159
8.21.3.4 sdram_handle | 159
8.21.3.5 usb_handle | 159
8.22 daisy::DaisyVersio Class Reference | 159
8.22.1 Detailed Description | 160
8.22.2 Member Function Documentation | 161
8.22.2.1 AudioBlockSize() | 161
8.22.2.2 AudioCallbackRate() | 161

xix

8.22.2.3 AudioSampleRate() | 161
8.22.2.4 ChangeAudioCallback() [1/2] | | 161
8.22.2.5 ChangeAudioCallback() [2/2] | | 161
8.22.2.6 DelayMs() | 162
8.22.2.7 Gate() | 162
8.22.2.8 GetKnobValue() | 162
8.22.2.9 Init() | 162
8.22.2.10 ProcessAllControls() | 162
8.22.2.11 ProcessAnalogControls() | 162
8.22.2.12 SetAudioBlockSize() | 163
8.22.2.13 SetAudioSampleRate() | 163
8.22.2.14 SetLed() | 163
8.22.2.15 StartAdc() | 163
8.22.2.16 StartAudio() [1/2] | 163
8.22.2.17 StartAudio() [2/2] | 163
8.22.2.18 StopAdc() | 163
8.22.2.19 StopAudio() | 164
8.22.2.20 SwitchPressed() | 164
8.22.2.21 UpdateLeds() | 164
8.23 dsy_gpio Struct Reference | 164
8.23.1 Detailed Description | 164
8.23.2 Member Data Documentation | 164
8.23.2.1 mode | 164
8.23.2.2 pin | 165
8.23.2.3 pull | 165
8.24 dsy_gpio_pin Struct Reference | 165
8.24.1 Detailed Description | 165
8.24.2 Member Data Documentation | 165
8.24.2.1 pin | 165
8.24.2.2 port | 166
8.25 dsy_qspi_handle Struct Reference | 166
8.25.1 Detailed Description | 166
8.25.2 Member Data Documentation | 166
8.25.2.1 device | 166
8.25.2.2 mode | 166
8.25.2.3 pin_config | 167
8.26 DSY_SD_CardInfoTypeDef Struct Reference | 167
8.26.1 Detailed Description | 167
8.26.2 Member Data Documentation | 167
8.26.2.1 BlockNbr | 167
8.26.2.2 BlockSize | 167
8.26.2.3 CardSpeed | 168

xx

8.26.2.4 CardType | 168
8.26.2.5 CardVersion | 168
8.26.2.6 Class | 168
8.26.2.7 LogBlockNbr | 168
8.26.2.8 LogBlockSize | 168
8.26.2.9 RelCardAdd | 168
8.27 dsy_sdram_handle Struct Reference | 169
8.27.1 Detailed Description | 169
8.27.2 Member Data Documentation | 169
8.27.2.1 pin_config | 169
8.27.2.2 state | 169
8.28 daisy::Encoder Class Reference | 169
8.28.1 Detailed Description | 170
8.28.2 Member Function Documentation | 170
8.28.2.1 Debounce() | 170
8.28.2.2 FallingEdge() | 170
8.28.2.3 Increment() | 170
8.28.2.4 Init() | 171
8.28.2.5 Pressed() | 171
8.28.2.6 RisingEdge() | 171
8.28.2.7 TimeHeldMs() | 171
8.29 FontDef Struct Reference | 171
8.29.1 Detailed Description | 172
8.29.2 Member Data Documentation | 172
8.29.2.1 data | 172
8.29.2.2 FontHeight | 172
8.29.2.3 FontWidth | 172
8.30 daisy::GateIn Class Reference | 172
8.30.1 Detailed Description | 173
8.30.2 Constructor & Destructor Documentation | 173
8.30.2.1 GateIn() | 173
8.30.2.2 ∼GateIn() | 173
8.30.3 Member Function Documentation | 173
8.30.3.1 Init() | 173
8.30.3.2 State() | 173
8.30.3.3 Trig() | 174
8.31 daisy::I2CHandle Class Reference | 174
8.31.1 Detailed Description | 175
8.31.2 Member Typedef Documentation | 175
8.31.2.1 CallbackFunctionPtr | 175
8.31.3 Member Enumeration Documentation | 175
8.31.3.1 Result | 175

xxi

8.31.4 Member Function Documentation | 175
8.31.4.1 GetConfig() | 176
8.31.4.2 Init() | 176
8.31.4.3 ReadDataAtAddress() | 176
8.31.4.4 ReceiveBlocking() | 176
8.31.4.5 TransmitBlocking() | 177
8.31.4.6 TransmitDma() | 177
8.31.4.7 WriteDataAtAddress() | 178
8.32 daisy::Led Class Reference | 178
8.32.1 Detailed Description | 178
8.32.2 Member Function Documentation | 179
8.32.2.1 Init() | 179
8.32.2.2 Set() | 179
8.32.2.3 Update() | 179

8.33 daisy::LedDriverPca9685< numDrivers, persistentBufferContents > Class Template Reference . . 180

8.33.1 Detailed Description | 180
8.33.2 Member Typedef Documentation | 180
8.33.2.1 DmaBuffer | 181
8.33.3 Member Function Documentation | 181
8.33.3.1 __attribute__() | 181
8.33.3.2 GetNumLeds() | 181
8.33.3.3 Init() | 181
8.33.3.4 SetAllTo() [1/2] | 182
8.33.3.5 SetAllTo() [2/2] | 182
8.33.3.6 SetAllToRaw() | 182
8.33.3.7 SetLed() [1/2] | | 182
8.33.3.8 SetLed() [2/2] | | 182
8.33.3.9 SetLedRaw() | 183
8.33.3.10 SwapBuffersAndTransmit() | 183
8.34 daisy::Logger< dest > Class Template Reference | 183
8.34.1 Detailed Description | 184
8.35 daisy::Logger< LOGGER_NONE > Class Reference | 184
8.35.1 Detailed Description | 184
8.36 daisy::LoggerImpl< dest > Class Template Reference | 185
8.36.1 Detailed Description | 185
8.36.2 Member Function Documentation | 185
8.36.2.1 Init() | 185
8.36.2.2 Transmit() | 185
8.37 daisy::LoggerImpl< LOGGER_EXTERNAL > Class Reference | 186
8.37.1 Detailed Description | 186
8.37.2 Member Function Documentation | 186
8.37.2.1 Init() | 186

xxii

8.37.2.2 Transmit() | 186
8.37.3 Member Data Documentation | 186
8.37.3.1 usb_handle_ | 187
8.38 daisy::LoggerImpl< LOGGER_INTERNAL > Class Reference | 187
8.38.1 Detailed Description | 187
8.38.2 Member Function Documentation | 187
8.38.2.1 Init() | 187
8.38.2.2 Transmit() | 187
8.38.3 Member Data Documentation | 188
8.38.3.1 usb_handle_ | 188
8.39 daisy::LoggerImpl< LOGGER_SEMIHOST > Class Reference | 188
8.39.1 Detailed Description | 188
8.39.2 Member Function Documentation | 188
8.39.2.1 Init() | 188
8.39.2.2 Transmit() | 189
8.40 daisy::MidiEvent Struct Reference | 189
8.40.1 Detailed Description | 189
8.40.2 Member Function Documentation | 189
8.40.2.1 AsControlChange() | 189
8.40.2.2 AsNoteOn() | 189
8.40.3 Member Data Documentation | 190
8.40.3.1 channel | 190
8.40.3.2 data | 190
8.40.3.3 type | 190
8.41 daisy::MidiHandler Class Reference | 190
8.41.1 Detailed Description | 191
8.41.2 Member Enumeration Documentation | 191
8.41.2.1 MidiInputMode | 191
8.41.2.2 MidiOutputMode | 191
8.41.3 Member Function Documentation | 192
8.41.3.1 HasEvents() | 192
8.41.3.2 Init() | 192
8.41.3.3 Listen() | 192
8.41.3.4 Parse() | 192
8.41.3.5 PopEvent() | 193
8.41.3.6 SendMessage() | 193
8.41.3.7 StartReceive() | 193
8.42 daisy::NoteOnEvent Struct Reference | 193
8.42.1 Detailed Description | 193
8.42.2 Member Data Documentation | 194
8.42.2.1 channel | 194
8.42.2.2 note | 194

xxiii

8.42.2.3 velocity | 194
8.43 daisy::OledDisplay Class Reference | 194
8.43.1 Detailed Description | 195
8.43.2 Member Enumeration Documentation | 195
8.43.2.1 Pins | 195
8.43.3 Member Function Documentation | 195
8.43.3.1 DrawArc() | 195
8.43.3.2 DrawCircle() | 196
8.43.3.3 DrawLine() | 196
8.43.3.4 DrawPixel() | 196
8.43.3.5 DrawRect() | 197
8.43.3.6 Fill() | 197
8.43.3.7 Init() | 197
8.43.3.8 SetCursor() | 198
8.43.3.9 Update() | 198
8.43.3.10 WriteChar() | 198
8.43.3.11 WriteString() | 199
8.44 daisy::Parameter Class Reference | 199
8.44.1 Detailed Description | 199
8.44.2 Member Enumeration Documentation | 200
8.44.2.1 Curve | 200
8.44.3 Constructor & Destructor Documentation | 201
8.44.3.1 Parameter() | 201
8.44.3.2 ∼Parameter() | 201
8.44.4 Member Function Documentation | 201
8.44.4.1 Init() | 201
8.44.4.2 Process() | 202
8.44.4.3 Value() | 202
8.45 daisy::Pcm3060 Class Reference | 202
8.45.1 Member Function Documentation | 202
8.45.1.1 Init() | 202
8.46 daisy::RgbLed Class Reference | 203
8.46.1 Detailed Description | 203
8.46.2 Member Function Documentation | 203
8.46.2.1 Init() | 203
8.46.2.2 Set() | 204
8.46.2.3 SetColor() | 204
8.46.2.4 Update() | 204
8.47 daisy::RingBuffer< T, size > Class Template Reference | 204
8.47.1 Detailed Description | 205
8.47.2 Member Function Documentation | 205
8.47.2.1 Advance() | 205

xxiv

8.47.2.2 capacity() | 205
8.47.2.3 Flush() | 206
8.47.2.4 GetMutableBuffer() | 206
8.47.2.5 ImmediateRead() [1/2] | 206
8.47.2.6 ImmediateRead() [2/2] | 206
8.47.2.7 Init() | 206
8.47.2.8 isEmpty() | 207
8.47.2.9 Overwrite() [1/2] | 207
8.47.2.10 Overwrite() [2/2] | 207
8.47.2.11 Read() | 207
8.47.2.12 readable() | 208
8.47.2.13 Swallow() | 208
8.47.2.14 writable() | 208
8.47.2.15 Write() | 208
8.48 daisy::RingBuffer< T, 0 > Class Template Reference | 209
8.48.1 Detailed Description | 209
8.48.2 Member Function Documentation | 209
8.48.2.1 capacity() | 209
8.48.2.2 Flush() | 210
8.48.2.3 ImmediateRead() [1/2] | 210
8.48.2.4 ImmediateRead() [2/2] | 210
8.48.2.5 Init() | 210
8.48.2.6 Overwrite() [1/2] | 210
8.48.2.7 Overwrite() [2/2] | 211
8.48.2.8 Read() | 211
8.48.2.9 readable() | 211
8.48.2.10 writable() | 211
8.48.2.11 Write() | 212
8.49 daisy::SaiHandle Class Reference | 212
8.49.1 Detailed Description | 213
8.49.2 Member Typedef Documentation | 213
8.49.2.1 CallbackFunctionPtr | 213
8.49.3 Member Enumeration Documentation | 213
8.49.3.1 Result | 213
8.49.4 Member Function Documentation | 213
8.49.4.1 GetBlockRate() | 214
8.49.4.2 GetBlockSize() | 214
8.49.4.3 GetConfig() | 214
8.49.4.4 GetOffset() | 214
8.49.4.5 GetSampleRate() | 214
8.49.4.6 Init() | 214
8.49.4.7 StartDma() | 214

xxv

8.49.4.8 StopDma() | 215
8.50 daisy::ScopedIrqBlocker Class Reference | 215
8.50.1 Detailed Description | 215
8.51 daisy::SdmmcHandler Class Reference | 215
8.51.1 Detailed Description | 215
8.51.2 Member Function Documentation | 215
8.51.2.1 Init() | 216
8.52 daisy::SdmmcHandlerInit Struct Reference | 216
8.52.1 Detailed Description | 216
8.52.2 Member Data Documentation | 216
8.52.2.1 bitdepth | 216
8.52.2.2 speed | 216
8.53 daisy::ShiftRegister4021< num_daisychained, num_parallel > Class Template Reference | 217
8.53.1 Member Function Documentation | 217
8.53.1.1 Init() | 217
8.53.1.2 State() | 217
8.53.1.3 Update() | 217
8.54 ShiftRegister595 Class Reference | 218
8.54.1 Detailed Description | 218
8.54.2 Member Enumeration Documentation | 218
8.54.2.1 Pins | 218
8.54.3 Member Function Documentation | 219
8.54.3.1 Init() | 219
8.54.3.2 Set() | 219
8.54.3.3 Write() | 219
8.55 daisy::SpiHandle Class Reference | 219
8.55.1 Detailed Description | 220
8.55.2 Member Function Documentation | 220
8.55.2.1 BlockingTransmit() | 220
8.55.2.2 Init() | 220
8.56 daisy::Switch Class Reference | 220
8.56.1 Detailed Description | 221
8.56.2 Member Enumeration Documentation | 221
8.56.2.1 Polarity | 221
8.56.2.2 Pull | 221
8.56.2.3 Type | 222
8.56.3 Member Function Documentation | 222
8.56.3.1 Debounce() | 222
8.56.3.2 FallingEdge() | 222
8.56.3.3 Init() [1/2] | 222
8.56.3.4 Init() [2/2] | 223
8.56.3.5 Pressed() | 223

xxvi

8.56.3.6 RawState() | 223
8.56.3.7 RisingEdge() | 224
8.56.3.8 TimeHeldMs() | 224
8.57 daisy::Switch3 Class Reference | 224
8.58 daisy::System Class Reference | 224
8.58.1 Member Function Documentation | 225
8.58.1.1 Delay() | 225
8.58.1.2 DelayTicks() | 225
8.58.1.3 DelayUs() | 226
8.58.1.4 GetConfig() | 226
8.58.1.5 GetHClkFreq() | 226
8.58.1.6 GetNow() | 226
8.58.1.7 GetPClk1Freq() | 226
8.58.1.8 GetPClk2Freq() | 227
8.58.1.9 GetSysClkFreq() | 227
8.58.1.10 GetTick() | 227
8.58.1.11 GetUs() | 227
8.58.1.12 Init() [1/2] | 227
8.58.1.13 Init() [2/2] | 227
8.58.1.14 JumpToQspi() | 228
8.59 daisy::TimerHandle Class Reference | 228
8.59.1 Detailed Description | 229
8.59.2 Member Enumeration Documentation | 229
8.59.2.1 Result | 229
8.59.3 Member Function Documentation | 229
8.59.3.1 DelayMs() | 230
8.59.3.2 DelayTick() | 230
8.59.3.3 DelayUs() | 230
8.59.3.4 GetConfig() | 230
8.59.3.5 GetFreq() | 230
8.59.3.6 GetMs() | 230
8.59.3.7 GetTick() | 230
8.59.3.8 GetUs() | 231
8.59.3.9 Init() | 231
8.59.3.10 SetPeriod() | 231
8.59.3.11 SetPrescaler() | 231
8.59.3.12 Start() | 231
8.59.3.13 Stop() | 231
8.60 daisy::UartHandler Class Reference | 232
8.60.1 Detailed Description | 232
8.60.2 Member Function Documentation | 232
8.60.2.1 CheckError() | 232

xxvii

8.60.2.2 FlushRx() | 233
8.60.2.3 Init() | 233
8.60.2.4 PollReceive() | 233
8.60.2.5 PollTx() | 233
8.60.2.6 PopRx() | 234
8.60.2.7 Readable() | 234
8.60.2.8 RxActive() | 234
8.60.2.9 StartRx() | 235
8.61 UsbHandle Class Reference | 235
8.61.1 Detailed Description | 236
8.61.2 Member Typedef Documentation | 236
8.61.2.1 ReceiveCallback [1/2] | 236
8.61.2.2 ReceiveCallback [2/2] | 236
8.61.3 Member Enumeration Documentation | 236
8.61.3.1 Result [1/2] | 236
8.61.3.2 Result [2/2] | 236
8.61.3.3 UsbPeriph [1/2] | | 236
8.61.3.4 UsbPeriph [2/2] | | 237
8.61.4 Member Function Documentation | 237
8.61.4.1 Init() [1/2] | 237
8.61.4.2 Init() [2/2] | 237
8.61.4.3 SetReceiveCallback() [1/2] | | 238
8.61.4.4 SetReceiveCallback() [2/2] | | 238
8.61.4.5 TransmitExternal() [1/2] | | 238
8.61.4.6 TransmitExternal() [2/2] | | 239
8.61.4.7 TransmitInternal() [1/2] | 239
8.61.4.8 TransmitInternal() [2/2] | 239
8.62 WAV_FormatTypeDef Struct Reference | 240
8.62.1 Detailed Description | 240
8.62.2 Member Data Documentation | 240
8.62.2.1 AudioFormat | 240
8.62.2.2 BitPerSample | 240
8.62.2.3 BlockAlign | 241
8.62.2.4 ByteRate | 241
8.62.2.5 ChunkId | 241
8.62.2.6 FileFormat | 241
8.62.2.7 FileSize | 241
8.62.2.8 NbrChannels | 241
8.62.2.9 SampleRate | 241
8.62.2.10 SubChunk1ID | 241
8.62.2.11 SubChunk1Size | 242
8.62.2.12 SubChunk2ID | 242

xxviii

8.62.2.13 SubCHunk2Size | 242
8.63 daisy::WavFileInfo Struct Reference | 242
8.63.1 Detailed Description | 242
8.63.2 Member Data Documentation | 242
8.63.2.1 name | 242
8.63.2.2 raw_data | 243
8.64 daisy::WavPlayer Class Reference | 243
8.64.1 Detailed Description | 243
8.64.2 Member Function Documentation | 243
8.64.2.1 Close() | 243
8.64.2.2 GetCurrentFile() | 244
8.64.2.3 GetLooping() | 244
8.64.2.4 GetNumberFiles() | 244
8.64.2.5 Init() | 244
8.64.2.6 Open() | 244
8.64.2.7 Prepare() | 245
8.64.2.8 Restart() | 245
8.64.2.9 SetLooping() | 245
8.64.2.10 Stream() | 245
8.65 daisy::Wm8731 Class Reference | 245
8.65.1 Detailed Description | 246
8.65.2 Member Enumeration Documentation | 246
8.65.2.1 Result | 246
8.65.3 Member Function Documentation | 246
8.65.3.1 Init() | 246
9 File Documentation | 247
9.1 src/sys/ffconf.h File Reference | 247
9.1.1 Detailed Description | 248
9.1.2 Macro Definition Documentation | 248
9.1.2.1 _CODE_PAGE | 248
9.1.2.2 _FFCONF | 248
9.1.2.3 _FS_EXFAT | 249
9.1.2.4 _FS_LOCK | 249
9.1.2.5 _FS_MINIMIZE | 249
9.1.2.6 _FS_NOFSINFO | 249
9.1.2.7 _FS_NORTC | 249
9.1.2.8 _FS_READONLY | 249
9.1.2.9 _FS_REENTRANT | 250
9.1.2.10 _FS_RPATH | 250
9.1.2.11 _FS_TIMEOUT | 250
9.1.2.12 _FS_TINY | 250

xxix

9.1.2.13 _LFN_UNICODE | 250
9.1.2.14 _MAX_LFN | 250
9.1.2.15 _MAX_SS | 251
9.1.2.16 _MIN_SS | 251
9.1.2.17 _MULTI_PARTITION | 251
9.1.2.18 _NORTC_MDAY | 251
9.1.2.19 _NORTC_MON | 251
9.1.2.20 _NORTC_YEAR | 251
9.1.2.21 _STR_VOLUME_ID | 252
9.1.2.22 _STRF_ENCODE | 252
9.1.2.23 _SYNC_t | 252
9.1.2.24 _USE_CHMOD | 252
9.1.2.25 _USE_EXPAND | 252
9.1.2.26 _USE_FASTSEEK | 252
9.1.2.27 _USE_FIND | 253
9.1.2.28 _USE_FORWARD | 253
9.1.2.29 _USE_LABEL | 253
9.1.2.30 _USE_LFN | 253
9.1.2.31 _USE_MKFS | 253
9.1.2.32 _USE_STRFUNC | 253
9.1.2.33 _USE_TRIM | 253
9.1.2.34 _VOLUME_STRS | 254
9.1.2.35 _VOLUMES | 254
9.1.2.36 ff_free | 254
9.1.2.37 ff_malloc | 254
9.2 src/usbd/usbd_cdc_if.h File Reference | 254
9.2.1 Detailed Description | 255
9.3 src/usbd/usbd_conf.h File Reference | 255
9.3.1 Detailed Description | 256
9.4 src/usbd/usbd_desc.h File Reference | 256
9.4.1 Detailed Description | 256
Index | 257

# Chapter 1

# Main Page

## libDaisy

Hardware Abstraction Library for the Daisy Audio Platform

libDaisy provides easy access to things such as Audio, Controls, GPIO, MIDI, USB communication, and more.

### 1.0.1 Features

- Configurable Audio Callback
- MIDI Drivers
- USB Communication (Audio, MIDI, Serial, etc.)
- Peripheral Device Drivers (SPI, I2S, I2C, etc.)

### 1.0.2 Code Example

{c++}
int main(void)
{
// Init
float samplerate;
hw.Init();
samplerate = hw.AudioSampleRate(); midi.Init(MidiHandler::INPUT_MODE_UART1, MidiHandler::OUTPUT_MODE_NONE); midi.StartReceive();
hw.StartAdc();
hw.StartAudio(AudioCallback);

for(;;)
{
midi.Listen();
// Handle MIDI Events
while (midi.HasEvents())
{
HandleMidiMessage(midi.PopEvent()); }
}
}

### 2 Main Page

### 1.0.3 Getting Started

- Check out our Getting Started Wiki Page (https://github.com/electro-smith/DaisyWiki/wiki)
- Browse the reference documentation on the web (https://electro-smith.github.io/libDaisy)
- Make some sound!

### 1.0.4 Project Overview

Prefixes and their meanings:

- sys - System level configuration (clocks, dma, etc.)
- per - Peripheral level, internal to MCU (i2c, spi, etc.)
- dev - External device support (external flash chips, DACs, codecs, etc.)
- hid - User level interface elements (encoders, switches, audio, etc.)
- util - library level elements used within the library (not included via daisy.h)
- daisy - core API files (specific boards and platforms have extended user APIs that configure libDaisy more below).

Also included is a core/ folder containing:

- a generic Makefile that can be included in a project Makefile to simplify getting started
- a linker script for defining the sections of memory used by the firmware
- core files for starting the hardware (system_stm32h7xx.c, startup_stm32h750xx.s, etc.)

### 1.0.4.1 daisy.h

The base-level include file. This is all you need to include to create your own custom hardware that uses libDaisy.

daisy_seed.h is an example of a board level file that utilizes libDaisy to define some hardware, and provide flexible access.

### 1.0.4.2 daisy_seed.h

The SOM-level include file. This can be used with any boards that use the Daisy Seed hardware.

Additional configuration files, with more specific hardware access are provided below for supported hardware platforms.
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

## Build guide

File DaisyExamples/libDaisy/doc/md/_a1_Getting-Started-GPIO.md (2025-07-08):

# Getting Started - GPIO

GPIO stands for General Purpose Input/Output. These are common to microcontrollers of all sizes, and are one of the many ways to work with external components.

GPIO are used as the basis for several interface components including switches, LEDs, encoders, etc.

The Daisy exposes several GPIO on its pinout. Most of these pins can do much more than just be a digital input or output, but we'll keep it simple for now.

Below, we'll discuss the code, hardware, and provide a few examples of how to use the GPIO within the Daisy ecosystem.

## The CPP Objects Used

We'll be using the `DaisySeed`, `Pin`, and `GPIO` objects in the following sections.

If you're using a different Daisy SOM (i.e. DaisyPatchSM, etc.) this still applies, but some of the pin names will be different.

The `DaisySeed` object is a class that manages all of the hardware on the Seed board. All we need to do with it for now is initialize it.

The `Pin` class is used to describe a specific physical pin on the hardware. These objects are used to initialize GPIO, but are also used in the configuration of more complex peripherals and devices (i.e. ADCs, Shift Registers, etc.).

The `GPIO` class is used for the basic reading/writing of a digital signal.

When we talk about "digital" signals, we mean a signal that has only two states, HIGH and LOW.

## The Hardware Connections

For the examples below we'll be using a few components. These can be replaced with a number of similar alternatives.

* [Mini Pushbutton](https://www.electro-smith.com/parts/pushbuttons)
* [3mm LED](https://www.electro-smith.com/parts/3mm-leds)
* Resistor(s) any low value (1-10K should work okay in the examples discussed below)

## GPIO Input

One of the simplest uses of a GPIO is to read the state of a button.

For this example we'll use a simple [mini pushbutton](https://www.electro-smith.com/parts/pushbuttons) to read the state of a button.

The easiest way to wire up a switch like this is to connect one set of legs (pins 1 and 2) to the GPIO input, and connect the other two legs (pins 3 and 4) to GND.

A very short example of a program to do this looks like:

```cpp
#include "daisy_seed.h"

using namespace daisy;
using namespace daisy::seed;

DaisySeed hw;

int main(void) {
  // Initialize the Daisy Seed
  hw.Init();

  // Create a GPIO object
  GPIO my_button;

  // Initialize the GPIO object
  my_button.Init(D0, GPIO::Mode::INPUT, GPIO::Pull::PULLUP);

  while(1) {
    // And let's store the state of the button in a variable called "button_state"
    bool button_state = my_button.Read();
  }
}
```

If you haven't followed the guides on [setting up your development environment](https://github.com/electro-smith/DaisyWiki/wiki/1.-Setting-Up-Your-Development-Environment) and [creating a new project](https://github.com/electro-smith/DaisyWiki/wiki/How-To:-Create-a-New-Project) now would be a perfect time to catch up, and create a new project to work with the GPIO.

Compiling this example, you might get a warning, for an "unused variable button_state", but we'll get to using that shortly!

## Breaking Down the Init function

Let's look at that GPIO init function in a bit more detail, shall we? First, we'll breakdown the full Initialization definition:

```cpp
void Init(Pin p, Mode m=Mode::INPUT, Pull pu=Pull::NOPULL, Speed sp=Speed::LOW);
```

The first thing you may be wondering, if you're not used to C++ is the `::` characters all over the place. These are used for the configuration settings so that the compiler will only allow you to use the correct inputs instead of being able to pass the wrong thing to the input, or even just mis-order the arguments, and end up scratching your head for hours wondering what's not working.

These `::` are also used for namespaces, which we handle in the above example with the `using namespace` lines. Without that we'd have to use `daisy::GPIO` instead of `GPIO`, `daisy::seed::D0` instead of `D0`, etc.

### Pin Argument

So, the first argument: `Pin p` describes the daisy pin to assign to our GPIO, this ties our new GPIO object to some of the actual hardware on the Daisy Seed. By using `D0` (or more explicitly, `daisy::seed::D0`), we're saying we want to use that pin for our GPIO.

### Mode Argument

The second argument: `Mode m` can be any of the following:

* `Mode::INPUT` - configures the pin as an input
* `Mode::OUTPUT` - configures the pin as an output (in push pull configuration)
* `Mode::OUTPUT_OD` - also an output, but the transistor connection to pull the signal to GND is not connected, this is less commonly used.
* `Mode::ANALOG` - configures the GPIO for connection to the ADC or DAC peripherals within the micro controller.

If you only supply the `Pin` argument, the GPIO will default to `Mode::INPUT` configuration.

### Pull Argument

The third argument: `Pull pu` is used to select whether the GPIO will use an internal (around 30-50k) resistor as a pull up or pull down resistor.

A pull up resistor will keep the GPIO idling at 3V3 unless something pulls it down, while a pull down resistor will keep a GPIO idling at 0V unless something pulls it up.

The options for this argument are:

* `Pull::NOPULL` - no pull up or pull down resistor is connected.
* `Pull::PULLUP` - pull up resistor is connected to the GPIO line.
* `Pull::PULLDOWN` - pull down resistor is connected to the GPIO line.

This argument will default to `Pull::NOPULL` if you only supply a `Pin` and a `Mode`

So when, and why do we need pull up or pull down resistors anyway?

Well, if we connect a wire to one of Daisy's GPIO pins, and there are no internal or external resistors attached, there's no definite way to know what voltage the wire is sitting at.

Now, if we connect the wire to a button, as we did in the above example, and connect the other side of the button to 3V3 then we _do_ know the voltage at the pin when the button pressed.
However, when the button is not pressed, we still have an "undefined" state, as we can't guarantee that the pin will be at 0V when the button isn't pressed.

To solve this unknown state issue, we can add a resistor to the pin that "pulls" the signal to GND when the button isn't actively pulling the voltage up to 3V3 (while pressed).

Instead of adding an external resistor to do this, we can use the built-in pull-down feature to accomplish the same thing.

In the example above, we did the same thing except we used the pull up resistor, and wired the button to GND. This usually just requires less wires, but the function is the same.

### Speed Argument

The final argument, `Speed sp` is a special configuration for Output modes that control the slew rate, or the speed at which it can switch from 0V to 3V. We won't go super in depth on that in this, but you'll always want it to be the lowest speed possible for a given application to reduce the amount of electrical noise emitted.

## GPIO Output

So you've got your button reading code, your board wired up, and you're probably thinking, "Great! So how can I tell if I've done this correctly!?".

Well, let's set up a second pin as an output to light up an LED when we push our button. That way we can tell everything we've done so far is working.

Setting up the GPIO output isn't much more work.

On your hardware, you'll want to take the second pin (right above the square D0 pin), and connect a resistor, and an LED in series. You'll want the **cathode** of the LED connected to GND, with the **anode** connected to the resistor, [as described here](https://makecode.adafruit.com/learnsystem/pins-tutorial/devices/led-connections).

Once you've got that set up we can add a few lines to our example.

In the Initialization section:

```cpp
GPIO my_led;

my_led.Init(D1, GPIO::Mode::OUTPUT);
```

And then we can use the `button_state` variable we were reading from the button earlier to control the state of the LED:

```cpp
while(1)
{
  // And let's store the state of the button in a variable called "button_state"
  bool button_state = my_button.Read();
  my_led.Write(button_state);
}
```

And that's it! Easy, right?

So you get that all set up, and you might be thinking, "Well, this is great, but the LED turns off when I push the button instead of turning it on, what the heck?"

That's because of the way we set up the button in the first step. Because we used the internal pull up resistor, to avoid adding extra parts to our board, the GPIO is returning true while the button is not pressed instead of what we might expect. Well, C++ has a very easy way of flipping that over.

```cpp
bool button_state = my_button.Read(); // state is false while button is pressed
bool button_pressed = !button_state; // "!" is a "not" operator, which will flip a bool var.
```

So all together, our short little light switch program will look something like:

```cpp
#include "daisy_seed.h"

using namespace daisy;
using namespace daisy::seed;

DaisySeed hw;

int main(void) {
  // Initialize the Daisy Seed
  hw.Init();

  // Create our GPIO object
  GPIO my_button;
  GPIO my_led;

  // Initialize the GPIO object for our button */
  my_button.Init(D0, GPIO::Mode::INPUT, GPIO::Pull::PULLUP);

  // Initialize the GPIO object for our LED
  my_led.Init(D1, GPIO::Mode::OUTPUT);

  while(1) {
    // And let's store the state of the button in a variable called "button_state"
    bool button_state = my_button.Read();

    // And we want to light up the LED while we're pressing the button 
    // so let's use the "!" to flip over the button_state
    my_led.Write(!button_state);
  }
}
```

## Further Reading

Topics coming soon:

* Working with ADCs
* Serial Printing over USB
* Using the Switch and LED classes instead of GPIO, and Why?

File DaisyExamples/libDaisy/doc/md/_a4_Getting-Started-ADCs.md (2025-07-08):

# Getting Started - ADCs

ADC stands for Analog to Digital Converter. These are used to read in a variable signal. These variable signals can be anything from a potentiometer, photoresistor, external control voltage, etc.

On the Daisy, the ADC inputs expect a signal in the range of 0V to 3.3V, unless otherwise stated (e.g. The CV inputs on the Daisy Patch SM are set up to expect -5V to 5V, a common range for Modular Synthesizers).

In this tutorial we'll be using the Daisy Seed hardware, and we will go through the process of connecting a few inputs to one of the many available ADC pins.

## The CPP Objects Used

We'll be using the `DaisySeed`, it's internal `AdcHandle`, `Pin`, and `AdcChannelConfig` objects in the following sections.

If you're using a different Daisy SOM (i.e. DaisyPatchSM, etc.) this is handled within the board support files for all available inputs.

The `DaisySeed` object is a class that manages all of the hardware on the Seed board. All we need to do with it for now is initialize it.

The `AdcHandle` is a handler for the microcontroller's embedded Analog to Digital Converter. It is up to 16-bits, and can handle multiplexing several inputs.

The `Pin` class is used to describe a specific physical pin on the hardware. These objects are used to initialize GPIO, but are also used in the configuration of more complex peripherals and devices (i.e. ADCs, Shift Registers, etc.).

The `AdcChannelConfig` object is used to define each of the connections to the ADC, and the order in which the inputs will be read.

## The Hardware Connections

For this tutorial all we'll need is:

* a few potentiometers like these [9mm Plastic Shaft Pot with Pointers](https://www.electro-smith.com/parts/trimmer), but any potentiometer should do the trick.

To wire up the pot we'll want to connect pin 1 of the pot to GND, and pin 3 of the pot to 3v3_A, and the middle leg (pin 2) will now output a variable voltage from 0V to 3.3V; perfect for our expected input range.

When working with the Daisy and external hardware, **always connect the DGND and AGND pins outside of the Daisy**

## ADC Channel Config

libDaisy uses the STM32 ADC1 peripheral, which is a single ADC with several multiplexed inputs.

This makes setting it up a little different than something like a GPIO, because the ADC will scan through all of the configured inputs in the background without taking up CPU time.

To define what connections are made we will use the `AdcChannelConfig` class.

The AdcChannelConfig has two possible initialization functions:

* `InitSingle` - For configuring a single input to a single pin on the Daisy
* `InitMux` - For configuring several inputs from an external multiplexer (like CD4051) to a single pin on the Daisy

Below we'll only be using the `InitSingle` function, but stay tuned for a guide for connecting a ton of controls using external multiplexer in the future.

The `InitSingle` function takes an old version of the Daisy's `Pin` object, but it is compatible with the new pins. So anywhere you see, `dsy_gpio_pin` you can use the `Pin` object instead.

This structure, and the number of channels can then be passed to the `AdcHandle` to set everything up.

## A Single Input

Alright, enough talk. Let's plug some stuff in, and write some code!

We can take a look at all of the available ADC pins by looking at the [Pinout Diagram](https://github.com/electro-smith/DaisyWiki/wiki/2.-Daisy-Seed-Pinout). The ADC Pins are all labeled and colored in yellow.

Let's get started with pin `A0` (also known as `D15`), and wire up our potentiometer.

See the wiring mentioned above in the [Hardware Connections](#The-Hardware-Connections) for how to connect all of the legs of the pot, and take the wiper (middle leg), and connect that to the `A0` pin on the Daisy.

And here's a short program that will setup, and read from an ADC:

```cpp
#include "daisy_seed.h"

using namespace daisy;
using namespace daisy::seed;

// Create out Daisy Seed Hardware object
DaisySeed hw;

int main(void) {
  // Initialize the Daisy Seed hardware
  hw.Init();

  // Start logging for printing over serial
  hw.StartLog();

  // Create an ADC Channel Config object
  AdcChannelConfig adc_config;

  // Set up the ADC config with a connection to pin A0
  adc_config.InitSingle(A0);

  // Initialize the ADC peripheral with that configuration
  hw.adc.Init(&adc_config, 1);

  // Start the ADC
  hw.adc.Start();

  while(1) {
    // Read the first ADC that's configured. In our case, this is the only input.
    int value = hw.adc.Get(0);

    // In order to know that everything's working let's print that to a serial console:
    hw.PrintLine("ADC Value: %d", value);

    // Wait half a second (500 milliseconds)
    System::Delay(500);
  }
}
```

To find out more about the serial printing, and what software to use, see our [tutorial on working with Serial Printing](_a2_Getting-Started-Serial-Printing.md).

With the above program, you should see a number printing that moves from 0 to 65536 as you rotate the pot. Now, pots, and electronics aren't perfect.
So there's a chance that this may not reach those extremes, or it might reach them slightly before the edges of the potentiometer's range.
This will largely depend on the potentiometer you're using.

Now that's great and all, but it would be nicer to work with a number that is scaled between 0 and 1 instead (since that's more useful for doing other things).

We can actually get the value in that range instead by changing the line where we were doing:

```cpp
int value = hw.adc.Get(0); // value will be 0-65536
```

to this Instead:

```cpp
float value = hw.adc.GetFloat(0); // value will be 0.0 to 1.0
```

floating point numbers have a few peculiarities because of the hardware and memory requirements of an embedded project, but you can keep the serial printing by adding the following to the project Makefile:

```make
LDFLAGS += -u _printf_float
```

This isn't included by default because it increases the flash size by several kilobytes, and there are other ways to print floating point numbers (more info on this in the [serial printing tutorial](tutorial)).

## Multiple Inputs

Most things get better when you add more of whatever it is. The same goes for controls!

Now we've set up a single pot. So let's look at what it would look like to hook up two (or more).

Nearly everything will stay the same except instead of using a single `AdcChannelConfig`, we'll want to create one for each control we want to use. C and C++ have a mechanism for dealing with this known as an array. If you're not familiar, it is basically just an ordered list.

So for setting up two pots we'll change the initialization code to look a little more like:

```cpp
// Create an array of two AdcChannelConfig objects
const int num_adc_channels = 2;
AdcChannelConfig my_adc_config[num_adc_channels];
// Initialize the first one connected to A0
my_adc_config[0].InitSingle(A0);
// Initialize the second one connected to A4
my_adc_config[1].InitSingle(A4);
```

And finally when we go to initialize the ADC itself, we can now omit the `&` that we had to use before because it's an array of objects, and we want to make sure to update the total count that we passed in before:

```cpp
hw.adc.Init(my_adc_config, num_adc_channels);
```

Now you can read from either input. If you want to read the pot connected to A0 you would use `hw.adc.Get(0)`, or `hw.adc.GetFloat(0)`, and if you want to read from the pot connected to A4, you would use `hw.adc.Get(1)`, or `hw.adc.GetFloat(1)`.

You'll notice that you access them by the order in which you initialized them, not by the number associated with the Pin.

## Order To Chaos - Naming ADC Channels

Once you have a lot of ADC channels, it can be difficult to remember which channel corresponds to which control. To solve this, you can use `enum`s to assign names to channels like this:

```cpp
enum AdcChannel {
   pitchKnob = 0,
   pitchCv,
   gainKnob,
   gainCv,
   NUM_ADC_CHANNELS
}
```

Here, the first value is assigned to `0`and the others increment automatically. Interestingly, this logic can be used to automatically get the total number of channels you use, by adding one last value `NUM_ADC_CHANNELS`. Of course you could also specify the individual values by hand, just add `myKnob = 3,`.

Now you can make your code much easier to read - and maintain, should you decide to change the hardware connections later:

```cpp
AdcChannelConfig my_adc_config[NUM_ADC_CHANNELS];
// ...
my_adc_config[pitchCv].InitSingle(A0);
// ...
hw.adc.Init(my_adc_config, NUM_ADC_CHANNELS);
// ...
const float pitchCvValue = hw.adc.GetFloat(pitchCv);
```

## Using Different Kinds of Inputs

OK. So now we know what to do with one, or a few inputs that already conform to the expected input range.

In a future guide we'll look at using active and passive circuits to condition a signal to the best range for sending to the Daisy.

## Further Reading

Topics coming soon:

* Printing with USB
* HID classes (Switch, Led, AnalogControl) and why we use them

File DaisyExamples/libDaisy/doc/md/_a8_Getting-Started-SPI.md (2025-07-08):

# SPI

SPI stands for Serial Peripheral Interface, and is a way for devices to talk to one another.
The protocol is used with one device as the main device or the leader.
All other devices are followers.

There are four pins generally used:
- MOSI: Main Out Serial In
- MISO: Main In Serial Out
- SCLK: Serial Clock
- NSS: Serial Select (Chip Select)

## How to Use SPI

First create your SpiHandle object and a Config struct to configure it.
Set any configurations you want to change in the config object, then initialize the spi peripheral with it.

A typical Daisy Seed configuration might look like this

```cpp
// SpiHandle object and Spi Configuration object
SpiHandle spi_handle;
SpiHandle::Config spi_conf;

// Set some configurations
spi_conf.periph = SpiHandle::Peripheral::SPI_1;
spi_conf.mode = SpiHandle::Mode::MASTER;
spi_conf.direction = SpiHandle::Direction::TWO_LINES;
spi_conf.nss = SpiHandle::NSS::NSS_HARD_OUTPUT;
spi_conf.pin_config.sclk = Pin(PORTG, 11);
spi_conf.pin_config.miso = Pin(PORTB, 4);
spi_conf.pin_config.mosi = Pin(PORTB, 5);
spi_conf.pin_config.nss = Pin(PORTG, 10);

// Initialize the handle using our configuration
spi_handle.Init(spi_conf);
```

### Configuration

The default configuration sets the common defaults for SPI peripherals. However some peripherals may require changing these. Some other configurations you'll have to set every time you use SPI.

`spi_conf.peripheral`
The peripheral to be used. Must be specified by the user. For example `SpiHandle::Config::Peripheral::SPI_2`.
The Daisy has 6 different SPI peripherals available, each of which uses different pins. Refer to the pinout diagram for more details.

`spi_conf.mode`
Master or slave. The main device is in charge of the bus (sets the clock, and NSS), the other devices follow along. Most of the time the Daisy will be in charge of the bus.
- `SpiHandle::Config::Mode::MASTER`. The Daisy runs the bus.
- `SpiHandle::Config::Mode::SLAVE`. The Daisy follows another device.

`spi_conf.pin_config`
The pins to be used by this SPI peripheral. These will have to match the peripheral you choose. Must be specified by the user.

- `spi_conf.pin_config.miso`: Main In Serial Out: The main device reads from this pin, and the others write to it.
- `spi_conf.pin_config.mosi`: Main Out Serial In: The main device writes to this pin, and the others read from it.
- `spi_conf.pin_config.sclk`: Serial Clock. The main device outputs a clock signal on this pin.
- `spi_conf.pin_config.nss`: Serial Select. The main device uses this to indicate data is being sent. Usually active low.

If you're not using a pin (e.g. software NSS, or simplex communication) you can set it to `Pin()`.

`spi_conf.direction`
Which direction data will travel. Must be specified by the user.

- `SpiHandle::Config::Direction::TWO_LINES`. Data goes both ways. Each line only goes one direction. i.e. MOSI -> MISO and MISO <- MOSI. This is full duplex. 
- `SpiHandle::Config::Direction::TWO_LINES_TX_ONLY`. The Daisy will only send data. If Daisy's the main device: MOSI->. If the Daisy's a follower MISO->. This is simplex TX.
- `SpiHandle::Config::Direction::TWO_LINES_RX_ONLY`. The Daisy will only read data. If Daisy;s the main device MISO<-. If Daisy's a follower MOSI<-. This is simplex RX.
- `SpiHandle::Config::Direction::ONE_LINE`. Data goes both ways over one line. i.e. MOSI <-> MISO. This is half duplex.

`spi_conf.data_size`
How many bits in each transmission. Defaults to 8.
Must be in the range [4, 32] inclusive.

`spi_conf.clock_polarity`
Is the clock active low or high? 
(Determines if the "first" and "second" edges are rising or falling.)

- `SpiHandle::Config::ClockPolarity::HIGH`. The clock is active high.
- `SpiHandle::Config::ClockPolarity::LOW`. The clock is active low.

Defaults to `SpiHandle::Config::ClockPolarity::LOW`.

`spi_conf.clock_phase`
When is the data ready to be read?
The "first edge" is when we transition __to__ the clock polarity.
The "second edge" is when we transition __away from__ the clock polarity.

So if the polarity is low, the first edge is when the clock goes low.
Again, if the polarity is low, the second edge is when the clock goes high.

- `SpiHandle::Config::ClockPhase::ONE_EDGE` Data is read on the first edge.
- `SpiHandle::Config::ClockPhase::TWO_EDGE`. Data is read on the second edge.

Defaults to `SpiHandle::Config::ClockPhase::ONE_EDGE`.

`spi_conf.nss`
Serial select mode. Must be set by the user.

- `SpiHandle::Config::NSS::SOFT`. Serial select is handled in software. You can ignore the NSS pin.
- `SpiHandle::Config::NSS::HARD_INPUT`. The NSS pin is in use, and the Daisy is a follower.
- `SpiHandle::Config::NSS::HARD_OUTPUT`. The NSS pin is in use, and the Daisy is a leader.

`spi_conf.baud_prescaler`
Division of the default clock rate. 
The clock rate is always 25MHz. 
So with a prescaler of 4 for example, the final clock rate is 25MHz / 4 = 6.25MHz.

Defaults to `SpiHandle::Config::BaudPrescaler::PS_8`

## Blocking Transmit and Receive

Send / receive data in a blocking fashion. The code waits while the transmissions are taking place.

```cpp
// send 4 bytes
uint8_t buffer[4] = {0, 1, 2, 3};
spi_handle.BlockingTransmit(buffer, 4);
```

```cpp
// receive 4 bytes
uint8_t buffer[4];
spi_handle.BlockingReceive(buffer, 4);
```

```cpp
// send and receive 4 bytes
uint8_t tx_buffer[4] = {0, 1, 2, 3};
uint8_t rx_buffer[4];
spi_handle.BlockingTransmitAndReceive(tx_buffer, rx_buffer, 4);
```

## DMA Transmit and Receive

Send / receive data using DMA (Direct Memory Access). 
This allows the hardware to handle the transmission in the background while the code is doing other things.
i.e. it is non blocking.

You can also pass along a callback to be called when the transfer starts, another for when the transfer is over, and a pointer to some data to send those callbacks.

**Note:** Your buffer has to be in the DMA section of memory, as well as in a global scope.

```cpp
// buffer for sending data
uint8_t DMA_BUFFER_MEM_SECTION buffer[4];

// fill the buffer 0, 1, 2, 3
for(uint8_t i = 0; i < 4; i++)
{
    buffer[i] = i;
}

// transmit the data
spi_handle.DmaTransmit(buffer, 4, NULL, NULL, NULL);
```

```cpp
// receive 4 bytes. No callbacks or callback data.
uint8_t DMA_BUFFER_MEM_SECTION buffer[4];
spi_handle.DmaReceive(buffer, 4, NULL, NULL, NULL);
```

```cpp
// send and receive 4 bytes. No callbacks or callback data.
uint8_t DMA_BUFFER_MEM_SECTION tx_buffer[4];
uint8_t DMA_BUFFER_MEM_SECTION rx_buffer[4];

// fill the TX buffer 0, 1, 2, 3
for(uint8_t i = 0; i < 4; i++)
{
   tx_buffer[i] = i;
}

// transmit and receive
spi_handle.DmaTransmitAndReceive(tx_buffer, rx_buffer, 4, NULL, NULL, NULL);
```

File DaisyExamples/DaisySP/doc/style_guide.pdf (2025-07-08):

## Contents

Style Guide | 1
general notes | 2

## Style Guide

- overview
- general notes
– underscore separators
– tab size
– allman braces
– constant names
– trailing underscores for private member variables – inline markdown comments
– circular dependency avoidance
– enum definitions*
- Misc.
- Example
– daisysp module

* still being discussed, not strictly followed yet.

1

Overview

## general notes

Naming

Type Names

Type names should begin with a capital letter, and have a capital letter at the start of each word. Compound words (i.e. Id, Callback, etc.) should only have a single capital letter.

Function Names

Function names should begin with a capital letter, and have a capital letter at the start of each word. Compound words (i.e. Id, Callback, etc.) should only have a single capital letter.

Variable Names

all variable names use underscores as a separator, and contain only lower case letters.

trailing underscores for private member variables

to prevent name clashes with function arguments and/or names, trailing underscores will be used for private member variables.

ex.

private:
float foo_;

Constant Names

consts, whether class members or not, should be prefixed with, ‘k’ and use capital letters at the beginning of each word.

For example, float kConstantName = 1.542

enums

This may still change

for now, we’re putting enums outside the class with a MODULENAME prefix so that enums can be directly accessed without having to use the C++ syntax namespaces for them.

Enums are also currently not given type names to prevent issues when casting from standard types.

2

trailing commas are used at the end of every line of an enum definition including the last.

MODULENAME_ENUM_LAST is always used to have a valid “number of values” that can be used when dealing with the enum.

ex.

enum
{
MODULENAME_STATE_FOO,
MODULENAME_STATE_BAR,
MODULENAME_STATE_LAST,
};

This can be accessed simply by state = MODULENAME_STATE_FOO;

alternatively we may change this so that it doesn’t use a text-based namespace prefix, and move it within the class so that access would then be:

state = ModuleName::STATE_FOO;

This is still in discussion.

Giving enums named types is also a point of discussion, all though when moving between types it may not be very user friendly to have to:

// somewhere in init
uint8_t val = 0;

// somewhere being called periodically if (button1.rising_edge())
{
val = (val + 1) % OSC_WAVEFORM_LAST; osc.set_waveform(static_cast<osc_waveform>(val)); }

Misc

Tab Size

A tab = 4 spaces

allman braces

We use allman style braces for both libraries.

// So functions look like:
void do_something()
{
foo = bar;

3

}

// instead of:
void do_something() {
foo = bar;
}

this permits easier copy/paste when creating new modules, but also makes visual levels of indentation a little easier to see while working/reading code.

When used with if statements this also makes it very easy to comment out different logic statements, or even remove them for testing without having to worry about moving braces around.

inline markdown comments

Header files are parsed with a simple python script to generate reference documentation.

The parser checks for comments, and will generate markdown for any such lines.

There needs to be a blank comment line in between lines that require a line break in the output. Otherwise, consecutive lines will be treated as a single line in the markdown file.

ex.

// # Here's a new section
// With some text
//
// This will be on a newline,
// but this will be added to the previous.
//
// Put the following around code you wish to export into the documentation: // ~~~~
void some_function();
// ~~~~

circular dependency avoidance

We use both #pragma once and header guards to prevent circular includes, and similar issues that can arise without such a mechanism.

These should be used in all header files added to the libraries.

Naming convention for the header guards should be: DSY_MODULENAME_H where MODULENAME is the file/class name.

4

Example files

DaisySP module

Header:

// # Markdown Title
// Description
//
// Details

#pragma once

#ifndef DSY_MODULENAME_H

#define DSY_MODULENAME_H

namespace daisysp
{

enum state
{
MODULENAME_STATE_A,
MODULENAME_STATE_B,
MODULENAME_LAST,
};

class ModuleName
{
public:
ModuleName () {}
~ModuleName () {}

void Init();

float Process(const float &in);

inline void SetParam(const float &param) { param_ = param; }

void SetComplexParam(const float &complex_param);

private:

float param_;
float foo_bar_;
float a_, b_;

};

5

} // namespace daisysp

#endif // DSY_MODULENAME_H

Implementation:

#include <system_include.h> #include "modulename.h"

using namespace daisysp;

void ModuleName::Init()
{
// Set private members to defaults param_ = 0.0f;
a_ = 0.0f;
b_ = 1.0f;
// Do stuff
}

float ModuleName::Process(const float &in) {
// Do something and return the output. return (in * param_) + a_ - b_;
}

void ModuleName::SetComplexParam(const float &complex_param) {
a_ = complex_param;
b_ = 1.0f - complex_param;
}

6

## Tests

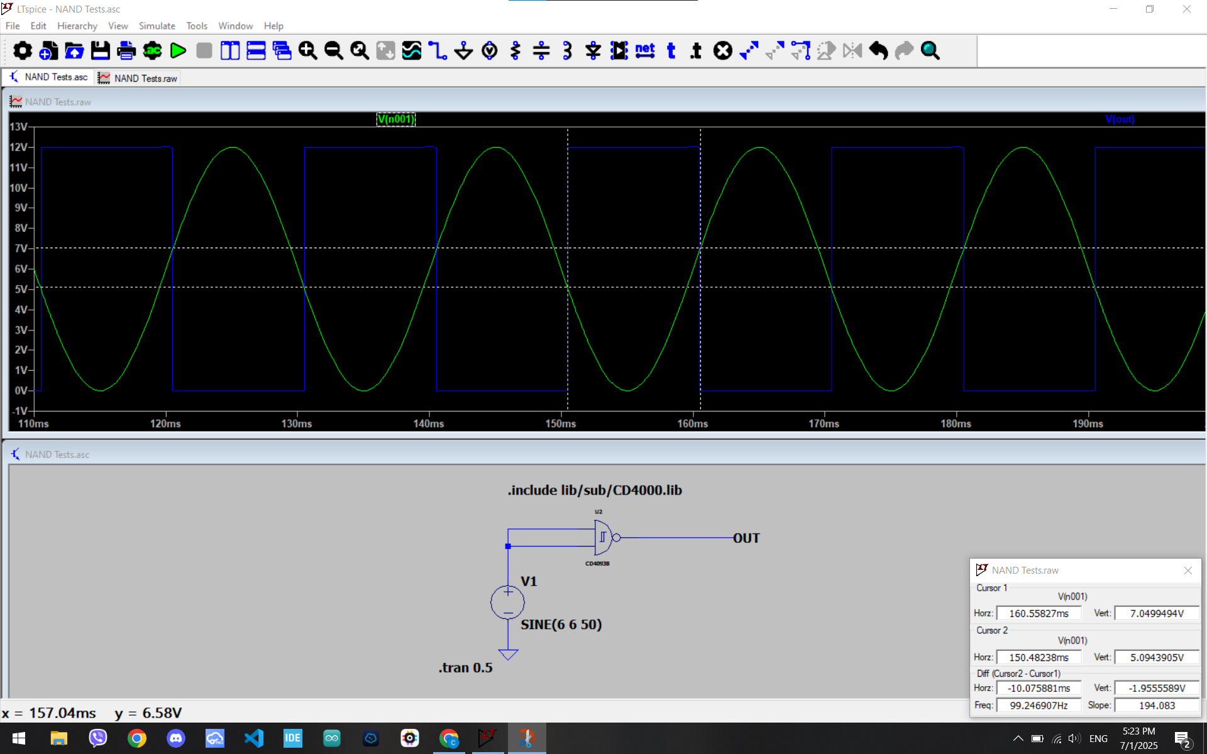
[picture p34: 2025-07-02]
Images/TestNandC4093Element.png

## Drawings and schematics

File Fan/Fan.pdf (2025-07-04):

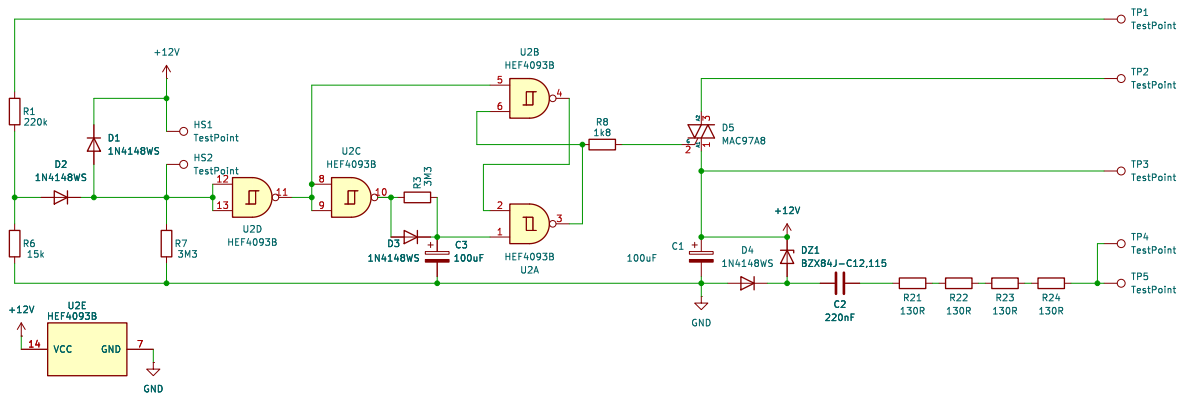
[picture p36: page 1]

TP1 TestPoint TP2 TestPoint TP5 TestPoint HS1 TestPoint HS2 TestPoint +12V

Id: 1/1 Title: File: Fan.kicad_sch Sheet: /

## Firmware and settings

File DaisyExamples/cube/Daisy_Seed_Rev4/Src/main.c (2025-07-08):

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

/* Includes ------------------------------------------------------------------*/
#include "main.h"
#include "adc.h"
#include "dac.h"
#include "dma.h"
#include "fatfs.h"
#include "i2c.h"
#include "opamp.h"
#include "quadspi.h"
#include "rng.h"
#include "sai.h"
#include "sdmmc.h"
#include "spi.h"
#include "tim.h"
#include "usart.h"
#include "usb_device.h"
#include "usb_otg_hs.h"
#include "gpio.h"
#include "fmc.h"

/* USER CODE BEGIN Includes */
#include <string.h>
#include "usbd_cdc_if.h"

/* USER CODE END Includes */


/* USER CODE BEGIN PV */
uint8_t mybuff[32];

/* USER CODE END PV */

void SystemClock_Config(void);
/* USER CODE BEGIN PFP */
void CheckClockFreq();

/* USER CODE END PFP */

/**
  * @brief  The application entry point.
  * @retval int
  */
int main(void)
{
  /* MCU Configuration--------------------------------------------------------*/

  /* Reset of all peripherals, Initializes the Flash interface and the Systick. */
  HAL_Init();

  /* Configure the system clock */
  SystemClock_Config();

  /* USER CODE BEGIN SysInit */
    CheckClockFreq();

  /* USER CODE END SysInit */

  /* Initialize all configured peripherals */
  MX_GPIO_Init();
  MX_DMA_Init();
  MX_ADC1_Init();
  MX_DAC1_Init();
  MX_FMC_Init();
  MX_I2C2_Init();
  MX_OPAMP1_Init();
  MX_QUADSPI_Init();
  MX_SAI1_Init();
  MX_SAI2_Init();
  MX_SDMMC1_SD_Init();
  MX_SPI1_Init();
  MX_TIM1_Init();
  MX_USART1_UART_Init();
  MX_I2C1_Init();
  MX_RNG_Init();
  MX_FATFS_Init();
  MX_USB_OTG_HS_USB_Init();
  MX_USB_DEVICE_Init();
  /* USER CODE BEGIN 2 */
    //    uint8_t buff[512];
    //    uint8_t check_buff[512];
    //    for(size_t i = 0; i < 512; i++)
    //    {
    //        buff[i]       = (uint8_t)(i & 0xff);
    //        check_buff[i] = 0;
    //    }
    //
    //    uint8_t status;
    //    size_t  byteswritten;
    //    if(f_mount(&SDFatFS, SDPath, 1) == FR_OK)
    //    {
    //        FIL f;
    //        if(f_open(&f, "myfile.bin", (FA_CREATE_ALWAYS | FA_WRITE)) == FR_OK)
    //        {
    //            f_write(&f, buff, 512, &byteswritten);
    //            f_close(&f);
    //        }
    //        if(f_open(&f, "myfile.bin", (FA_READ)) == FR_OK)
    //        {
    //            f_read(&f, check_buff, 512, &byteswritten);
    //            f_close(&f);
    //        }
    //    }
    //    // Check
    //    size_t fail_cnt;
    //    fail_cnt = 0;
    //    for(size_t i = 0; i < 512; i++)
    //    {
    //        if(check_buff[i] != buff[i])
    //        {
    //            fail_cnt += 1;
    //        }
    //    }
    //    if(fail_cnt)
    //    {
    //        asm("bkpt 255");
    //    }
  /* USER CODE END 2 */

  /* Infinite loop */
  /* USER CODE BEGIN WHILE */
    while(1)
    {
    /* USER CODE END WHILE */

    /* USER CODE BEGIN 3 */
    }
  /* USER CODE END 3 */
}

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
/* USER CODE BEGIN 4 */

void CheckClockFreq()
{
    PLL1_ClocksTypeDef clk1;
    PLL2_ClocksTypeDef clk2;
    PLL3_ClocksTypeDef clk3;
    HAL_RCCEx_GetPLL1ClockFreq(&clk1);
    HAL_RCCEx_GetPLL2ClockFreq(&clk2);
    HAL_RCCEx_GetPLL3ClockFreq(&clk3);
    if(clk3.PLL3_R_Frequency != 12288818)
    {
        __asm("bkpt 255");
    }
}

/* USER CODE END 4 */
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


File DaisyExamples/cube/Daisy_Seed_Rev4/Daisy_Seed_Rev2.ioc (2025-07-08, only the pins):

Mcu.UserName=STM32H750IBKx
PA0.Signal=SAI2_SD_B
PA1.Signal=SAI2_MCLK_B
PA11.Signal=USB_OTG_FS_DM
PA12.Signal=USB_OTG_FS_DP
PA2.Signal=SAI2_SCK_B
PA3.Signal=ADCx_INP15
PA4.Signal=COMP_DAC11_group
PA5.Signal=COMP_DAC12_group
PA6.Signal=ADCx_INP3
PA7.Signal=ADCx_INP7
PA8.Signal=S_TIM1_CH1
PA9.Signal=USB_OTG_FS_VBUS
PB0.Signal=OPAMP1_VINP
PB1.Signal=ADCx_INP5
PB11.Signal=I2C2_SDA
PB12.Signal=USB_OTG_HS_ID
PB14.Signal=USB_OTG_HS_DM
PB15.Signal=USB_OTG_HS_DP
PB5.Signal=SPI1_MOSI
PB6.Signal=USART1_TX
PB7.Signal=USART1_RX
PB8.Signal=I2C1_SCL
PB9.Signal=I2C1_SDA
PC0.Signal=ADCx_INP10
PC1.Signal=ADCx_INP11
PC10.Signal=SDMMC1_D2
PC11.Signal=SDMMC1_D3
PC12.Signal=SDMMC1_CK
PC4.Signal=OPAMP1_VOUT
PC5.Signal=OPAMP1_VINM
PC8.Signal=SDMMC1_D0
PC9.Signal=SDMMC1_D1
PD0.Signal=FMC_D2_DA2
PD1.Signal=FMC_D3_DA3
PD10.Signal=FMC_D15_DA15
PD11.Signal=SAI2_SD_A
PD14.Signal=FMC_D0_DA0
PD15.Signal=FMC_D1_DA1
PD2.Signal=SDMMC1_CMD
PD8.Signal=FMC_D13_DA13
PD9.Signal=FMC_D14_DA14
PE0.Signal=FMC_NBL0
PE1.Signal=FMC_NBL1
PE10.Signal=FMC_D7_DA7
PE11.Signal=FMC_D8_DA8
PE12.Signal=FMC_D9_DA9
PE13.Signal=FMC_D10_DA10
PE14.Signal=FMC_D11_DA11
PE15.Signal=FMC_D12_DA12
PE2.Signal=SAI1_MCLK_A
PE3.Signal=SAI1_SD_B
PE4.Signal=SAI1_FS_A
PE5.Signal=SAI1_SCK_A
PE6.Signal=SAI1_SD_A
PE7.Signal=FMC_D4_DA4
PE8.Signal=FMC_D5_DA5
PE9.Signal=FMC_D6_DA6
PF0.Signal=FMC_A0
PF1.Signal=FMC_A1
PF10.Signal=QUADSPI_CLK
PF11.Signal=FMC_SDNRAS
PF12.Signal=FMC_A6
PF13.Signal=FMC_A7
PF14.Signal=FMC_A8
PF15.Signal=FMC_A9
PF2.Signal=FMC_A2
PF3.Signal=FMC_A3
PF4.Signal=FMC_A4
PF5.Signal=FMC_A5
PF6.Signal=QUADSPI_BK1_IO3
PF7.Signal=QUADSPI_BK1_IO2
PF8.Signal=QUADSPI_BK1_IO0
PF9.Signal=QUADSPI_BK1_IO1
PG0.Signal=FMC_A10
PG1.Signal=FMC_A11
PG10.Signal=SPI1_NSS
PG11.Signal=SPI1_SCK
PG15.Signal=FMC_SDNCAS
PG2.Signal=FMC_A12
PG4.Signal=FMC_A14_BA0
PG5.Signal=FMC_A15_BA1
PG6.Signal=QUADSPI_BK1_NCS
PG8.Signal=FMC_SDCLK
PG9.Signal=SAI2_FS_B
PH10.Signal=FMC_D18
PH11.Signal=FMC_D19
PH12.Signal=FMC_D20
PH13.Signal=FMC_D21
PH14.Signal=FMC_D22
PH15.Signal=FMC_D23
PH2.Signal=FMC_SDCKE0
PH3.Signal=FMC_SDNE0
PH4.Signal=I2C2_SCL
PH5.Signal=FMC_SDNWE
PH8.Signal=FMC_D16
PH9.Signal=FMC_D17
PI0.Signal=FMC_D24
PI1.Signal=FMC_D25
PI10.Signal=FMC_D31
PI2.Signal=FMC_D26
PI3.Signal=FMC_D27
PI4.Signal=FMC_NBL2
PI5.Signal=FMC_NBL3
PI6.Signal=FMC_D28
PI7.Signal=FMC_D29
PI9.Signal=FMC_D30

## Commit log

2025-07-01 add tutorial schematic
2025-07-01 add values to Resistors, Transistors,
2025-07-02 Sw tests, working on fan schematic
2025-07-02 add imgs and files for reverse enginiering
    [Vent+1.SCHDOC, Vent+1nA.PCBDOC]
2025-07-03 add schematic fan
    [Fan.kicad_pcb, Fan.kicad_sch]
2025-07-03 update schematic, start working on PCB
    [Fan.kicad_pcb, Fan.kicad_sch]
2025-07-03 pcb and schematic for feedback
    [Fan.kicad_pcb, Fan.kicad_sch]
2025-07-03 generate gerbers for feedback
    [Fan-B_Cu.gbr, Fan-B_Mask.gbr, Fan-B_Paste.gbr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]
2025-07-04 pcb finnished, awaitng feedback
    [Fan-B_Cu.gbr, Fan-B_Mask.gbr, Fan-B_Paste.gbr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]
2025-07-07 gbrs, bom,
    [Fan-B_Cu.gbr, Fan-B_Mask.gbr, Fan-B_Paste.gbr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]
2025-07-08 add Daisy Examples
    [Button.fzz, Daisy_Seed_Rev4_Pinout.csv, Drum.fzz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]
2025-07-09 Strange, printline doesnt always work
2025-07-09 strange print problem, add HR202
2025-07-09 fix prints
2025-07-11 fix src/ and inc/ paths in makefile and separate code
    [main.cpp]
2025-07-15 PCB DOne

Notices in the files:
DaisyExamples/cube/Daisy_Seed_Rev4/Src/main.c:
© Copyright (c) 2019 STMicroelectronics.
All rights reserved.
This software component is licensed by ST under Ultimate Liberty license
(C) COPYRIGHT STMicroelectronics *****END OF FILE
